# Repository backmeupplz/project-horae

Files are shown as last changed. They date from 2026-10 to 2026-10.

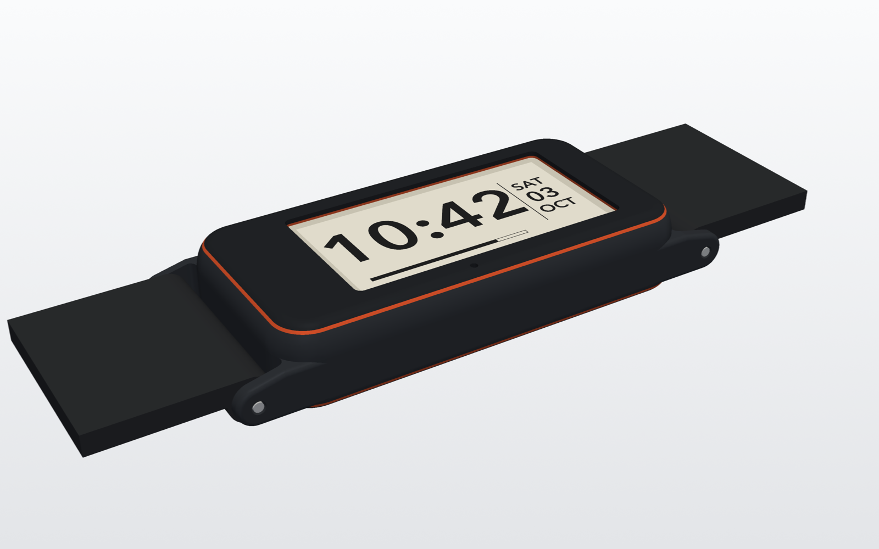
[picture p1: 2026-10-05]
media/2026-10-04/cad-assembled.png

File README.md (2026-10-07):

# Project Horae

A miniaturized successor to [Watchy](https://watchy.sqfmi.com/), the open-source ESP32 e-paper watch. It's rebuilt as thin as possible, in a slim band form factor (think Fitbit Charge, not a square).

Build log: **[projecthorae.com](https://projecthorae.com)**

## Build one
- [ORDER.md](ORDER.md): the JLCPCB order (files and every order-form setting), the shopping list with Canadian sources, and the totals
- [ASSEMBLY.md](ASSEMBLY.md): printing, a test-print checklist, bench bring-up, assembly, the dock wiring, and the firmware rules the hardware depends on
- [hardware/README.md](hardware/README.md): the board design, the pre-order review, what to verify at bring-up, and the cost

## Research
- [Displays](research/displays.md): bar-shaped e-paper and memory LCD panels
- [Batteries](research/batteries.md): thin LiPo, sodium-ion reality check, power budget
- [Electronics](research/electronics.md): EDA tools, fabs shipping to Vancouver, key ICs
- [CAD & printing](research/cad-tools.md): code-CAD and the headless Bambu A1 mini pipeline
- [Prototype v0](research/prototyping.md): breadboard kit, steps, charging
- [Build plan, rev A](research/build-plan.md): custom board straight away, order → solder → firmware → case → wear

## 3D explorer
The landing page's interactive model (`explorer/`) is generated from the case CAD and the KiCad board:
`.venv/bin/python cad/web.py` (needs Docker for KiCad and `npx` for gltf-transform). Re-run it after changing the CAD or the board.

## Printing (Bambu A1 mini, 0.4 nozzle, one filament per job)
- `cad/out/plates/petg.3mf`: both shells plus the dock's tray and lid, in PETG Basic or Matte. Use 0.1 mm layers **and a 0.1 mm first layer** (it is the skin over the watch's magnets), no supports.
- `cad/out/plates/tpu.3mf`: every seal and cushion plus the dock's grip pad, in TPU 90A (not 95A: twice as stiff) from the external spool, printed slowly. Give the bezel gasket 0.08 mm layers.
- Carbon-fibre version: print `petg-cf.3mf` (PETG-CF, hardened nozzle) and `petg-cf-set.3mf` (the colour-matched PETG parts) instead of `petg.3mf`.
- Per-part notes (orientation, layer heights, squeeze) are in `PRINT` in `cad/horae.py`, and a full `.venv/bin/python cad/horae.py` run prints them.

## Adding a timeline entry
The timeline is newest first. Add a new `<li class="entry">` block at the top of the `<ol class="timeline">` in `index.html`, and put its photos in `media/YYYY-MM-DD/`.

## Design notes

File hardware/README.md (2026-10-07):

# Horae rev A hardware

ESP32-S3 band watch board: **33.6 × 16.0 × 0.6 mm, 4 layers**. JLCPCB assembles it (Standard PCBA, top side only) in a
1-up 70 × 70 mm frame.
- **Case:** 35.6 × 18.0 × 6.80 mm, smaller than a Fitbit Charge 3 (38 × 18.3 × 11.8) in every direction. Two PETG shells
  click together with no glue (see `../cad/horae.py`).
- **Board fit:** the board sits 0.2 mm off every cavity wall, because JLC routes outlines to ±0.2 mm. Six crush ribs in the
  case centre it.

**Status (2026-10-06): pre-order review done, not ordered.**
- **Review:** four parallel reviews (schematic and parts, layout and fab files, size, sourcing) found 7 blockers. All are
  fixed and listed below.
- **Checks:** ERC 0. DRC 0 errors, 0 warnings, 0 unconnected. A probe of JLC's multilayer limits is clean: minimum
  clearance 0.110, track 0.100, hole-to-copper 0.235, copper-to-edge 0.201 mm.
- **Reproducible:** a fresh build gives the same board and CPL byte for byte.
- **Ordering:** [../ORDER.md](../ORDER.md). **Assembly and bring-up:** [../ASSEMBLY.md](../ASSEMBLY.md).

Everything here is generated from two files:
- [`design.py`](design.py), the netlist
- [`../spec.py`](../spec.py), the shared dimensions

## Rebuild
```sh
./build.sh       # ~6 min: schematic, ERC, placement, staged Freerouting, pours, DRC, STEP, gerbers, BOM/CPL, panel, renders
python3 cost.py  # live JLC parts (with JLC's attrition/minimums) + Standard PCBA fees -> out/cost.json; `cost.py 5` for 5 boards
```
It needs:
- Docker: it runs KiCad 10 from the official `kicad/kicad:10.0` image through `./kicad`.
- A Java 25 runtime.
- The Freerouting 2.4.1 jar in `~/.local`.

| File | What |
|---|---|
| `design.py` | parts, LCSC numbers, pin-to-net map |
| `gen_sch.py` | writes `horae.kicad_sch` (symbols joined by net labels) |
| `gen_pcb.py` | outline, stack, pinned and legalized placement (the build fails on any drift over 1 mm), net classes, keep-outs; exports the Specctra DSN |
| `stage.py`, `dsn_only.py`, `sesfix.py` | staged routing: touch first, then the e-paper bus, then the rest; deterministic (seeded UUIDs, one router thread) |
| `route.py` | imports the Freerouting session, pours GND, adds stitching and the RF via fence, removes unused escape vias |
| `fab.py` | `out/jlc-bom.csv` and `out/jlc-cpl.csv` (gerber coordinates, JLC rotation offsets) |
| `panel.py` | the 70 × 70 mm frame: `out/panel-gerbers.zip`, `out/jlc-cpl-panel.csv`, `out/panel-top.png` |
| `cost.py` | JLC cost estimate from the BOM |
| `lib/` | symbols, footprints and 3D models: LCSC-imported, TI/Espressif land patterns, Watchy's antenna |
| `rf/` | openEMS antenna model and match fitting |
| `out/` | schematic PDF, STEP, gerbers, BOM, CPL, panel, ERC/DRC reports, renders |

## Design summary
- **MCU:** ESP32-S3FN8 (8 MB in-package flash).
  - 40 MHz KYX crystal (12 pF, ±10 ppm) with Espressif's 24 nH series L on XTAL_P.
  - The exposed pad follows Espressif's land pattern: solid copper, nine 1.0 mm mask windows, 12 vias in the mask webs,
    and no vias in the paste.
  - **Timekeeping:** a 32.768 kHz crystal on GPIO15/16 drives the ESP32's own RTC, as on Watchy v3 and Yatchy, so there's
    no RTC chip. ±20 ppm is about 1 min/month before the phone sync corrects it. All four crystal load caps are 18 pF C0G.
  - **Antenna:** Watchy's meander IFA, trimmed 6.64 mm, ending 0.35 mm from the board edge. It is fed by a 50 Ω GCPW
    (0.15 mm track, 0.15 mm gap). Match **C11 0.5 pF / L3 0.8 nH**; C12 is not fitted and is the spare tuning spot.
  - **Antenna simulation (v4, this board):** S11 across 2.40–2.48 GHz is −8.8 to −14.2 dB in the case and −8.6 to
    −13.6 dB on the wrist, with a worst in-band loss of 0.78 dB.
  - The re-layout put ground closer to the feed, which lowered the resonance 0.6–0.8 %. So L3 went from 1.2 to 0.8 nH,
    the most robust match across JLC's parts. `rf/results/report_v4_trim6.64.txt` has the details.
- **Power:**
  - **Pogo pads:** 4 on the bottom for the charging/USB dock, whose spring pins reach them through the case floor. They are
    VBUS + D− on one side and GND + D+ on the other. ST's USBLC6-2P6 sits flow-through between the pads and the ESP32.
  - **TI BQ25101** linear charger (1.6 × 0.9 mm WCSP):
    - charges at 20 mA (6.8 kΩ ISET, 0.5C for a 40 mAh cell), with TI's ISET RC (2.7 kΩ + 10 nF) for currents under
      50 mA;
    - 4.7 µF/25 V on IN and 1 µF on OUT, both at the chip;
    - ≤ 75 nA battery drain.
    - The IN pin is rated 30 V, but the USBLC6 clamps VBUS from about 6 V, so the input is 5 V only.
  - **TI TPS62840** buck:
    - 60 nA quiescent, 3.3 V set by a 267 kΩ VSET resistor (TI's window is 256–278 kΩ);
    - 2.2 µH LSCND1608 inductor (1.3 A saturation, 0.2 Ω, 0.8 mm).
  - **Battery voltage:** a 10 MΩ / 10 MΩ ±1 % divider (0.2 µA) with 100 nF at the ADC. Calibrate each board at the
    4.20 V end of charge.
  - **Soldered parts:** the battery goes to a **square + pad (TP5)** and a **round − pad (TP6)** on the bottom; the motor
    to 1.5 mm pads.
- **Sensors:** ST LIS2DUX12 accelerometer (pedometer at 2.7 µA, tap, wake-up, 6D, ML core).
  - **I²C:** address **0x19**, on GPIO8 (SDA) / GPIO9 (SCL) with the ESP32's internal pull-ups, so 100 kHz.
  - **Interrupts:** INT1/INT2 on GPIO10/11.
  - **Layout:** nothing on any layer under it (ST TN0018).
- **Display:** GDEM0097T61 into a Hirose FH34SRJ-18S.
  - **Connector:** its slot and fitting nails face the ribbon's U-bend at −X, and **pad = 19 − display pin**.
  - **Booster:** Good Display's reference (p.20) in tiny packages:
    - 47 µH Sunlord SWPA3010S (3 × 3 × 1.0 mm) with 10 µF at its input;
    - Nexperia PMZ390UN switch (30 V);
    - 3× Nexperia PMEG3002AEL Schottky (30 V, about 6× less leakage than the PMEG3005EL);
    - 2.2 Ω sense;
    - 2.2 µF/25 V on the ±15–20 V rails (0402 parts lose about 90 % of their capacitance there) and 1 µF/25 V on the rest.
- **Touch:** 4 capacitive electrodes (4.0 × 1.6 mm) along the long edges, on touch channels GPIO1–4, each through a
  510 Ω series resistor at the chip. No buttons.
  - On every layer, no other trace and no ground pour come within 0.5 mm of an electrode.
  - The electrodes are well below Espressif's recommended size (8 mm+), so measure raw counts in the closed case first
    (bring-up checks).
- **Haptics:** 6 mm coin ERM (Vybronics VC0625B001L, 2.5 mm, 10 mm leads) on a PMZ390UN low-side switch, with a
  PMEG3002AEL flyback diode. It is rated 2.5 V, so firmware drives it with PWM.
- **Mic:** LMD2718T261 top-port PDM mic: DATA on GPIO38, CLK on GPIO39, and powered from GPIO40 (0 µA when off).
  - The ROM drives GPIO40 high in USB-OTG download mode, so it may only be the mic's supply.
  - Burn `DIS_USB_OTG_DOWNLOAD_MODE` at the first flash.
- **Height:** the tallest parts are J1 (1.0 mm, 1.1 max) and L4 (1.0 mm). Then come the mic (0.9, 1.0 max), the ESP32
  (0.885), L5 (0.8) and the accelerometer (0.74). The display sits 1.05 mm above the board.

### GPIO plan
| Side of U1 | GPIO | Use |
|---|---|---|
| facing the antenna (pins 6–14) | 1, 2, 3, 4 | touch DOWN, BACK, MENU, UP (each through 510 Ω) |
| | 5 | vibration motor (PWM) |
| | 6 | charger CHG (open drain, low = charging: wakes the watch on the dock) |
| | 7 | battery ADC (ADC1 channel 6) |
| | 8, 9 | I²C SDA, SCL (accelerometer, 0x19) |
| facing the display connector (pins 15–27) | 10, 11 | accelerometer INT1, INT2 |
| | 12, 13, 14, 17, 18, 21 | display BUSY, RES, DC, CS, SCK, MOSI |
| | 15, 16 | 32.768 kHz crystal |
| | 19, 20 | USB D−, D+ (dock pads, through the USBLC6) |
| bottom (pins 43–45) | 38, 39, 40 | mic DATA, CLK, power |
| test pads (bottom) | 0, 43, 44, EN, 3.3 V | BOOT, TXD0, RXD0, reset, supply |

Every display, I²C, touch and wake line is on an RTC GPIO (0–21), so the ULP core can redraw the minutes without waking
the main CPU (Yatchy's biggest battery win). The ULP bit-bangs I²C: its hardware I²C pins are GPIO0–3.

## Pre-order review (2026-10-06): what changed
- **Blockers fixed:**
  - **J1 faced the wrong way.** The FH34SRJ's slot is on the fitting-nail side, so the ribbon couldn't reach it. J1 is
    turned around with its pins remapped. It also moved 1.7 mm toward +X, because Good Display's bend rule (R > 0.5 mm)
    with the 11.18 mm tail needs that much room.
  - **CPL:** it was relative to the board centre, while the gerbers use absolute coordinates, so every part would have
    landed about 141 mm off. U4 also needed a rotation offset; the CPL now has offsets for U4 and L4.
  - **WCSP lands:** the U2/U3 ball pads (0.185–0.2 mm, mask = pad) were below JLC's minimum. They are now TI's 0.23 mm
    NSMD lands with 0.25 mm square paste.
  - **Touch:** foreign traces ran under the electrodes on the inner and bottom layers.
  - **RF:** the RF match pads were 0.07 mm apart, which would merge the solder mask and tombstone L3.
  - **Thermal vias:** the ESP32's exposed pad had open vias inside the paste.
  - **Panel:** JLC Standard PCBA needs a panel of at least 70 × 70 mm. JLC's own 2 × 4 panel would have meant paying for
    16 assembled boards, so `panel.py` makes a 1-up frame.
- **Should-fix items done:**
  - **Vias:** all are now 0.45/0.2 mm. 0.4 mm pads cost about $36 more per order and triggered 4-wire testing.
  - **Supplies:** 0.2–0.3 mm traces; VDD3P3 on the top layer with no vias.
  - **Decoupling:** every cap within 1 mm of its pin, with new caps at VDD3P3_CPU, VDDA, the booster input and the charger
    output.
  - **Crystals:** on the top layer at their pins, with nothing underneath.
  - **USB ESD:** flow-through.
  - **Mic:** its pins are swapped so the ROM can't back-drive it during flashing.
  - **Lower-leakage diodes, and rail caps that keep their value at 20 V.**
  - **Genuine ST USBLC6.**
  - **Parts with better stock:** the original Sunlord inductor, plus ±1 % 10 MΩ and 510 Ω resistors with no 6,000-piece
    minimums.
  - **Silkscreen:** pin-1 and cathode marks for JLC's placement check.
  - **Paste:** reduced on the FPC connector. Thermal spokes on the non-critical 0201s against tombstoning.

## Verify at bring-up
1. **RF:** the in-case and on-wrist responses sit about 100 MHz apart, so a ±3 % resonance error costs about 4 dB at one
   band edge.
   - The steel spring bar is part of the antenna's environment. Keep it within ±1 mm of 2.15 mm past the case end, or
     re-run `rf/`.
   - Verify on the first boards with a VNA through a pigtail at the C11 pad (cut the trace to U1). Close the case and
     measure with the strap on, off and on a wrist, then retune C11/L3; C12 is the spare.
   - A bare board always reads high, so test it in the case.
2. **Touch:** read raw counts and noise in the closed case before relying on touch as the only input.
3. **Booster:** SSD1680's current-sense trip on RESE isn't published, so L4's saturation margin (0.22 A rated, 0.35 A
   typical) is unknown. Probe RESE (current = V / 2.2 Ω) and watch the VGH ramp.
4. **Crystals:**
   - The 40 MHz must be within ±10 ppm: trim C1/C2 with a TX tone if not.
   - Check that the 32 kHz crystal starts. Its 70 kΩ resistance is at Espressif's limit, and the firmware falls back to
     the internal RC clock.
5. **Charger:** it can't run the board without a cell, and its 10-hour timer stops charging if the watch stays awake on
   the dock. Bring the board up from a bench supply on TP5/TP6, and deep-sleep while docked.
6. **JLC preview:** order with "Confirm Parts Placement" and check every pin-1 dot and cathode bar against the
   silkscreen, especially U1–U4, U6, J1, Q1/Q2, D1–D4, MIC1 and Y1.
7. **Recovery without buttons:** EN, BOOT (GPIO0), TXD0/RXD0 and 3.3 V are on bottom test pads, and USB is on the dock
   pads.

## Cost (JLC Standard PCBA, live 2026-10-06; `python3 cost.py`)
| Item (USD) | 2 boards | 5 boards |
|---|---|---|
| Bare PCB: 5 frames, 4 layers, 0.6 mm, ENIG, JLC04061H-3313 stack-up (impedance control not needed), 0.45/0.2 vias, plugged | 46.20 | 46.20 |
| PCBA setup 25.56 + stencil 8.21 + 33 feeders × 1.53 + fixtures 16.42 + X-ray + placement confirmation and packing | 118.03 | 122.13 |
| Parts, with JLC's attrition and minimum quantities | 30.42 | 62.93 |
| Joints (about 230 per board × $0.0016) | ~0.75 | ~1.85 |
| **Subtotal** | **≈ 195** | **≈ 233** |
| DHL Express (2–4 business days); Global Standard is capped at $99 orders | 31.23 | 31.23 |

- **Import:** duty 0 % (HS 8534.00.00). GST + BC PST 12 % is collected at delivery, plus DHL's CAD 18 clearance fee.
  There is no DDP option for Canada.
- **Fees:** on Standard PCBA every BOM line pays the $1.53 feeder fee, basic or extended alike. JLC has no basic or
  preferred 0201 parts, so swapping parts for basic ones saves nothing here; only fewer lines do.
- **Pre-buy the ESP32-S3FN8:** JLC has 602 in stock and 0 at LCSC. Buy 5–10 into your JLC parts inventory before
  ordering.

## Battery and motor (bought separately, soldered: 4 joints)
- **Cell:** a 3.0 mm LiPo with protection (PCM), at most 21.4 × 16.0 × 3.25 mm including the PCM. The PCM end may be up
  to 3.5 thick and 2.5 long.
  - Buy cells no thicker than 3.05 mm, and measure them on arrival: thickness tolerance is often ±0.3.
  - Real capacity in this pocket is **40–55 mAh** (301518 / 301519 / 301520 class).
  - They ship with two bare wire leads (no plug): trim them, then red to + and black to −.
  - **Thinner option:** a bare 2.5 mm cell (LP251320, 40 mAh, buyable at quantity 1) would make the case 6.30 mm. It would
    need cell protection on the board and an RF retune.
- **Motor:** Vybronics VC0625B001L, a 6 × 2.5 mm brushed coin ERM with 10 mm leads (Digi-Key 1670-VC0625B001L-ND). No
  6 mm motor with spring contacts exists off the shelf.
- **Why not a plug:** a JST SH socket, the plug and its lead slack need about 2 mm more case length, and the board's bottom
  side would need assembly too. Two pads take seconds to solder.

## Charging dock (bought parts; the tray, lid and grip pad print with the case)
- **Spring pins:** 4 Mill-Max 0955-0-15-20-71-14-11-0 (plus 2 spares). Docked, each presses about 42 g on its pad.
- **Magnets:** 4 × 3 × 3 mm N52 in the dock; the case holds 2 × 3 × 1 mm N52.
  - Placed end for end, the watch is pushed off, so VBUS never lands on GND.
  - They hold 1.9× the pins' spring force.
  - The case's magnets click into the bottom shell from the inside, behind a 0.1 mm skin, so lifting the watch off can't
    pull them out.
- **USB-C:** [Adafruit 6050](https://www.adafruit.com/product/6050) sunken breakout. Its 5.1 kΩ CC pull-downs make any
  USB-C charger give 5 V, and D+/D− are broken out for flashing.
- **Wire:** 2–3 cm each of 30 AWG for VBUS, GND, D+ and D− (twist D+ with D−). These 4 wires are the dock's only soldering.
  Wiring table: [../ASSEMBLY.md](../ASSEMBLY.md).

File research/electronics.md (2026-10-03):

# Electronics: EDA, fabs, key ICs

_Researched 2026-10-03. Items marked "unverified" still need a check._

## Starting point: Watchy's KiCad files
Watchy's hardware lives in **[sqfmi/watchy-hardware](https://github.com/sqfmi/watchy-hardware)** (MIT), not in the firmware repo `sqfmi/Watchy`.
- **Format:** KiCad 7. KiCad 10 opens it fine.
- **Board:** 4 layers.
- **Contents:** STEP models, gerbers, BOM.
- **v3 BOM:**
  - Bare ESP32-S3 (QFN56), 32 kHz crystal, PCB antenna
  - BMA423 accelerometer, TP4054 charger, RT9080 LDO
  - Micro-USB, pager motor
  - No external RTC IC

## EDA tools an agent can drive
| Tool | License | Scriptable | Headless render | Maturity |
|---|---|---|---|---|
| **KiCad 10** + `kicad-cli` | GPL | Runs ERC/DRC (JSON), gerbers, drill, pick-and-place, BOM, STEP and SVG. Project files are plain-text S-expressions an agent can edit. | ✅ `kicad-cli pcb render` | Production |
| KiCad IPC API | GPL/MIT | Needs the GUI running. Headless use arrives in KiCad 11. | ❌ | Early |
| [atopile](https://pypi.org/p/atopile) | MIT | `.ato` language that picks JLC parts and generates the KiCad PCB | via KiCad | Pre-1.0 |
| [tscircuit](https://docs.tscircuit.com/) | MIT | React/TS with a built-in autorouter. Exports a KiCad project. | ✅ | Unstable |
| [SKiDL](https://pypi.org/project/skidl/) | MIT | Python netlists only. KiCad 10 support unverified. | ❌ | Stable, narrow |
| [Freerouting](https://github.com/freerouting/freerouting/) | GPL | `java -jar freerouting.jar -de board.dsn -do board.ses` | ❌ | Mature |
| Quilter | SaaS | Upload KiCad, get AI layout back. Web only. | ❌ | Unproven on RF |
| Flux.ai / EasyEDA Pro / JITX | SaaS / freeware / commercial | Browser-bound or unclear | ❌ | Wrong fit |

## Fabs that ship to Vancouver
| Fab | Thin rigid | Flex / rigid-flex | HDI / fine pitch | Assembly |
|---|---|---|---|---|
| **[JLCPCB](https://jlcpcb.com/capabilities/pcb-capabilities)** | 2-layer 0.4 mm. 4-layer: 0.8 mm listed, 0.6 mm reportedly possible (unverified). | Flex: 1–2 layers, from $2–25 per 5. No rigid-flex online. | 1–3 step HDI, via-in-pad, 01005, 0.35 mm pitch | Standard PCBA needs a 70×70 mm panel |
| **PCBWay** | 0.4 mm+ | Flex and **rigid-flex** | ✅ | ✅ |
| NextPCB | ✅ | Flex and rigid-flex | ✅ | Free PCBA promo for 1–10 pcs |
| Elecrow / Seeed Fusion | ✅ | Flex and rigid-flex | limited | Slower (7–25 days) |
| OSH Park (US) | 4-layer only at 1.6 mm | Flex suspended | ❌ | ❌ |
| Candor (Toronto) | ✅ | Rigid-flex, HDI | ✅ | Partners. Premium price |
| Bittele/7pcb (Markham) | partners | partners | ✅ | Turnkey, ~6 days |

**Estimated cost:** 5 assembled small 4-layer boards at JLC come to **≈ USD 60–150** before shipping. Shipping is DHL, 3–6 days, ~$20–35. (Estimate, not a quote.)

**Import costs into BC (2026):**
- Tax: PCBs aren't on Canada's China surtax list ([SOR/2024-187](https://laws-lois.justice.gc.ca/eng/regulations/SOR-2024-187/page-1.html)). Expect **GST 5% + PST 7%** plus brokerage.
- Brokerage: DHL charges about CAD $10–20.
- De minimis from China is only about CAD $20, so assume every order is taxed. JLC's DHL DDP option roughly breaks even.
- US shipments (OSH Park) are tax-free under CAD $40 thanks to CUSMA.

## Key ICs
| | ESP32-S3 | ESP32-C6 | nRF52840 | nRF54L15 |
|---|---|---|---|---|
| Sleep | ~7 µA deep sleep (14+ µA on real boards) | ~7 µA | 2.35 µA System ON | 2.9 µA ON / 0.7 µA OFF |
| Radio | Wi-Fi 4 + BLE 5 | Wi-Fi 6 + BLE 5 + 802.15.4 | BLE 5, Thread | BLE 6, Thread |
| Smallest module | S3-MINI-1 15.4×20.5×2.4 | C6-MINI-1 13.2×16.6×2.4 | MDBT50Q 10.5×15.5×2.05 | **Fanstel BC15P 6.0×6.5×2.0** |
| Watchy firmware | ✅ | mostly | ❌ rewrite | ❌ rewrite (Zephyr) |

- **RTC:** RV-3028-C7 (~45 nA), only if the internal RTC drifts too much.
- **Accelerometer:** BMA423 or BMA456 (both have a pedometer). LIS2DW12 draws less but has no pedometer.
- **Charger / PMIC:** TP4054 (simplest), BQ25125 (wearable PMIC), nPM1300 (pairs with nRF).
- **Haptics:** coin ERM motor plus a MOSFET, or DRV2605L plus an LRA.

## Recommendation
1. **EDA:** fork `watchy-hardware` into KiCad 10.
   - The agent edits the S-expression files directly.
   - A Makefile runs `kicad-cli` for ERC/DRC, renders, STEP and fab outputs.
   - Freerouting handles non-RF nets.
2. **Fab:** JLCPCB, 4-layer at 0.6–0.8 mm, Standard PCBA, panelized, shipped by DHL. Get rigid-flex quotes from PCBWay or NextPCB once the design settles.
3. **ICs:** v1 keeps the bare ESP32-S3, which is the lowest risk because it reuses the schematic, RF section and firmware. Evaluate an nRF54L15 module for v2.

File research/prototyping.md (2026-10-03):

# Prototype v0: no factory

_Planned 2026-10-03. Prices are approximate, in USD._

Goal: get every function working on the desk first, using off-the-shelf boards and hand wiring. We miniaturize the PCB once the behaviour is right.

## Step 0: the Watchy we already have
The Watchy is already a working ESP32 + e-paper + accelerometer board. Use it for firmware experiments while the parts ship.

## Step 1: XIAO carrier PCB, hand-soldered
Skip the breadboard. Design a small 2-layer carrier board in KiCad, about 25×40 mm, with:
- castellated pads for a XIAO module. ESP32S3 and nRF52840 Sense share a footprint, so the chip decision becomes a module swap.
- the 0.97" display's FPC connector plus its booster circuit, using the Watchy / Good Display reference design.
- 4 buttons, a motor MOSFET, and LiPo pads.

Every part is hand-solderable: 0603/0805 passives, SOT-23, a 0.5 mm FPC connector (drag-solder with flux), and the castellated module. The Sense's onboard IMU avoids hand-placing a 2×2 mm LGA accelerometer.

Order bare boards from OSH Park (no duty, slow) or JLC (fast). Print a build123d case around the board.

### v0 bill of materials (hand-soldered, 2-layer 0.8 mm carrier)
| Block | Part | Package | Notes |
|---|---|---|---|
| MCU | Seeed [XIAO ESP32S3](https://www.seeedstudio.com/XIAO-ESP32S3-p-5627.html) / [XIAO ESP32C6](https://www.seeedstudio.com/Seeed-Studio-XIAO-ESP32C6-p-5884.html) | castellated 21×17.8 | Same footprint, both have Wi-Fi + BLE, so we test both |
| Display | Good Display [GDEM0097T61](https://www.good-display.com/product/486.html) | 30×14.15×1.0, FPC 18p **0.5 mm**, 0.30 mm with stiffener | [datasheet](https://v4.cecdn.yun300.cn/100001_1909185148/GDEM0097T61-V1.1%20new.pdf) |
| Display socket | Hirose **FH34SRJ-18S-0.5SH(50)** | 18p 0.5 mm ZIF, **1.0 mm tall**, top+bottom contact | The ribbon plugs in, so we never solder the ribbon itself |
| E-paper booster | Q1 AO3400A (Watchy) or Si1308EDL (GD ref), D1–D3 MBR0530, L1 47 µH ≤1.2 mm ([PNLS3012-470M](https://jlcpcb.com/partdetail/DMBJ-PNLS3012470/C2849443) or Murata LQH3NPN470NJ0L), R1 1 MΩ, R2 2.2 Ω, 7× 1 µF/25 V, 2× 4.7 µF/25 V | SOT-23, SOD-123, 3×3, 0603/0805 | Copied from the datasheet's typical circuit (p.20) |
| RTC | NXP PCF8563T + 32.768 kHz crystal (hand-solder) or RV-3028-C7 (better, needs hot air) | SO-8 / 3.2×1.5 | The XIAO's internal RC clock is too inaccurate for a watch (verify whether a 32 kHz crystal is fitted) |
| Accelerometer | Bosch BMA423 (same as Watchy) | LGA-12 2×2 | Can't be soldered with an iron: use hot air or a hot plate, or have JLC place just this part. Optional in v0 |
| Buttons | 4× Panasonic EVQ-PUC02K (same as Watchy) | side-push, 1.35 mm tall | – |
| Haptics | 8 mm coin ERM motor + AO3400A + diode | – | – |
| Battery | 3.7 V LiPo **301525** (~3×15×25, ~110 mAh) with PCM | soldered leads | 15 mm wide, narrower than the XIAO |
| Power | 47–100 µF bulk cap at the battery, 2× 1 MΩ divider for battery voltage | 1206 / 0603 | Wi-Fi bursts draw ~300 mA from a tiny cell |
| Power meter | [Nordic PPK2](https://www.nordicsemi.com/Products/Development-hardware/Power-Profiler-Kit-2) | – | Optional, ~$100 |

### Size estimates
| | L × W × T (mm) | What sets each dimension |
|---|---|---|
| [Fitbit Charge 6](https://store.google.com/product/fitbit_charge_6_specs) | 36.7 × 23.1 × 11.2 | target |
| **v0** XIAO carrier | **~40 × 21 × 10–11** | L: display + walls + USB-C. W: XIAO 17.8 + walls. T: 0.6 lip + 1.0 display + ~2.6 XIAO (USB-C end ~4.3, unverified) + 0.8 PCB + 3.3 battery + 1.0 floor |
| **v1** custom 4-layer, bare ESP32-S3/C6 | **~34 × 18 × 7** | L: 30 mm display + walls + antenna keep-out. T: 0.6 + 1.0 + 1.2 tallest part + 0.8 PCB + 2.6 battery (2.4 mm cell + swelling) + 0.8 |
| v1 with nRF54L15 (no Wi-Fi) | ~32 × 17 × 6 | same, with a ~1.5 mm, 50 mAh cell |

## Step 2–3: iterate
Revise the board and case together until everything works and fits on a wrist.

## Step 4: miniaturize
Make a custom 4-layer board with a bare chip and factory assembly. This is the expensive step, so it waits until v0 works.

## Charging
- **Prototype:** the XIAO's own USB-C.
- **Final watch:** a 4-pin magnetic pogo connector on the back (5V, GND, D+, D−). It gives charging *and* USB flashing at zero added height, and both chips have native USB.
- **Why not USB-C:** a USB-C socket is ~3.2 mm tall and ~9 mm wide, so it sets a floor on the case's edge thickness and is an ingress point.

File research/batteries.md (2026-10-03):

# Slim batteries

_Researched 2026-10-03. Power numbers are estimates. Measure them with a PPK2 on the first prototype._

**Bottom line:** use a stock **2.4–3.0 × 20 × 30 mm LiPo pouch, 100–130 mAh**. The MCU choice matters more than the chemistry. **Sodium-ion is not an option yet** (see below).

## Power budget (estimates)
The original Watchy gets 5–7 days on 200 mAh ([docs](https://watchy.sqfmi.com/docs/battery-life)), which works out to about 1.2–1.7 mA average. There is a lot of room to improve.

| | ESP32-S3 | nRF52840 |
|---|---|---|
| Sleep floor (board) | ~15–25 µA | ~5–15 µA |
| Wake every minute | reboots from deep sleep: ~75 µA avg | no reboot: ~2 µA |
| E-paper partial refresh | ~5 µA avg | same |
| BLE sync now and then | ~20–60 µA | ~10–30 µA |
| **Total** | **~3–4 mAh/day** | **~0.6–1.2 mAh/day** |
| 1 week (×1.5–2 margin) | 35–50 mAh | 10–15 mAh |
| 2 weeks | 70–100 mAh | 20–35 mAh |

The ESP32-S3 column assumes well-optimized firmware. Stock Watchy-style firmware draws about 10× more. On the nRF52840, the VDDH pin takes LiPo voltage directly, so no LDO is needed.

## Options
Wh/L is our own calculation: nominal V × mAh ÷ volume.

| Chemistry | Example | mm | mAh | Wh/L | Where | Price |
|---|---|---|---|---|---|---|
| LiPo + PCM | [Adafruit 1317](https://www.adafruit.com/products/1317) | 3.8×19.75×26 | 150 | ~285 | Adafruit / Digi-Key CA | US$5.95 |
| LiPo + PCM | [Adafruit 1570](https://www.adafruit.com/product/1570) | 3.8×11.5×31 | 100 | ~275 | Adafruit | US$5.95 |
| LiPo cell | [EEMB LP302030 / LP242030](https://www.sos.sk/novinky/pdf/2587_eemb-lipol-overview-en-1.pdf) | 3.0 / 2.4×20×30 | 130 / 100 | ~260 | EEMB, Amazon | ~$2–6? |
| Generic LiPo | AliExpress 302030 / 402030 | 3–4×20×30 | 130–200 | ~250–300 | AliExpress | $2–5 |
| Ultra-thin LiPo | [Grepow GRP0849049](https://grepow.com/shaped-battery/ultra-thin-battery.html) | 0.85×49×49 | 140 | ~260 | Grepow samples | ask |
| Ultra-thin LiPo | PowerStream | 0.5–2 thick | ~2 mAh/cm² @0.5 mm | ~150 | powerstream.com | from ~$8 |
| Ceramic Li-ion | NGK EnerCera EC382704P-T | 0.45×38×27 | 27 | ~220 | Japan only | ? |
| Curved LiPo | [Grepow 3020035](https://grepow.com/battery-news/grepow-curve-shaped-lipo-battery-3-8V-200mah-3020035.html) | ~3×20×35 | 200 | ~300 | custom, MOQ | ? |
| Li-ion coin | LIR2032 | Ø20×3.2 | 40 | ~150 | Amazon.ca | ~$2 |
| Thin-film / solid state | TDK CeraCharge, Ilika, ITEN | ~1 thick | 0.1–0.25 | ~10 | samples | only fits RTC backup |
| **Sodium-ion** | 18650 (smallest retail size) | Ø18×65 | ~1500 | 250–375 | B2B | **no wearable cells** |
| Si-C anode | LeydenJar Silyte | ? | ? | 800+ claimed | OEM eval only | n/a |

## Sodium-ion: an honest no
- No thin pouch or coin Na-ion cells are commercially available. Retail starts at 18650 size ([overview](https://en.wikipedia.org/wiki/Sodium-ion_battery)).
- Energy density is lower than LiPo, and packaging overhead would hurt small cells even more.
- Voltage swings from about 4.0 V down to 1.5 V. The ESP32 needs ≥3.0 V, so we'd need a buck-boost converter, which costs quiescent current and board area.
- It needs a charger with a Na-specific 3.9–4.0 V limit, because a 4.2 V Li charger overcharges it.
- Its strengths (cold performance, 0 V storage, grid-scale cost) don't matter on a wrist. Revisit around 2028.

## Other categories
- **Ultra-thin under 1 mm:** real cells, about 260 Wh/L at 0.85 mm. Stock sizes don't fit a band, so it's a custom Grepow order by email.
- **Curved / flexible:** Jenax J.Flex is still at demo stage and Panasonic's flexible cell was never sold at retail. Grepow curved cells are custom-only. Not for v1.
- **Coin cells:** 3.2 mm thick and low capacity, worse than a pouch on every axis.
- **Silicon-carbon:** expect +10–15% capacity per volume once hobby sizes appear.

## Mechanical and charging
- **Swelling:** leave 8–10% of the cell thickness as clearance, about 0.3 mm on a 3 mm cell.
- **PCM:** adds 3–5 mm of length and 1–3 mm of local thickness. We can buy a bare cell instead and put the protector (DW01 / FS312 class) on our PCB. That's thinner, but needs a fuse and careful testing.
- **Charging:** magnetic pogo pins plus a linear charger at ≤0.5C (MCP73831 / BQ25101). Qi adds a coil and ferrite (~1 mm) plus heat, and is oversized at this power level.
- **Shipping:** LiPo ships by ground. Digi-Key CA and Adafruit ship to Vancouver.

## Recommendation
1. **nRF52840 + 100–130 mAh 2.4–3.0 mm cell:** about 3–6 weeks. A ~50 mAh cell 1.5 mm thick would still give about 2 weeks.
2. **ESP32-S3 + the same cell:** about 1–2 weeks, and only with optimized firmware.
3. **Later revision:** a custom Grepow 1.0–1.5 × 22 × 40 mm cell once the enclosure is frozen.

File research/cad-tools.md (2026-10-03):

# CAD tools & print pipeline

_Researched 2026-10-03. Items marked "verify" are unconfirmed._

**Primary stack: [build123d](https://build123d.readthedocs.io/).** It's Python and B-rep, so we get real fillets and STEP output. It imports the KiCad board STEP for interference checks and installs with plain pip. **Fallback: OpenSCAD snapshot (Manifold)** for quick mesh parts and one-line PNG renders.

| Tool | License | Lang | STEP | STL/3MF | KiCad STEP import | Headless PNG | Verdict |
|---|---|---|---|---|---|---|---|
| **build123d** | Apache-2.0 | Python (OCCT) | ✅ | ✅/✅ | ✅ `import_step()` | via pyvista | **Primary** |
| CadQuery 2.5 | Apache-2.0 | Python (OCCT) | ✅ | ✅/✅ | ✅ | via pyvista | Fine, slower releases |
| OpenSCAD snapshot | GPL-2 | DSL | ❌ | ✅/✅ | ❌ (convert to STL) | ✅ built-in | **Fallback** |
| FreeCAD 1.x | LGPL | Python | ✅ | ✅ | ✅ | hard headless | Heavy |
| Zoo / KCL | proprietary, metered | KCL | ✅ | ✅ | verify | cloud | Ideation only |
| Onshape | free = public docs | FeatureScript | ✅ | ✅ | ✅ | API | Cloud-only |
| Fusion 360 | free personal | Python | ✅ | ✅ | ✅ | ❌ no headless | Unsuitable |

Agent tooling worth borrowing: [earthtojake/text-to-cad](https://github.com/earthtojake/text-to-cad) (build123d skills for Claude Code), [build123d-mcp](https://pypi.org/project/build123d-mcp/).

## Install
```sh
python3 -m venv ~/horae-venv && source ~/horae-venv/bin/activate
pip install build123d pyvista
brew install --cask openscad@snapshot kicad bambu-studio
```

## PCB → CAD
```sh
kicad-cli pcb export step --subst-models -o board.step board.kicad_pcb   # --subst-models or bodies go missing
```

## Screenshots of progress
- pyvista: `pv.Plotter(off_screen=True)` → `add_mesh(pv.read("case.stl"))` → `screenshot("view.png")`
- or `openscad -o view.png --render --imgsize=1200,800 view.scad` with `import("case.stl");`

## Slice + print on the A1 mini, headless
```sh
/Applications/BambuStudio.app/Contents/MacOS/BambuStudio --slice 1 --allow-newer-file \
  --load-settings "machine.json;process.json" --load-filaments "pla.json" \
  --export-3mf out.gcode.3mf case.3mf
```
Export the A1 mini preset JSONs from the app once. ([CLI wiki](https://github.com/bambulab/BambuStudio/wiki/Command-Line-Usage))

Send it over LAN with [`bambulabs_api`](https://pypi.org/project/bambulabs-api/): `upload_file()` then `start_print(..., use_ams=False)`. Third-party print commands need **LAN Only Mode + Developer Mode** turned on at the printer ([Bambu wiki](https://wiki.bambulab.com/en/knowledge-sharing/enable-developer-mode)). Developer Mode turns off cloud and the Handy app. Firmware support for the A1 series needs a verify.

## FDM rules for a thin wearable
- **Walls:** 0.8 mm minimum, 1.2–1.6 mm for the case, ≥1.5 mm around snaps. With the 0.2 mm nozzle, ~0.6–0.8 mm walls are possible for the final shell.
- **Tolerances:** 0.2–0.3 mm/side for slip and snap fits, ~0.15 mm for press fits. Print a calibration coupon first.
- **Snaps:** cantilever length ≥5× thickness, with layers along the beam.
- **Orientation:** print flat, display window up.
- **Materials:** PLA for prototypes (softens at ~60 °C), PETG for daily wear, TPU 95A for straps. Skip ASA/ABS on the open A1 mini.
- **Skin contact:** no FDM filament is certified skin-safe. Smooth or coat the back, or add a TPU pad.
- **Clearance:** 0.3–0.5 mm around the PCB envelope, extra around the LiPo for swelling. Support the e-paper glass on a ledge and never clamp its edges.

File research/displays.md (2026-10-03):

# Bar-shaped displays

_Researched 2026-10-03. Items marked "unverified" need a datasheet check before PCB work._

The Fitbit Charge screen is about 1.04". A band about 23 mm wide fits an outline of roughly **30–35 × 14–19 mm**. Anything 2.13" or larger is 59 mm or more long, which is too long.

## Shortlist
1. **[Good Display GDEM0097T61](https://www.good-display.com/product/486.html)**: 0.97" e-paper, 184×88 (2.1:1), 210 ppi, 30.0×14.15×**1.0 mm**, SSD1680, partial refresh in about 0.3 s. **$4.17, in stock** ([buy-lcd](https://www.buy-lcd.com/products/gdem0097t61)). This is the most direct Watchy successor: the same vendor, and a controller family close to Watchy's SSD1681. Downsides: an 18-pin FPC instead of 24 pins, glass, and a small 22×10.6 mm active area.
2. **[Sharp LS011B7DH03](https://www.digikey.com/en/products/detail/sharp-microelectronics/LS011B7DH03/25953418)**: 1.08" memory LCD, 160×68 (2.35:1), 32×14×**0.745 mm**, µW power and fast refresh, so it can animate. This is the most Fitbit-like option. Downsides: sourcing (non-stock, 28-week lead), lower contrast, it needs a VCOM toggle, and it has no GxEPD2 driver.
3. **[GDEW0102I4FC](https://www.good-display.com/product/341.html)**: 1.02" **flexible** e-paper, 128×80 (1.6:1), **0.3 mm** thick and unbreakable, and the GxEPD2_102 driver works with it. Downsides: it is a squatter shape, the 30-pin FPC likely needs ACF bonding (unverified), and its rigid sibling is EOL.

## Comparison
| Part | Type | Res | Outline mm (T) | IC | FPC | Driver | Status |
|---|---|---|---|---|---|---|---|
| **GDEM0097T61** 0.97" | e-paper glass | 184×88 | 30.0×14.15×1.0 | SSD1680 | 18p | adapt GxEPD2 (unverified) | $4.17 in stock |
| GDEW0102T4 1.02" | e-paper glass | 128×80 | 32.57×18.6×0.98 | UC8175 | 30p | GxEPD2_102 | **EOL** |
| **GDEW0102I4FC** 1.02" | e-paper flex | 128×80 | 32.57×18.6×0.3 | UC8175 | 30p ACF? | GxEPD2_102 | active |
| GDEM0213I61 2.13" | e-paper flex | 212×104 | 59.2×29.2×0.44 | SSD1680 | 24p | B74-ish | $8.46, too long |
| **Sharp LS011B7DH03** 1.08" | memory LCD | 160×68 | 32.0×14.0×0.745 | SPI | ~10p? | Adafruit_SharpMem port | 28-wk lead |
| Sharp LS013B7DH05 1.26" | memory LCD | 144×168 | 24.68×30×0.745 | SPI | – | Adafruit | near-square |
| JDI LPM013M126 1.28" | colour MIP | 176×176 | – | SPI | – | Zephyr | square (Bangle.js 2) |
| JDI 0.96" (LPM009M349A?) | colour MIP | 144×72 | ? | SPI | – | hobby | [Tindie](https://www.tindie.com/products/questwise-ventures/ultra-low-power-jdi-096-144x72-color-memory-lcd/), grey market |

Ruled out: GDEM0122T61 and GDEM0189T61 are near-square, and the 1.54" flexible is square. Waveshare, Pervasive, WeAct and Seeed have no bar part under 2".

## E-paper vs memory LCD
- **Power:** both are near zero when static. E-paper holds its image with the power cut. MLCD needs power and a VCOM toggle at about 1 Hz.
- **Thickness:** flexible e-paper is 0.3 mm, MLCD 0.745 mm, glass e-paper 1.0 mm.
- **Contrast:** e-paper is better. MLCD is grey on silver, but still readable in sunlight.
- **Refresh:** MLCD wins clearly, with animation, no ghosting and a better low-temperature range. E-paper takes about 0.3 s to partial-refresh and is rated 0–50 °C.
- **Verdict:** e-paper for a Watchy-style minute tick. MLCD if we want wrist-raise animations and scrolling notifications.

## Front light and touch
Front-lit e-paper only exists at 1.54" and 2.13" (adding about 0.7–0.9 mm). Touch only exists at 1.54" (GDEY0154D67-T03). For a bar, plan side-firing LEDs and a capacitive pad or buttons on the case.

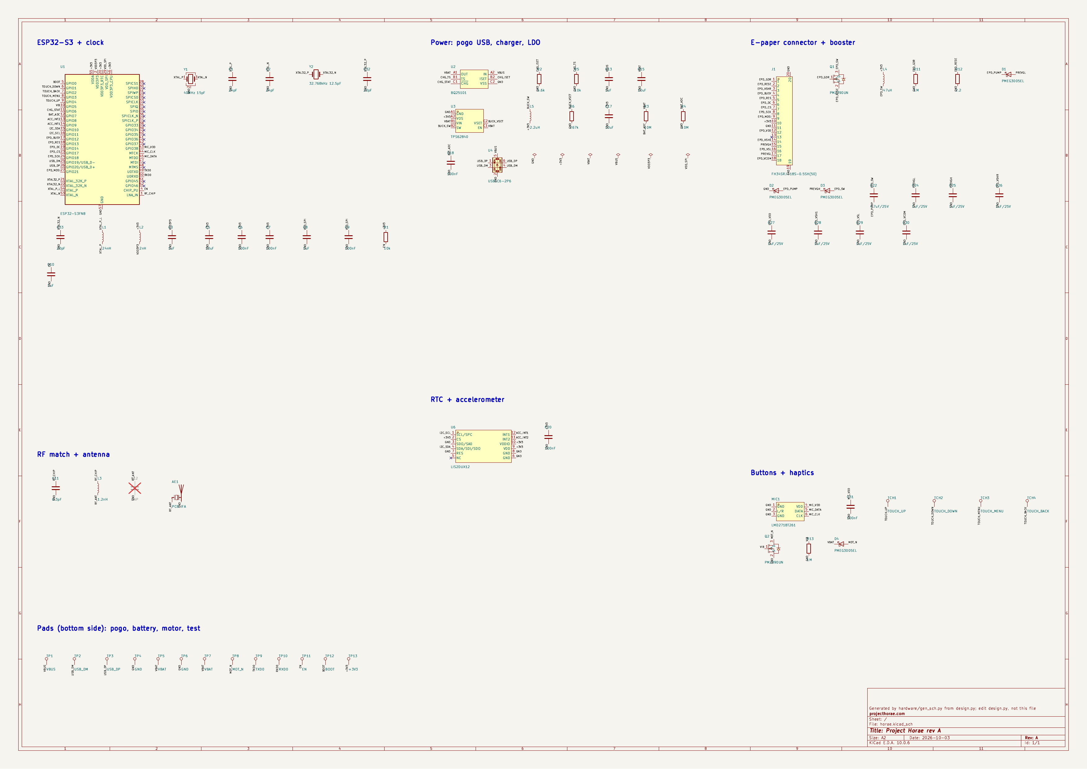
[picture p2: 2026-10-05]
media/2026-10-04/schematic.png

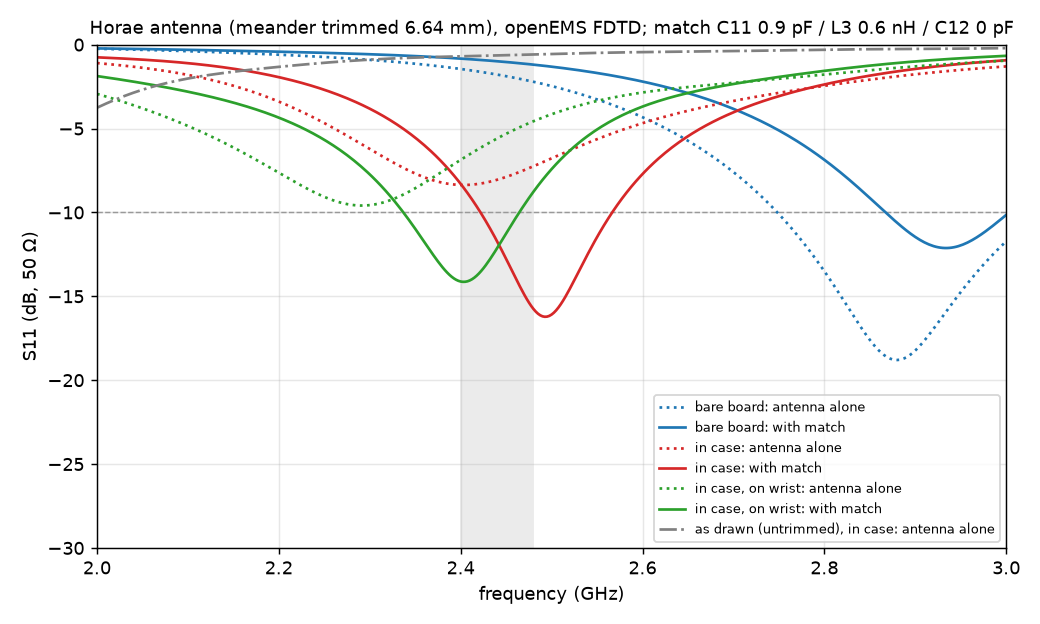
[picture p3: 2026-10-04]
hardware/rf/rf-s11_trim6.64.png

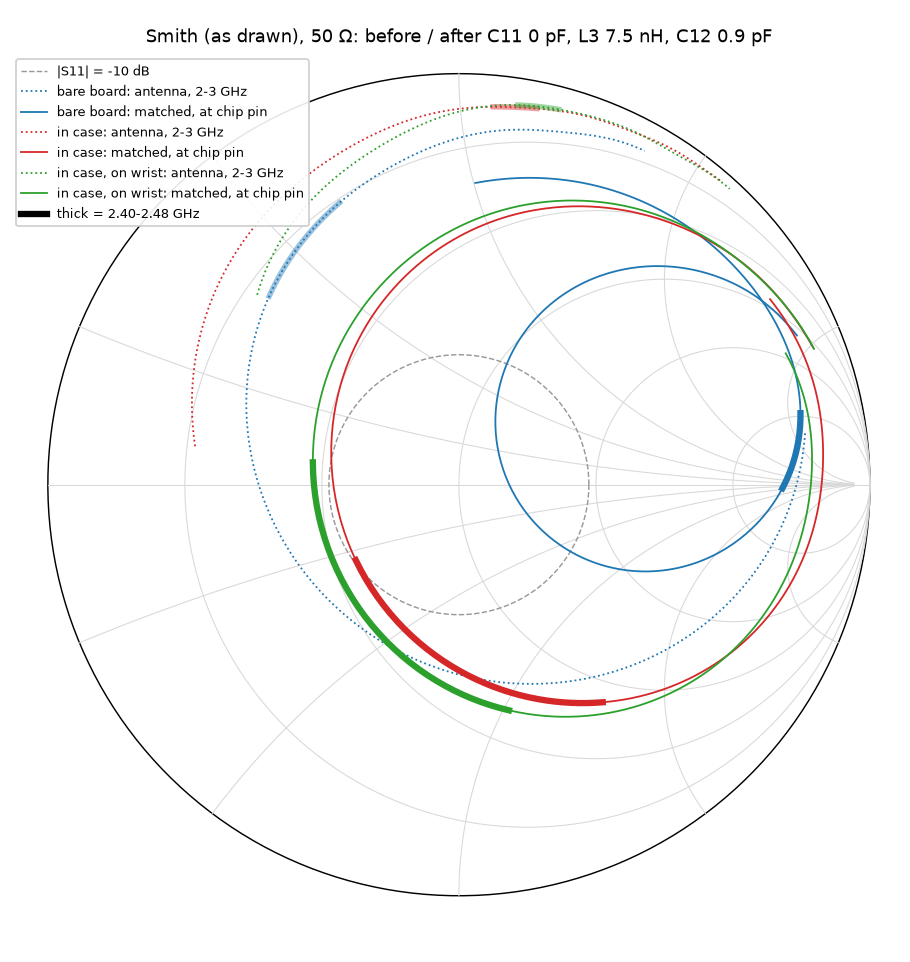
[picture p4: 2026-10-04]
hardware/rf/rf-smith.png

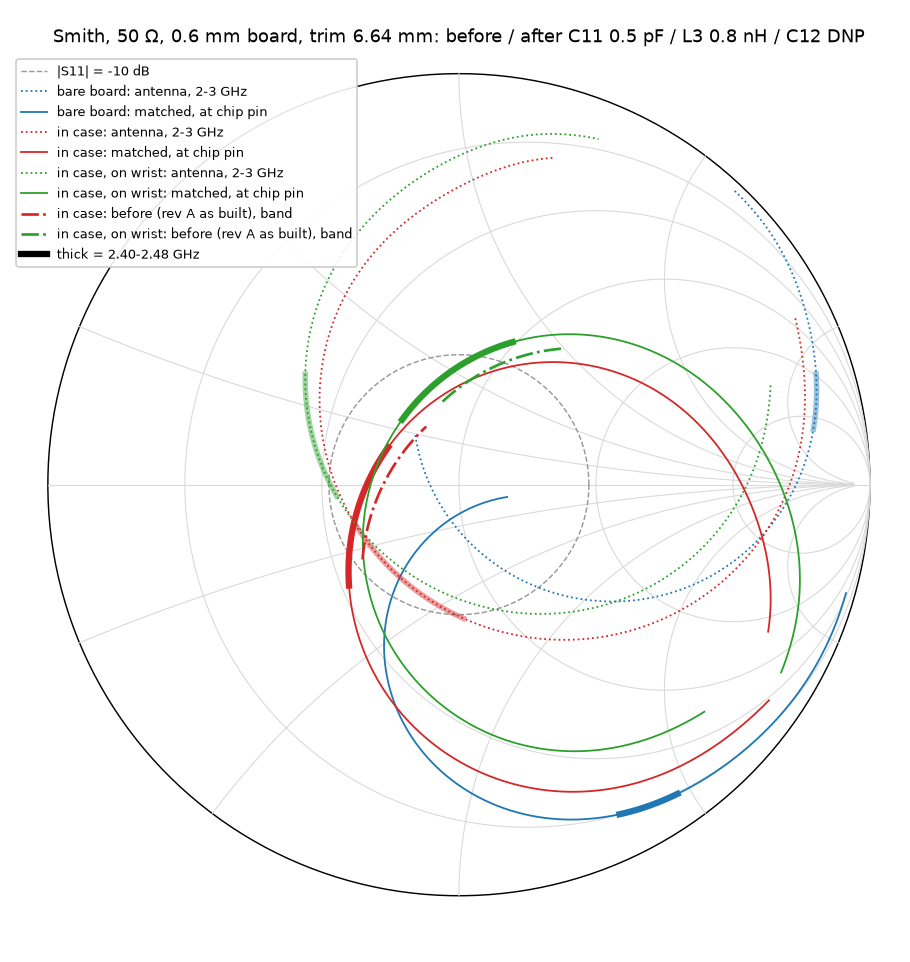
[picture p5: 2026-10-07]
hardware/rf/rf-smith_v4_trim6.64.png

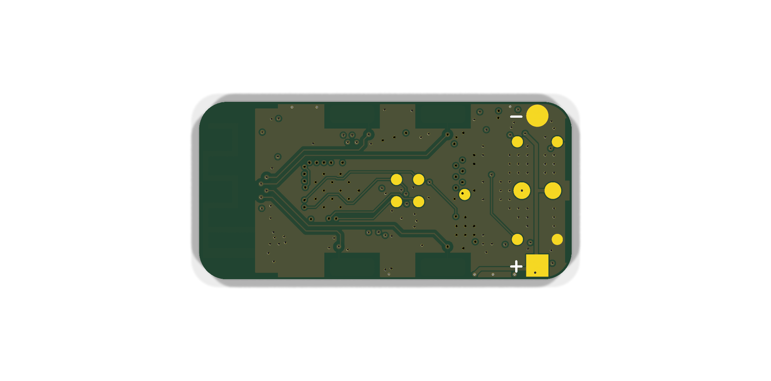
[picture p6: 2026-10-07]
hardware/out/pcb-bottom.png

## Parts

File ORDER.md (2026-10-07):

# Ordering Horae rev A (2 watches + 1 dock)

Prices were checked live on 2026-10-06 for delivery to Vancouver, BC.
- USD → CAD at 1.4254 (Bank of Canada, 2026-10-05).
- "+ tax" means GST 5 % + BC PST 7 %. Digi-Key.ca, Amazon.ca, AliExpress and Bambu CA add it at checkout; courier imports
  collect it at delivery.

Then build it with [ASSEMBLY.md](ASSEMBLY.md).

## Order this first
| When | What | Why |
|---|---|---|
| Today | LiPo cells (AliExpress) | 2–4 weeks on the battery shipping lines: the critical path |
| Today | 5–10 ESP32-S3FN8 into your JLC parts inventory | JLC has 602 and LCSC has 0 |
| By Oct 12 | Displays (buy-lcd) | the US$4.17 sale ends Oct 12; 64 in stock |
| This week | JLC boards | about 2 weeks door to door |
| This week | Digi-Key, Amazon.ca, magnets, filament | 1–10 days; enough for the test print |

## 1. The board: JLCPCB, Standard PCBA, top side only

Files, all in `hardware/out/`:

| Upload | File |
|---|---|
| Gerbers (the 70 × 70 mm frame with one board) | `panel-gerbers.zip` |
| BOM | `jlc-bom.csv` (33 lines, 65 parts) |
| CPL (rotation offsets already applied) | `jlc-cpl-panel.csv` |

Order-form settings:

| Setting | Choose |
|---|---|
| Base material / layers / thickness | FR-4, standard TG, **4 layers, 0.6 mm** |
| Delivery format | **Panel by Customer**: the frame holds one board. Quantity **5** (the minimum), and you assemble 2 or 5 of them. |
| Board size | 70 × 70 mm |
| Surface finish | **ENIG 1 µ"**, needed for the 0.4 mm-pitch WCSPs and the pogo pads |
| Copper | 1 oz outer, 0.5 oz inner |
| Impedance control | **No requirement**, but specify stack-up **JLC04061H-3313**. The RF line is only about 0.05 λ long; without a named stack-up JLC may use a thicker prepreg. |
| Via covering | **Plugged**: no vias sit in pads |
| Min via hole / diameter | 0.3 / (0.4/0.45): the free default. The board's vias are 0.45/0.2. |
| Mask / silkscreen | green / white |
| Mark on PCB | Remove Mark. The frame rail has a "JLCJLCJLCJLC" spot for the order number. |
| Confirm Production File | Yes ($1.05) |
| PCB Assembly | **Standard**, top side, quantity **2** (or 5) |
| Edge rails / fiducials / tooling holes | **Added by customer** |
| Confirm Parts Placement | **Yes** ($0.45). Check every pin-1 dot and cathode bar in the preview: U1–U4, U6, J1, Q1/Q2, D1–D4, MIC1, Y1. |
| Shipping | **DHL Express**. Global Standard is limited to orders of US$99 or less. |

**Cost (USD)** (`hardware/cost.py`; the bare PCB from JLC's live quote):

| | 2 boards | 5 boards |
|---|---|---|
| Bare PCB, 5 frames | 46.20 | 46.20 |
| PCBA fees: setup 25.56, stencil 8.21, 33 feeders × 1.53, fixtures 16.42, X-ray, placement confirmation and packing | 118.03 | 122.13 |
| Parts, with JLC's attrition and minimum quantities | 30.42 | 62.93 |
| Joints | ~0.75 | ~1.85 |
| DHL Express, 2–4 business days | 31.23 | 31.23 |
| **Total** | **≈ 226** | **≈ 264** |
| **Landed (CAD)**, with 12 % tax on the goods and DHL's CAD 18 clearance | **≈ 375** | **≈ 435** |

- Duty is 0 % (HS 8534.00.00). There is no DDP option for Canada.
- X-ray and fixture fees are confirmed only after the BOM/CPL upload.
- 5 boards cost about $13 more each than 2, and a spare saves a 2-week JLC round trip if one dies during assembly.

## 2. Everything else

Each item has an alternative in the [sourcing notes](#alternatives) below.

| # | Item | Buy | Qty | CAD (before tax) | Delivery |
|---|---|---|---|---|---|
| 1 | **Display** Good Display GDEM0097T61, "ePaper Only": 18-pin 0.5 mm FPC, matches J1 pin for pin | [buy-lcd.com](https://www.buy-lcd.com/products/gdem0097t61) | **4** (one spare, one for practising the U-bend) | 23.06 + shipping (Economy US$17.87, DHL US$41.91) | ships in 3 business days; Economy 12–30 days, DHL 2–5 |
| 2 | **LiPo cell** 301520 class with protection and bare red/black leads. **It must measure ≤ 21.4 × 16.0 × 3.25 mm including the PCM; buy ≤ 3.05 mm thick.** | [AliExpress EASYLANDER 5-pack](https://www.aliexpress.com/item/1005009277089856.html) (301520 option, drawing 3 × 15 × 20 ± 2 incl. PCM) | 1 pack of 5 | 16.68 | 2–4 weeks |
| 3 | **Motor** Vybronics VC0625B001L, 6 × 2.5 mm, 10 mm leads | [Digi-Key 1670-VC0625B001L-ND](https://www.digikey.ca/en/products/detail/vybronics-inc/VC0625B001L/1670-VC0625B001L-ND) | 4 | 19.00 | next day; Digi-Key is free from C$100, otherwise C$15; duties included |
| 4 | **Spring pins** Mill-Max 0955-0-15-20-71-14-11-0 | [Digi-Key ED11533-ND](https://www.digikey.ca/en/products/result?keywords=0955-0-15-20-71-14-11-0) | 10 | 15.76 | same Digi-Key order |
| 5 | **USB-C breakout** Adafruit 6050 (the dock is drawn for it) | [Digi-Key 1528-6050-ND](https://www.digikey.ca/en/products/result?keywords=1528-6050-ND) | 2 | 8.84 | same Digi-Key order |
| 6 | **Magnets** 3 × 1 mm N52, **metric** (2 per watch). Imperial 1/8" (3.175 mm) magnets don't fit the 3.05 mm wells. | [AliExpress SZYD, 50 pcs](https://www.aliexpress.com/item/1005010742498039.html) | 1 pack | 7.25 | Oct 15–18 |
| 7 | **Magnets** 3 × 3 mm N52, metric (4 per dock) | the same store, 50 pcs | 1 pack | 9.75 | Oct 15–18 |
| 8 | **30 AWG silicone wire**, red + black | [Amazon.ca BNTECHGO](https://www.amazon.ca/dp/B01M285AUG) | 1 | 8.90 | 1–2 days |
| 9 | **Strap**, 16 mm two-piece with quick-release bars. The ends must be ≤ 3.7 mm thick. | [Amazon.ca Anbeer silicone 16 mm](https://www.amazon.ca/dp/B0C9SRVT2D) | 2 | 33.90 | next day |
| 10 | Spare **spring bars**, 16 × 1.5 mm (optional: the straps include bars) | [Amazon.ca HARFINGTON, 12 pcs](https://www.amazon.ca/dp/B0F9W949YF) | 1 | 7.39 | 1–2 days |
| 11 | **Mic vent:** bare ePTFE film, about 0.25 mm thick, **no adhesive**. You cut a 1.4 × 1.0 mm patch per watch. | [AliExpress ePTFE film, 230 × 260 mm](https://www.aliexpress.com/item/1005001809765077.html) | 1 | 9.08 | 2–3 weeks; the first test print doesn't need it |
| 12 | **PETG** for the shells and dock | [Bambu PETG Basic](https://ca.store.bambulab.com/en/products/petg-basic) or [Matte](https://ca.store.bambulab.com/en/products/petg-matte) | 1 kg | 17.99 (refill) | 1–3 days to dispatch + 3–7 days |
| 13 | **TPU 90A** for the seals, cushions and grip pad. **Not 95A:** it is twice as stiff and overloads the snaps. | [Bambu TPU 90A](https://ca.store.bambulab.com/en/products/tpu-85a-tpu-90a): Black, White, Grape Jelly, Crystal Blue, Cocoa Brown or Quicksilver (or the Blaze/Frozen gradients) | 1 kg | 53.99 | same |
| 14 | PETG-CF + a hardened nozzle (carbon-fibre version only) | [Bambu PETG-CF](https://ca.store.bambulab.com/en/products/petg-cf) + [A1 mini hardened hotend](https://ca.store.bambulab.com/en/products/bambu-hotend-a1-a2) | 1 + 1 | 60.98 | same |
| 15 | Filament dryer, only if you don't have one (TPU must be dried: 70 °C for 8 h) | [SUNLU S2](https://www.amazon.ca/dp/B0FGV3WQ5X) | 1 | 59.49 | 2–8 days |

**Tools** (skip what you own). The full set is C$99 and the lean set C$83:
- Solder (63/37, 0.6 mm) and flux (Chip Quik SMD291).
- A pin vise with a 1.0 mm bit, for the pin bores.
- Nylon spudgers, 10 mm Kapton tape and fine tweezers.
- Isopropyl alcohol.

For bring-up you also need a bench supply with a current limit, in place of the cell (ASSEMBLY.md section 3).

## 3. Totals (CAD, landed)
| Plan | What | Total |
|---|---|---|
| **Cheapest sensible** | 2 boards + displays by Economy + AliExpress cells, magnets and vent + a minimal Digi-Key order + Amazon straps, wire and filament (Amazon SUNLU PETG and Polymaker TPU 90A) | **≈ C$ 640** |
| **Fastest sensible** | 5 boards + displays by DHL + the full Digi-Key order + Amazon.ca Prime for the rest | **≈ C$ 780** |

Add about C$ 90 for tools and C$ 60 for a dryer if needed. You need only about 6 g of PETG and 0.4 g of TPU, so any
spools you already own work.

## 4. Before you press "order"
1. **Rebuild** (`hardware/build.sh`) and check `hardware/out/drc.json` shows 0 / 0 / 0. Upload the panel files, not the
   single-board zip.
2. **Pre-buy the ESP32-S3FN8.**
3. **Placement preview:** JLC's preview must show every part on the board. If parts float off the board, the CPL frame is
   wrong; stop.
4. **Displays:** order them before the Oct 12 sale ends.
5. **On arrival:**
   - measure the cells (≤ 21.4 × 16.0 × 3.25 mm including the PCM, ≤ 3.05 thick is best);
   - measure the strap ends (≤ 3.7 mm);
   - test-fit one magnet in a printed well.

## Alternatives
- **Display:** [AliExpress GooDisplay Official Store](https://www.aliexpress.com/item/1005004146215543.html) (US$6.96), or
  [microhello](https://microhello.com/products/gdem0097t61,097-inch-small-e-ink-screen-mini-e-paper-display) (US$7.65).
- **Cell:** [Liter Energy 301520](https://www.aliexpress.com/item/1005009496624282.html) (C$5.22 each), or a
  [301518 4-pack](https://www.aliexpress.com/item/1005012116947474.html) (C$18.08). Measure whatever arrives.
- **Motor:** VC0625B002L, the same motor with adhesive.
- **Magnets:** [Amazon.ca GOOZADA, 400 pcs](https://www.amazon.ca/dp/B0F66ZNSV8) (3 × 1), or
  [magpross, 140 pcs](https://www.amazon.ca/dp/B09B34HFLP) (3 × 3). Both must be metric.
- **USB-C breakout:** [Adafruit direct](https://www.adafruit.com/product/6050), US$2.95 + DHL.
- **Strap:** [Barton silicone 16 mm](https://www.amazon.ca/dp/B01ASOGBYG).
- **Filament:** [SUNLU PETG](https://www.amazon.ca/dp/B0B99M3D9B) (C$17.09), or
  [Polymaker PolyFlex TPU90](https://www.amazon.ca/dp/B09KKXZCBR) (C$27.99).
- **USB ESD:** the board uses ST's own USBLC6-2P6 (C15999). The TECH PUBLIC copy (C2827693) also fits, but its CPL
  rotation differs (270° instead of 180°).

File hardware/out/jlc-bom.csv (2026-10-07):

Comment | Designator | Footprint | LCSC Part #
ESP32-S3FN8 | U1 | QFN-56-1EP_7x7mm_P0.4mm_EP4x4mm_Espressif | C2913196
40MHz 12pF | Y1 | Crystal_SMD_2520-4Pin_2.5x2.0mm | C19076867
18pF | C1,C2,C32,C33 | C_0201_0603Metric | C62164
32.768kHz 12.5pF | Y2 | CRYSTAL-SMD_L2.1-W1.2-P1.50 | C403709
24nH | L1 | L_0201_0603Metric | C2991767
2nH | L2 | L_0201_0603Metric | C86125
1uF | C3,C6,C8,C10,C14 | C_0201_0603Metric | C76935
10uF | C5,C15,C17,C35 | C_0402_1005Metric | C15525
10nF | C36,C19 | C_0201_0603Metric | C326875
100nF | C7,C34,C9,C18,C20,C31 | C_0201_0603Metric | C66938
10k | R1,R5 | R_0201_0603Metric | C473048
0.5pF | C11 | C_0201_0603Metric | C85920
0.8nH | L3 | L_0201_0603Metric | C156227
BQ25101 | U2 | DSBGA-6_L0.9-W1.6-R2-C3-P0.40-BL | C478468
6.8k | R2 | R_0201_0603Metric | C274877
2.7k | R7 | R_0201_0603Metric | C273271
4.7uF/25V | C13,C22 | C_0402_1005Metric | C2858031
TPS62840 | U3 | DSBGA-6_L1.4-W1.0-R2-C3-P0.40-BL | C2071139
2.2uH | L5 | IND-SMD_L1.6-W0.8 | C31123918
267k | R6 | R_0201_0603Metric | C423627
10M | R3,R4 | R_0201_0603Metric | C3036920
USBLC6-2P6 | U4 | SOT-666 | C15999
LIS2DUX12 | U6 | LGA-12_L2.0-W2.0-P0.50-TL_LIS2DUX12TR | C17548754
FH34SRJ-18S-0.5SH(50) | J1 | FFC-SMD_18P-P0.50_FH34SRJ-18S-0.5SH | C3169386
PMZ390UN | Q1,Q2 | SOT-883-3_L1.0-W0.6-BR | C458236
47uH | L4 | IND-SMD_L3.0-W3.0_SWPA3010S | C96826
1M | R11,R13 | R_0201_0603Metric | C295786
2.2 | R12 | R_0402_1005Metric | C327251
PMEG3002AEL | D1,D2,D3,D4 | SOD-882_L1.0-W0.6-RD | C478015
2.2uF/25V | C24,C25,C28,C29 | C_0402_1005Metric | C307418
1uF/25V | C26,C27,C30 | C_0402_1005Metric | C52923
LMD2718T261 | MIC1 | MIC-SMD_6P-L2.8-W1.9-P0.98-TL | C5373237
510 | R14,R15,R16,R17 | R_0201_0603Metric | C304550

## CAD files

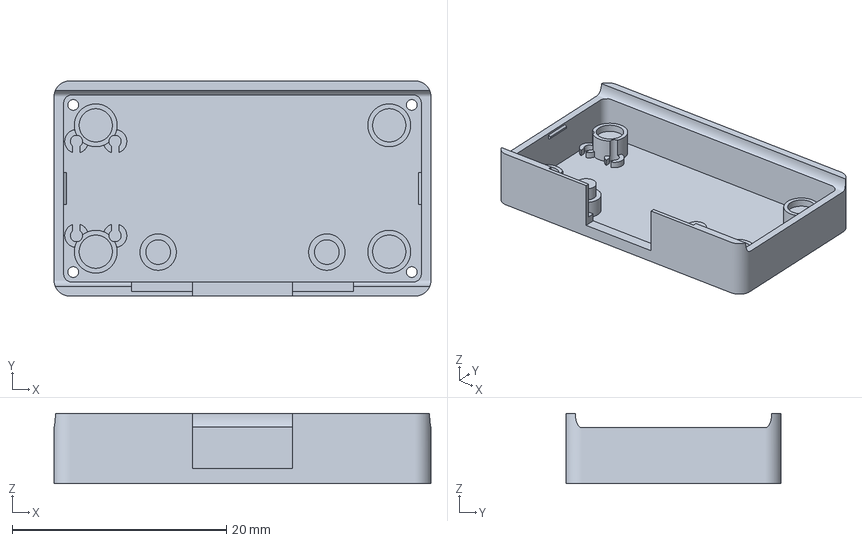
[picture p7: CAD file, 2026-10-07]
cad/out/dock/dock_base.3mf
35.2 x 20.1 x 6.58 mm

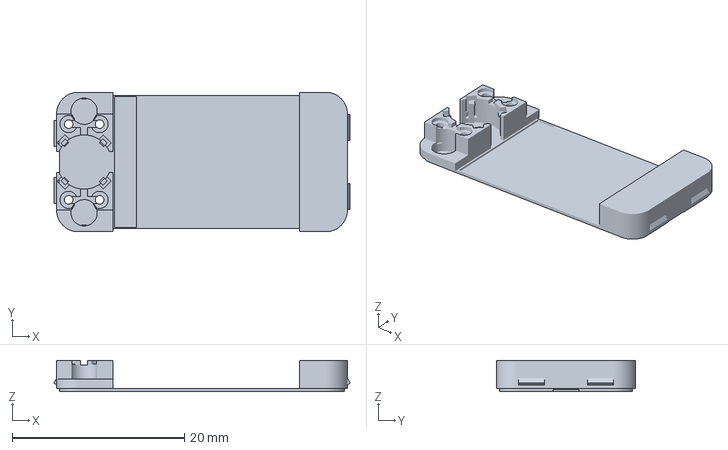
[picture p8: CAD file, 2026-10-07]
cad/out/petg/bottom_shell.3mf
34.4 x 16.2 x 3.65 mm

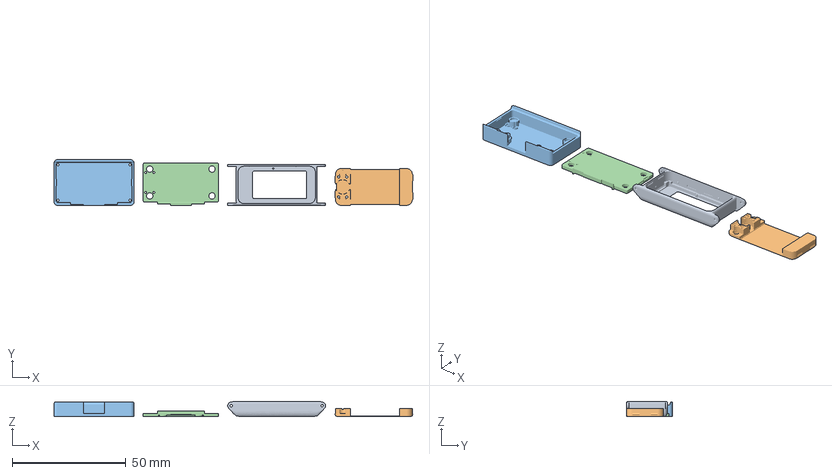
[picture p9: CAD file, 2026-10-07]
cad/out/plates/petg.3mf
157.9 x 20.1 x 6.80 mm
top_shell
bottom_shell
dock_base
dock_lid

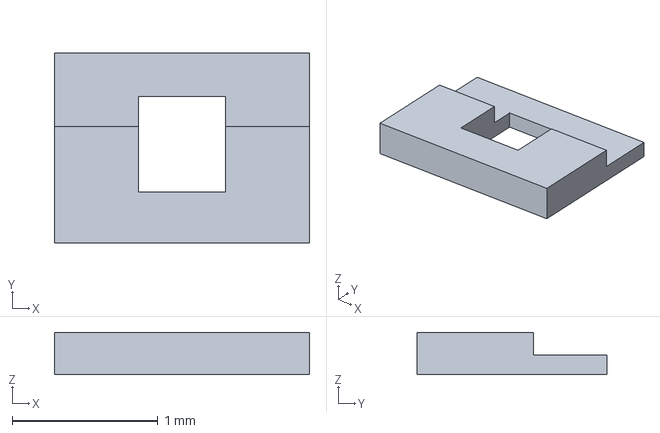
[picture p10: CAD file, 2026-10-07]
cad/out/tpu/mic_seal.3mf
1.75 x 1.31 x 0.29 mm

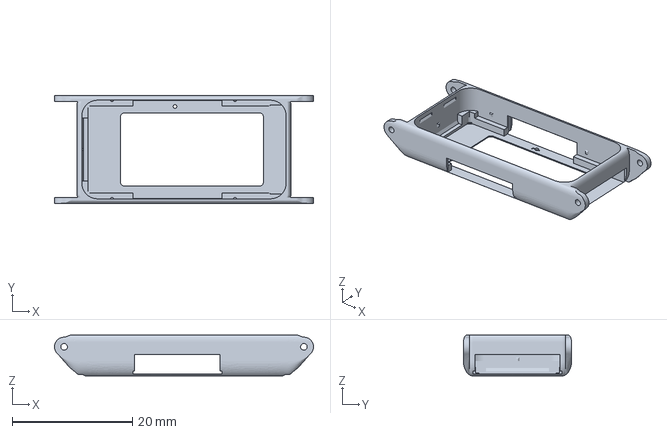
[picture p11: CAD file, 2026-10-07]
cad/out/variant-cf/top_shell_cf.3mf
43.1 x 18.0 x 6.80 mm

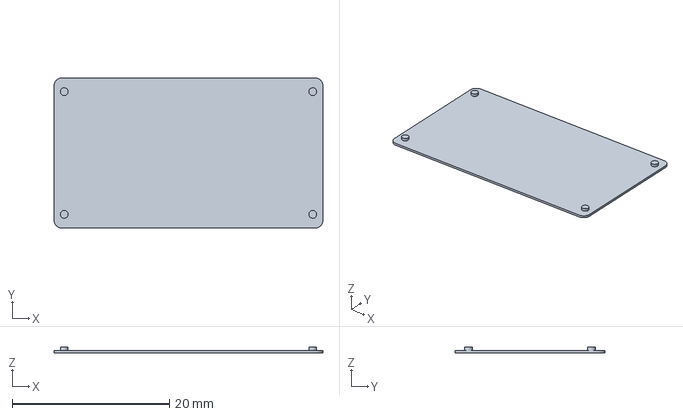
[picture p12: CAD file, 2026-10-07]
cad/out/variant-thin/dock/dock_feet.3mf
34.2 x 19.1 x 0.7 mm

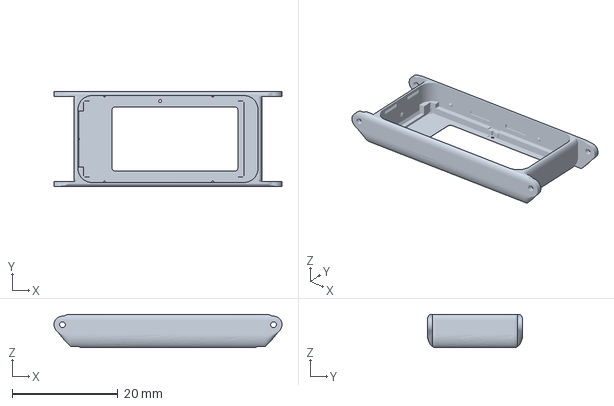
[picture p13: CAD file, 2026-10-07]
cad/out/variant-thin/petg/top_shell.3mf
43.1 x 18.0 x 6.30 mm

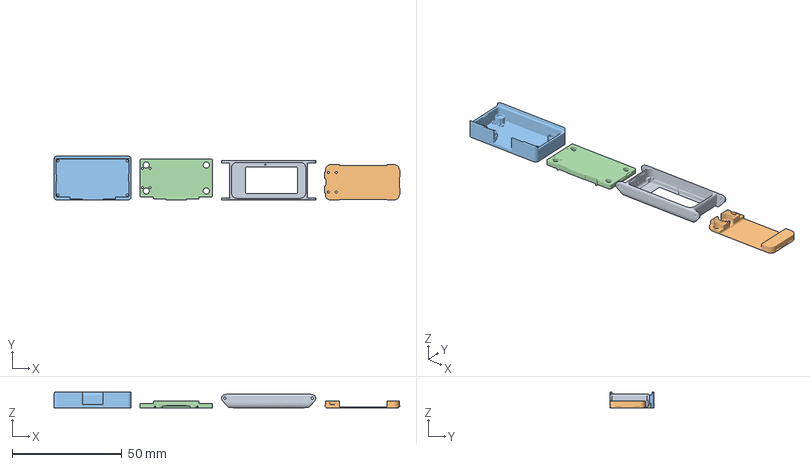
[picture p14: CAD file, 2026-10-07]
cad/out/variant-thin/plates/petg.3mf
157.9 x 20.1 x 7.08 mm
top_shell
bottom_shell
dock_base
dock_lid

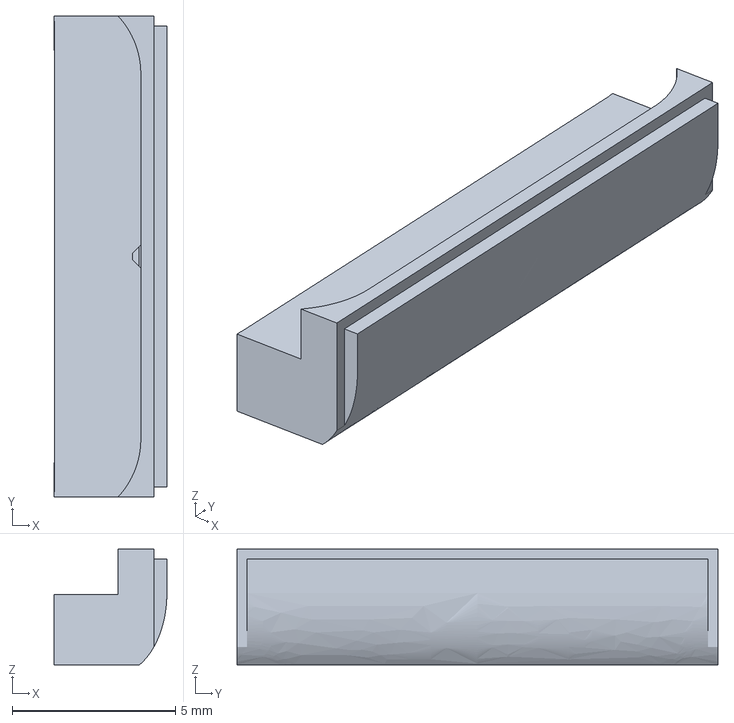
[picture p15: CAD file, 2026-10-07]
cad/out/variant-thin/variant-cf/antenna_window.3mf
3.46 x 14.8 x 3.54 mm

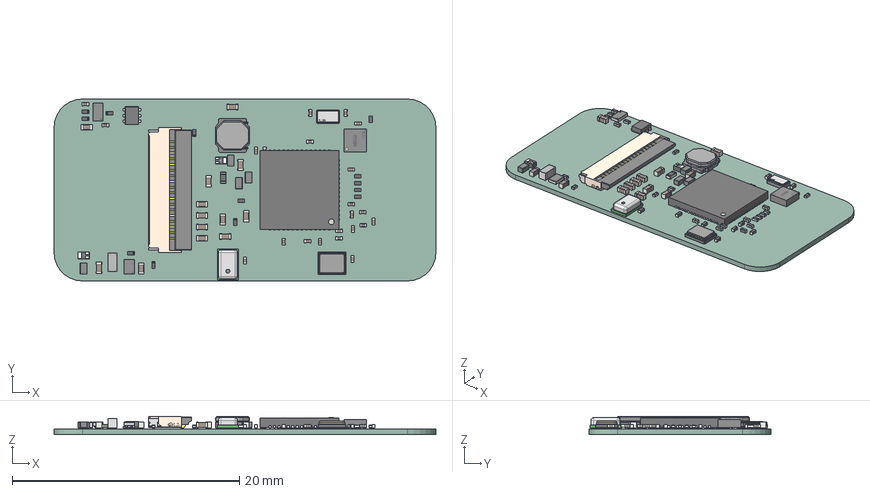
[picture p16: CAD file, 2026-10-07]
hardware/out/horae.step
33.6 x 16.0 x 1.59 mm
C_0201_0603Metric x 19
R_0201_0603Metric x 13
CRYSTAL-SMD_L2.1-W1.2-P1.50
SOT-883-3_L1.0-W0.6-H0.5-BR x 2
R_0402_1005Metric
C_0402_1005Metric x 13
SOD-882_L1.0-W0.6-H0.5-LS0.65 x 4
a48c614c-8773-11ed-8f9d-58fb8493fcfb_part
a48c63fe-8773-11ed-8f9d-58fb8493fcfb_part
a48c65a2-8773-11ed-8f9d-58fb8493fcfb_part
a48c66d8-8773-11ed-8f9d-58fb8493fcfb_part
FFC-SMD_18P-P0.50_FH34SRJ-18S-0.5SH
IND-SMD_L1.6-W0.8-H0.7
LGA-12_L2.0-W2.0-H1.0-P0.50
Crystal_SMD_2520-4Pin_2.5x2.0mm
L_0201_0603Metric x 3
DSBGA-6_L1.4-W1.0-H0.4-R3-C2-P0.40-BL
SOT_666
MIC-SMD_6P-L2.8-W1.9-P0.98-TL
IND-SMD_L3.0-W3.0_FNR3010S
DSBGA-6_L0.9-W1.6-H0.5-R2-C3-P0.40-BL
horae_PCB

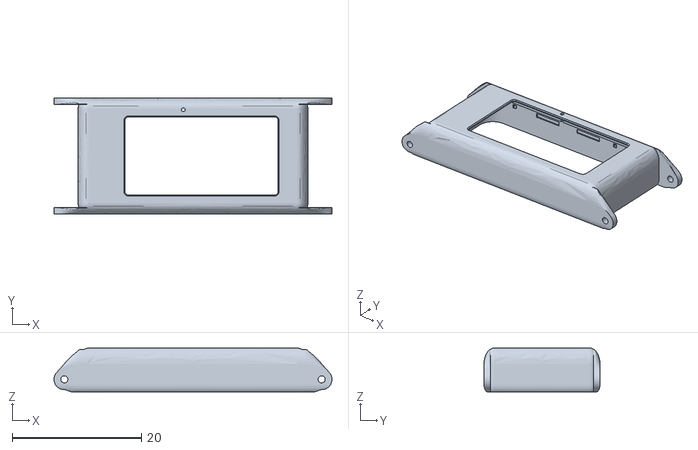
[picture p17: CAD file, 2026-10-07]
hardware/rf/case/top_shell.stl
43.1 x 18.0 x 6.80

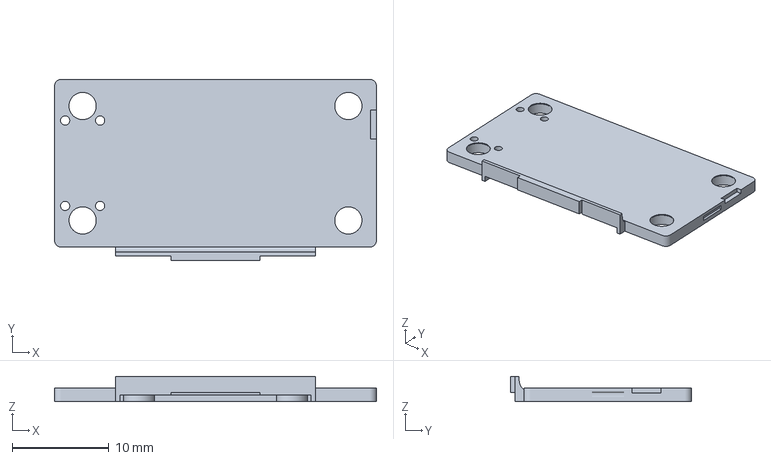
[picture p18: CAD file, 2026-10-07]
cad/out/dock/dock_lid.3mf
33.2 x 18.7 x 2.62 mm

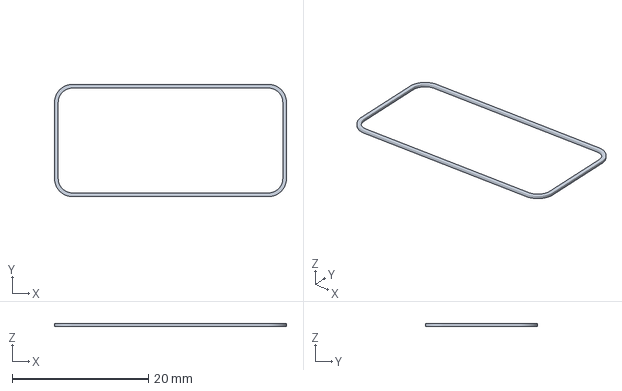
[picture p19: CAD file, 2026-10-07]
cad/out/tpu/bottom_seal.3mf
34.1 x 16.5 x 0.4 mm

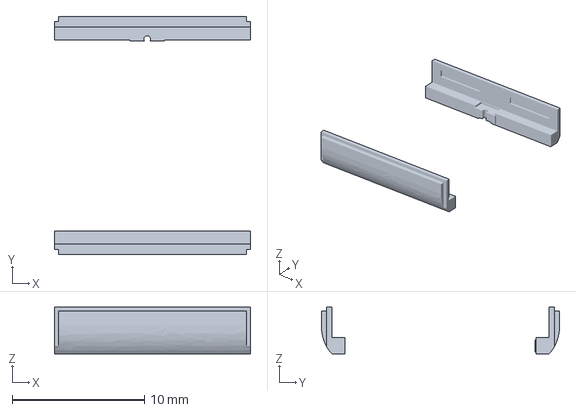
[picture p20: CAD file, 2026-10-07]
cad/out/variant-cf/touch_windows.3mf
14.8 x 18.0 x 3.54 mm

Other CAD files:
cad/out/variant-thin/tpu/mic_seal.3mf
cad/out/petg/top_shell.3mf
cad/out/plates/petg-cf.3mf
cad/out/variant-thin/dock/dock_lid.3mf
cad/out/dock/dock_base.stl
cad/out/dock/dock_feet.3mf
cad/out/dock/dock_feet.stl
cad/out/dock/dock_lid.stl
cad/out/petg/bottom_shell.stl
cad/out/petg/top_shell.stl
cad/out/plates/petg-cf-set.3mf
cad/out/plates/tpu.3mf
cad/out/tpu/bezel_gasket.3mf
cad/out/tpu/bezel_gasket.stl
cad/out/tpu/bottom_seal.stl
cad/out/tpu/cushions.3mf
cad/out/tpu/cushions.stl
cad/out/tpu/mic_seal.stl
cad/out/tpu/pogo_seals.3mf
cad/out/tpu/pogo_seals.stl
cad/out/variant-cf/antenna_window.3mf
cad/out/variant-cf/antenna_window.stl
cad/out/variant-cf/top_shell_cf.stl
cad/out/variant-cf/touch_windows.stl
cad/out/variant-thin/dock/dock_base.3mf
cad/out/variant-thin/dock/dock_base.stl
cad/out/variant-thin/dock/dock_feet.stl
cad/out/variant-thin/dock/dock_lid.stl
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

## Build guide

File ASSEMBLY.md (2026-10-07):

# Building Horae rev A

Print, bring-up, assembly and the firmware rules the hardware depends on. Parts and where to buy them: [ORDER.md](ORDER.md).
Everything is held by the closed case: no glue and no screws. The only soldering is 2 battery wires, 2 motor wires and the
dock's 4 wires.

## 1. Print

Print the two plates on the A1 mini with a 0.4 nozzle and a textured PEI plate. Files are in `cad/out/plates/`.

| Plate | Filament | Settings |
|---|---|---|
| `petg.3mf`: both shells, dock tray and lid | PETG Basic or Matte | 0.1 mm layers **with a 0.1 mm first layer**, because the first layer is the skin over the watch's magnets. No supports. |
| `tpu.3mf`: bezel gasket, shell seal, 4 glass cushions, pogo seal, mic seal, dock grip pad | TPU 90A, dried, from the external spool | 0.1 mm layers. Give the bezel gasket 0.08 mm layers in its object settings (it is 2 layers). Print slowly: 15 mm/s for the gasket. |

The carbon-fibre version uses `petg-cf.3mf` (PETG-CF, hardened nozzle) and `petg-cf-set.3mf` (the colour-matched PETG
parts) instead of `petg.3mf`. Use TPU 90A for every TPU part: 95A is about twice as stiff and overloads the snaps.

After printing:
- **Pin bores:** drill the 4 pin bores in the bottom shell with a 1.0 mm bit in a pin vise, because FDM prints small
  holes undersize.
- **Ear holes:** check that a spring bar's tips go into the 1.1 mm ear holes. If not, ream them with the same bit.
- **Mic vent:** cut a 1.4 × 1.0 mm patch of bare 0.25 mm ePTFE film (no adhesive) with a fresh blade.

**Test print checklist** (no electronics needed):
- The empty shells close with 4 clicks. They open again with a spudger in the pry notch at either end.
- A 3 × 1 mm magnet clicks into each well in the bottom shell from the inside and doesn't fall out when you turn the
  shell over.
- The spring bars and strap fit the ears.
- The dock lid snaps into the tray.

## 2. Check the parts

- **Cell:** measure it before you build. It must be at most 21.4 × 16.0 × 3.25 mm including the protection board (that
  end at most 3.5 thick and 2.5 long). Buy cells no thicker than 3.05 mm. A "301520" cell is listed at 20 ± 2 mm and must
  measure 21.4 or less.
- **Board:**
  - Break it out of its frame and file every tab nub flush with the edge. The board sits on six small crush ribs, so
    keep the edge clean.
  - Under a loupe, check U4's pin-1 dot. Also check that J1's pins aren't bridged.
- **Display:** hold it by the glass edges. Don't crease its ribbon near the glass.

## 3. Bring-up on the bench, before closing anything

The charger can't run the board without a cell, so bring the board up from a bench supply in place of the cell.

1. **Power.** Set the supply to 3.8 V with a 50 mA current limit. Connect + to the square pad TP5 and − to the round pad
   TP6 on the bottom. A blank ESP32 waits in its ROM bootloader and draws a few tens of mA. Check 3.3 V on TP13.
2. **Display.** Flip J1's actuator up and push the ribbon straight into the slot on the −X side (the board end without
   the antenna) as far as it goes. Then close the actuator. J1 has contacts top and bottom.
3. **USB.** Connect GND, D− and D+ to the pogo pads, through a finished dock or a cut USB cable. Leave VBUS off while the
   bench supply powers the board. The ESP32-S3 appears as a USB-Serial/JTAG device and flashes with `esptool.py`.
4. **First flash.** Burn eFuse `DIS_USB_OTG_DOWNLOAD_MODE` (`espefuse.py burn_efuse DIS_USB_OTG_DOWNLOAD_MODE`).
   USB-Serial/JTAG flashing keeps working, and the ROM's USB-OTG download mode can no longer change the mic pins.
5. **Test each block:**
   - display refresh;
   - accelerometer at I²C address 0x19 on GPIO8/9;
   - mic capture;
   - motor at reduced PWM (see section 7);
   - battery ADC;
   - the charger's CHG line with VBUS applied.
6. **Touch.** Read touch raw counts in the closed case before relying on them.
7. **Antenna.** If you have a VNA, check the antenna match in the closed case, strap on (`hardware/README.md`, review item 4).

## 4. Solder the battery and motor

- **Battery:**
  - Trim the cell's leads to about 15 mm and tin them.
  - Solder **red to the square pad (TP5, +)** and **black to the round pad (TP6, −)**. The bottom also has + and − marks.
  - A reversed cell is shorted through the chips until its protection trips. Check twice.
- **Motor:** solder its two leads to TP7 and TP8 (an ERM has no polarity).
- **Leads:** fold each lead into a small slack loop for the bottom shell's lead channel.

## 5. Assemble the watch (upside down)

1. **Top shell:** lip face down.
2. **Vent and gasket:** lay the vent patch on the lip over the mic outlet and slide its outer edge into the slot. Then
   lay the bezel gasket on the lip.
3. **Display:** face down, with its ribbon already plugged into the board.
4. **Cushions:** one on each glass corner.
5. **Mic seal:** into its relief.
6. **Board:** fold it over the display, parts down, between the crush ribs.
7. **Battery and motor:** into their places, with the lead loops in the channel.
8. **Pogo seal:** the one-piece seal onto the pogo pads.
9. **Magnets:**
   - To get the poles right, stick each 3 × 1 mm magnet onto the dock magnet it will sit over. The face that touches the
     dock faces out.
   - Click each magnet into its well from the inside.
   - Seen from the outside, with the watch on the dock the right way round, the back magnet's N pole faces down and the
     front one's S pole.
10. **Close:** put the seal ring on the floor plate and press the bottom shell on until all 4 snaps click.
11. **Strap:** fit the spring bars and the strap.

To open the case again, use a spudger in the pry notch under the strap at either end.

## 6. Build the dock

Spring pins in the lid, wired to the Adafruit 6050 on the tray's pegs; the lid then snaps into the tray.

Seen from above into the open tray (lid off), with the USB-C port toward you, the 4 pins form a 2 × 2 group at the left
end:

| Pin | Net | Wire to the 6050 pad marked |
|---|---|---|
| back-left | VBUS | VBUS |
| back-right | D− | D- |
| front-left | GND | GND |
| front-right | D+ | D+ |

- **Wires:** use 2–3 cm of 30 AWG, and twist the D+ and D− pair. Leave the SBU and CC pads free; the 6050's own
  5.1 kΩ CC resistors make any USB-C charger give 5 V.
- **Magnets:** 3 × 3 mm, back row S pole up and front row N pole up, at both ends. Press them into the lid from below, up
  to the retaining lip.
- **Order:** press the pins' collars up under the lid plate, seat the 6050 on its two pegs and snap the lid in. Then
  press the TPU grip pad's 4 stems into the tray floor.
- **Check:** docked the right way round, the watch's mic hole faces you and its pin end is on the left. Turned end for
  end, the magnets push it off, so VBUS never lands on GND.

Diagram: `media/2026-10-07/cad-dock-wiring.png`.

## 7. Firmware rules the hardware depends on

- **Motor:** the VC0625B001L is rated 2.5 V (2.0–3.5 V), but Q2 switches it from the battery at 3.5–4.2 V. Drive it
  with 20–25 kHz PWM at a duty of 2.5 V / VBAT, never above 3.5 V / VBAT, and soft-start it over 10–20 ms.
- **Deep sleep:**
  - Hold GPIO38–40 (the mic) low with `gpio_hold_en` and `gpio_deep_sleep_hold_en`.
  - Hold the display's CS and RES high and DC, SCK and MOSI low.
  - Don't enable a pull-down on BUSY.
  - Put the panel in deep sleep (0x10, 0x01) and resend the image after waking, because the panel loses its RAM.
- **Wake:**
  - Wake on the accelerometer's wrist-tilt or double-tap interrupt and on CHG_STAT, both through EXT1. Set the
    accelerometer interrupt active-low to match CHG.
  - Also enable one touch channel, scanning every 100–200 ms with few charge cycles, and scan all four after waking.
  - Never use ESP-IDF's default touch settings in deep sleep: they cost hundreds of µA.
  - Expect about 27 days on 40 mAh and 37 days on 55 mAh with a refresh every minute.
- **Battery ADC:** the divider is 10 MΩ / 10 MΩ, so calibrate each board at the 4.20 V end of charge.
- **Power safety:**
  - Use the highest brown-out level, and refuse flash writes below about 3.4 V.
  - On these tiny cells, cap Wi-Fi TX power, keep BLE at 0 dBm or below, and avoid the radio below about 3.6 V.
- **I²C:** run it at 100 kHz, because the bus uses the ESP32's internal pull-ups. The ULP has to bit-bang it:
  GPIO10/11 aren't ULP I²C pins.
- **Charging:**
  - The charger has a 10-hour safety timer. Deep-sleep while docked and stay awake only to flash.
  - Use USB-Serial/JTAG, not TinyUSB, so automatic download mode keeps working.

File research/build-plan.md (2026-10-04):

# Build plan: custom board rev A

_Drafted 2026-10-03. This replaces the XIAO carrier from [prototyping.md](prototyping.md) if we go straight to a custom board. Costs are estimates; get real quotes at order time._

Target: **~36 × 17.5 × 6.6 mm** (see optimizations below), ESP32-S3 with Wi-Fi + BLE, 0.97" e-paper, hand-assembled at home.

## 0. Rev A, optimized for parts count, thickness and battery

### Fewer parts: ~44 placed vs Watchy's ~75
| Change | Saves |
|---|---|
| **[ESP32-S3-PICO-1](https://documentation.espressif.com/esp32-s3-pico-1_datasheet_en.html)** SiP instead of a bare ESP32-S3. It's 7×7×≤1.06 mm and contains the crystal, 8 MB flash, PSRAM, decoupling and RF matching. Externally it needs only 22 µF, 100 nF, an EN RC pair and a pi-match footprint (start it as a 0 Ω + 2 unfitted parts). Same chip, same Wi-Fi + BLE | ~15 parts |
| PCB trace antenna (Watchy's inverted-F) | 0 antenna parts |
| One user button wired to GPIO0, doubling as BOOT. EN on a test pad. Buttons use the chip's internal RTC pull-ups | 1 button + pull-ups |
| RV-3028-C7 RTC (crystal built in) replaces the 32 kHz crystal + 2 caps | 1 part, and ±1–3 ppm accuracy |
| Native USB over pogo pads instead of a USB socket | the socket |
| Vibration motor footprint left **unfitted** in rev A | 4 parts (optional) |

**Soldering:** everything sits on one side and goes through **one hot-plate pass**. The only hand-soldering is the 2 battery wires, plus 2 motor wires if fitted. The display ribbon plugs into its socket.

**Kept on purpose:**
- The charger (TP4054). If the battery connected straight to the pogo pads, they'd sit at 3.7 V against sweaty skin and corrode.
- One ESD part (USBLC6-2P6) on the exposed USB pads.

### Thinnest stack (display on top, parts under it, battery below)
| Layer | mm |
|---|---|
| Printed lip over the display edge (0.2 mm nozzle) | 0.5 |
| GDEM0097T61 | 1.0 |
| Adhesive/gap | 0.1 |
| Tallest parts (PICO-1 1.06, FH34SRJ 1.0, booster inductor ≤1.0) | 1.06 |
| PCB, 4-layer **0.6 mm** (confirm with JLC, else 0.8) | 0.6 |
| Battery ~2.4–2.5 mm + swelling | 2.75 |
| Case floor with pogo windows | 0.6 |
| **Total** | **~6.6** |

- **Footprint:** ~36 × 17.5 mm, compared with the [Charge 6](https://store.google.com/product/fitbit_charge_6_specs) at 36.7 × 23.1 × 11.2. Length is the 30 mm display plus an antenna end that sits past the display glass. Width is the 14.15 mm display + 0.8 mm walls + side buttons.
- **Height budget:** every part under the display must be ≤1.06 mm. That means 0402 passives, SOD-323/523 diodes, an SOT-323 MOSFET, and a 47 µH inductor in a 2520 or 3×3×1.0 package.
- **Alternative layout (~5.5 mm):** put the board and battery side by side under the display instead of stacked. The catch is that the battery shrinks to ~15×15×3 mm, about 50 mAh. Consider it for rev B once real current draw is measured.
- **Carbon fiber later:** a CNC-cut 0.3–0.5 mm CF back or shell (PCBWay/JLC CNC) allows thinner walls. **CF is conductive and blocks Wi-Fi/BLE**, so the antenna end has to stay plastic or glass. Printing CF-filled filament on the A1 mini needs the hardened steel nozzle.

### Battery life
| Item | ~µA |
|---|---|
| ESP32-S3 deep sleep, RTC peripherals off (datasheet) | 7–10 |
| RT9080 LDO (600 mA for Wi-Fi bursts, [2 µA Iq](https://www.richtek.com/assets/product_file/RT9080/DS9080-09.pdf)) | 2 |
| RV-3028-C7 | 0.05 |
| **BMA400** step counter ([4 µA](https://www.bosch-sensortec.com/media/boschsensortec/downloads/product_flyer/bst-bma400-fl000.pdf)) instead of BMA423 (its sibling BMA422 is listed at 25 µA). Needs a new driver | 4 |
| Battery divider (10 MΩ total) + e-paper deep sleep | ~1.3 |
| Wake every minute, fast boot (~40–60 ms at ~35 mA) | 25–35 |
| Partial refresh, 6 mW × 0.3 s per minute | ~8 |
| Wi-Fi sync once a day | ~4 |
| **Total** | **~50–65 µA ≈ 1.2–1.6 mAh/day** |

- **Estimate:** on a ~90–100 mAh cell that's **~4–8 weeks on paper**. Treat it as 2–6 weeks until a PPK2 measures the real board.
- **Wiring for later savings:** connect the display, RTC INT and buttons to **RTC-capable GPIOs** (GPIO0–21). Later firmware can then use the ULP core or a deep-sleep wake stub to update the minute digits without a full boot, cutting the biggest line in the table. This costs nothing in hardware.

## 1. Design (Claude, ~2–4 days with your reviews)
1. Fork [sqfmi/watchy-hardware](https://github.com/sqfmi/watchy-hardware) into this repo (`hardware/`) and upgrade it to KiCad 10.
2. Schematic: trim Watchy down, swap in the parts listed above, and add the new connector, RTC, pogo pads and test pads.
3. Place and route on a ~34×18 mm outline, with the antenna at one end and a ground-free keep-out under it.
4. Check it with `kicad-cli` (ERC/DRC). Export renders, STEP, gerbers, BOM and placement files. Each milestone gets a screenshot on the timeline.
5. Design the case in build123d around the board STEP: shell, display window, button caps, strap lugs, plus the dock.
6. **Review gate:** you look over the renders and the case before we pay for anything.

## 2. Order (one day; parts arrive in 1–2 weeks)
| What | Where | Lead | ~Cost |
|---|---|---|---|
| 5× bare boards, 4-layer 0.8 mm + steel stencil | JLCPCB, by DHL | 3–4 days to make + 3–5 days to ship | $15–25 + ~$20 shipping + CAD ~$15–20 tax/brokerage |
| Parts for 3 boards (ESP32-S3, crystal, RTC, BMA423, regulator, charger, booster, socket, buttons, motor, passives + spares) | LCSC (same group as JLC) or Digi-Key CA | 3–7 days | ~$50–70 |
| 4× GDEM0097T61 displays | Good Display on AliExpress / buy-lcd | 1–3 weeks (**order first**) | ~$20–50 |
| 3× LiPo ~100 mAh | AliExpress / Adafruit | 1–3 weeks | ~$15 |
| Dock: spring pogo pins, 6×2 mm magnets, USB-C breakout | AliExpress / Amazon.ca | 1–2 weeks | ~$15 |
| **Firmware dev kit (optional, recommended):** XIAO ESP32S3 + DESPI-C02-CV0097 adapter | Seeed / openelab | ~1 week | ~$20 |

The dev kit lets firmware work start on a real panel before our boards arrive.

### Tools, if you don't have them
- **Hot plate:** a small PTC plate (~$30–40) or Miniware MHP30 (~$80)
- **Solder paste** (Sn63/37 or SAC305 syringe) and **tacky flux**: ~$25
- **Tweezers + magnifier** (a USB microscope or 10× loupe): ~$30
- **Hot-air station** (~$60–100): strongly recommended for fixing a bridged QFN or reworking the display socket
- **Nordic PPK2** (~$100): optional, but the only way to get real battery numbers

### Lower-risk alternative
Have JLC assemble just the hard parts: ESP32-S3, crystal, BMA423, RTC, regulator and charger. This costs roughly +$30–70 for 5 boards and +2–4 days, and removes most of the tools and most of the risk. You'd still solder the socket, buttons, motor and battery.

## 3. Assemble (you, one evening per board)
1. Tape the stencil over the board, then spread paste with a card.
2. Place the parts with tweezers: the chip and module, then the small passives.
3. Reflow on the hot plate. Inspect under magnification, then fix bridges with flux and wick or hot air.
4. Hand-solder the display socket if the hot plate disturbed it, then the motor and battery leads (**battery last**).
5. Bring it up in steps:
   1. Check the power rails on USB with no battery fitted.
   2. Flash over the pogo pads, using the ESP32-S3's native USB.
   3. Test serial output, the display, RTC, buttons, accelerometer, motor and battery voltage, one at a time.

## 4. Firmware (Claude, in parallel)
- PlatformIO + Arduino-ESP32, forked from the [Watchy firmware](https://github.com/sqfmi/Watchy).
- A GxEPD2 class for the 184×88 SSD1680 panel.
- A first watch face designed for a narrow portrait bar.
- Power: deep sleep, woken every minute by the RTC, with partial refresh. Wi-Fi only on demand (daily NTP time and weather, OTA updates). Bluetooth comes later.
- Bring-up sketches for each component, so a dead board can be narrowed down to one part.

## 5. Print and wear
- **Case:** PLA for fit checks, PETG for wearing. Use the 0.2 mm nozzle for the thin walls.
- **Strap:** TPU, or standard spring-bar lugs.
- **Dock:** printed with the pogo pins and magnets pressed in.
- **Wear test:** a week on the wrist. Log battery voltage over time and measure sleep current.
- **Rev B:** collect every problem into one list for the next board.

## 6. Timeline, if everything goes right
| Week | |
|---|---|
| 1 | Design + review; order displays and batteries on day 1 |
| 2 | Order boards + parts; firmware on the dev kit |
| 3 | Boards arrive; assemble + bring-up; print the case |
| 4 | Wear test; rev B list |

## Risks
- **First custom RF board.** The antenna may need tuning. We reduce the risk by copying Watchy's proven antenna and RF layout as closely as the new shape allows.
- **QFN56 at 0.4 mm pitch** is the hardest part to solder by hand-reflow. Mitigations: buy spare chips and boards, or use the JLC alternative above.
- **Display stock:** GDEM0097T61 is out of stock at buy-lcd today. Order early from AliExpress.
- **Rev A will have mistakes.** Budget for a rev B (another ~$40 of boards).

## JLC full assembly: estimate (checked 2026-10-03)
Live JLC parts-library stock on 2026-10-03:

| Part | JLC/LCSC | Stock | ~$ each |
|---|---|---|---|
| ESP32-S3-PICO-1-N8R2 | C7558093 | **0** (would need Global Sourcing from Digi-Key) | 5.0 |
| **ESP32-S3FN8** (bare chip, Watchy's) | C2913196 | 660 | 3.33 |
| RV-3028-C7 | C2829066 | **0** | – |
| **RV-3032-C7** (2.5 ppm, crystal inside) | C5127802 | 4572 | 3.44 |
| BMA400 | C437655 | 226 | listed 14.9 at JLC (LCSC lists ~$2–3) |
| BMA456 (same BMA4 API as Watchy's BMA423) | C189518 | 2540 | 4.88 |
| FH34SRJ-18S-0.5SH(50) | C3169386 | 26512 | 0.28 |
| EVQ-PUC02K / EVQ-P7M01P buttons | C79174 / C7275646 | 6 / 265 | 0.17 / 0.58 |
| RT9080-33GJ5 | C841192 | 39625 | 0.12 |
| TP4054 | C32574 | 26354 | 0.13 |

**Decision:** because JLC places every part, part count no longer costs soldering time. So use the in-stock **ESP32-S3FN8 + crystal**, exactly as Watchy does, and copy Watchy's proven RF layout. That adds ~14 robot-placed parts and no Global Sourcing delay.

| Line (Economic PCBA, 4-layer **0.8 mm**, the minimum for Economic) | 2 boards assembled | 5 boards assembled |
|---|---|---|
| 5 bare boards | ~$8 | ~$8 |
| Setup + stencil | $9.50 | $9.50 |
| Extended-part loading, ~10 lines × $3 | ~$30 | ~$30 |
| Parts, ~$15–18 per board | ~$34 | ~$85 |
| Joints, ~250 × $0.0016 | ~$1 | ~$2 |
| **Subtotal (USD)** | **~$83** | **~$135** |
| DHL to Vancouver | ~$20–25 | ~$20–25 |
| GST+PST 12% + brokerage (CAD) | ~$30 | ~$40 |
| **Landed (CAD)** | **~$170** | **~$260** |

**Lead time:** ~3–4 days for the boards, +1–2 days for assembly, +3–5 days DHL, so **~1.5–2 weeks**.

**Cost compared with DIY:** self-assembly saves only ~$40–60 in fees, but needs ~$60–100 of tools and carries real risk on the QFN.

**Left for us:** plug in the display ribbon, solder 2 battery wires, and assemble the case.

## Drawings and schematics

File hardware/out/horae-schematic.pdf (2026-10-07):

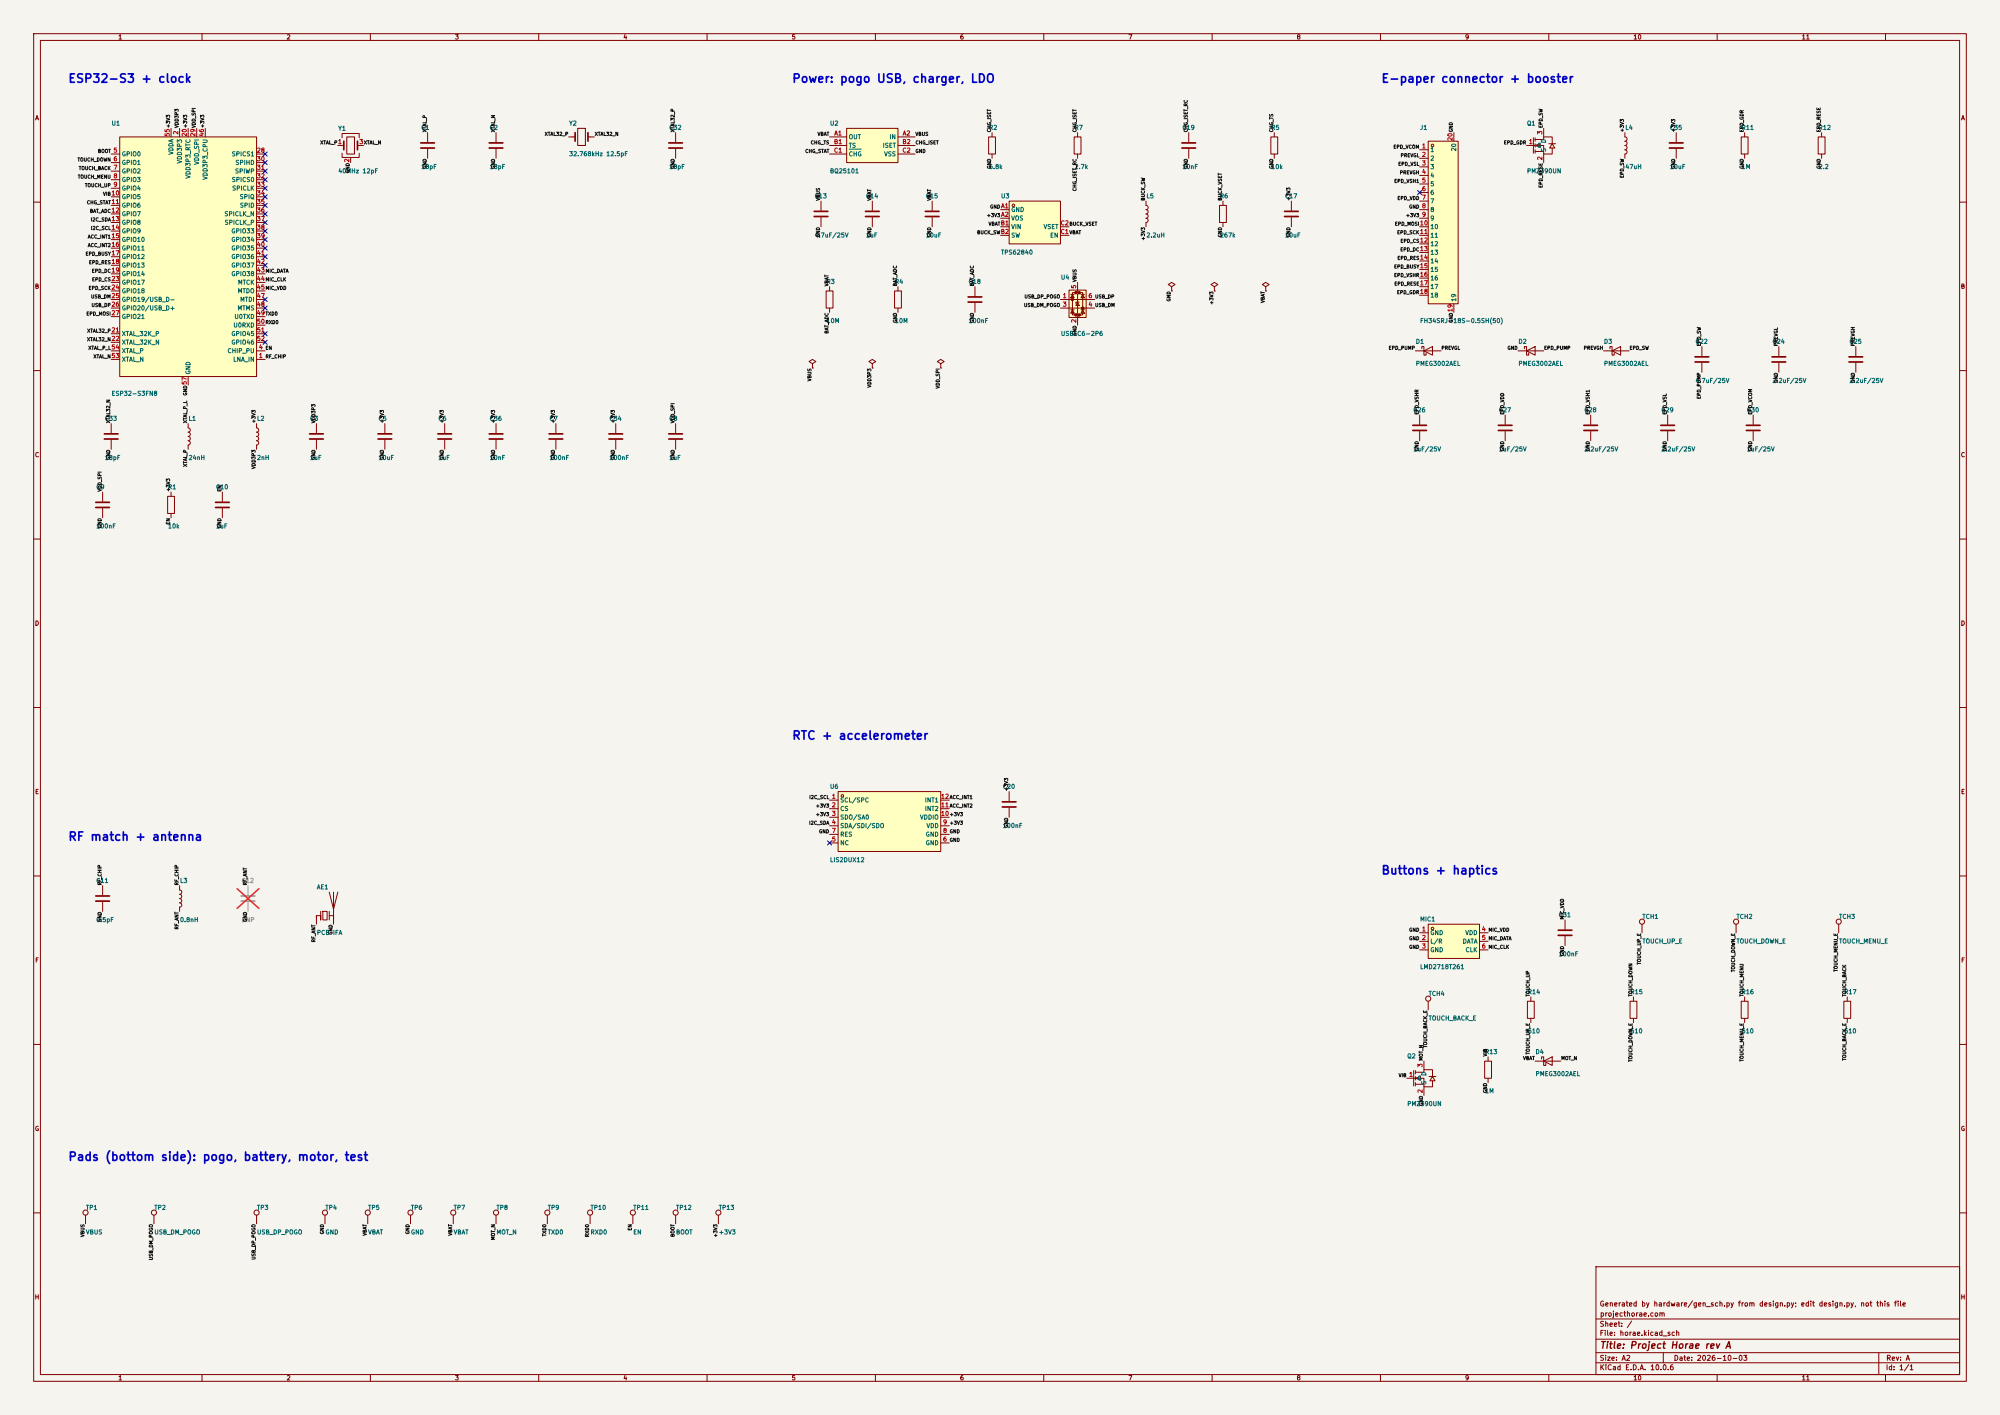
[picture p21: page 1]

Power: pogo USB, charger, LDO

Pads (bottom side): pogo, battery, motor, test

Generated by hardware/gen_sch.py from design.py; edit design.py, not this file
projecthorae.com
Sheet: /
File: horae.kicad_sch
Title: Project Horae rev A

Size: A2 | Rev: A
KiCad E.D.A. 10.0.6 | Id: 1/1

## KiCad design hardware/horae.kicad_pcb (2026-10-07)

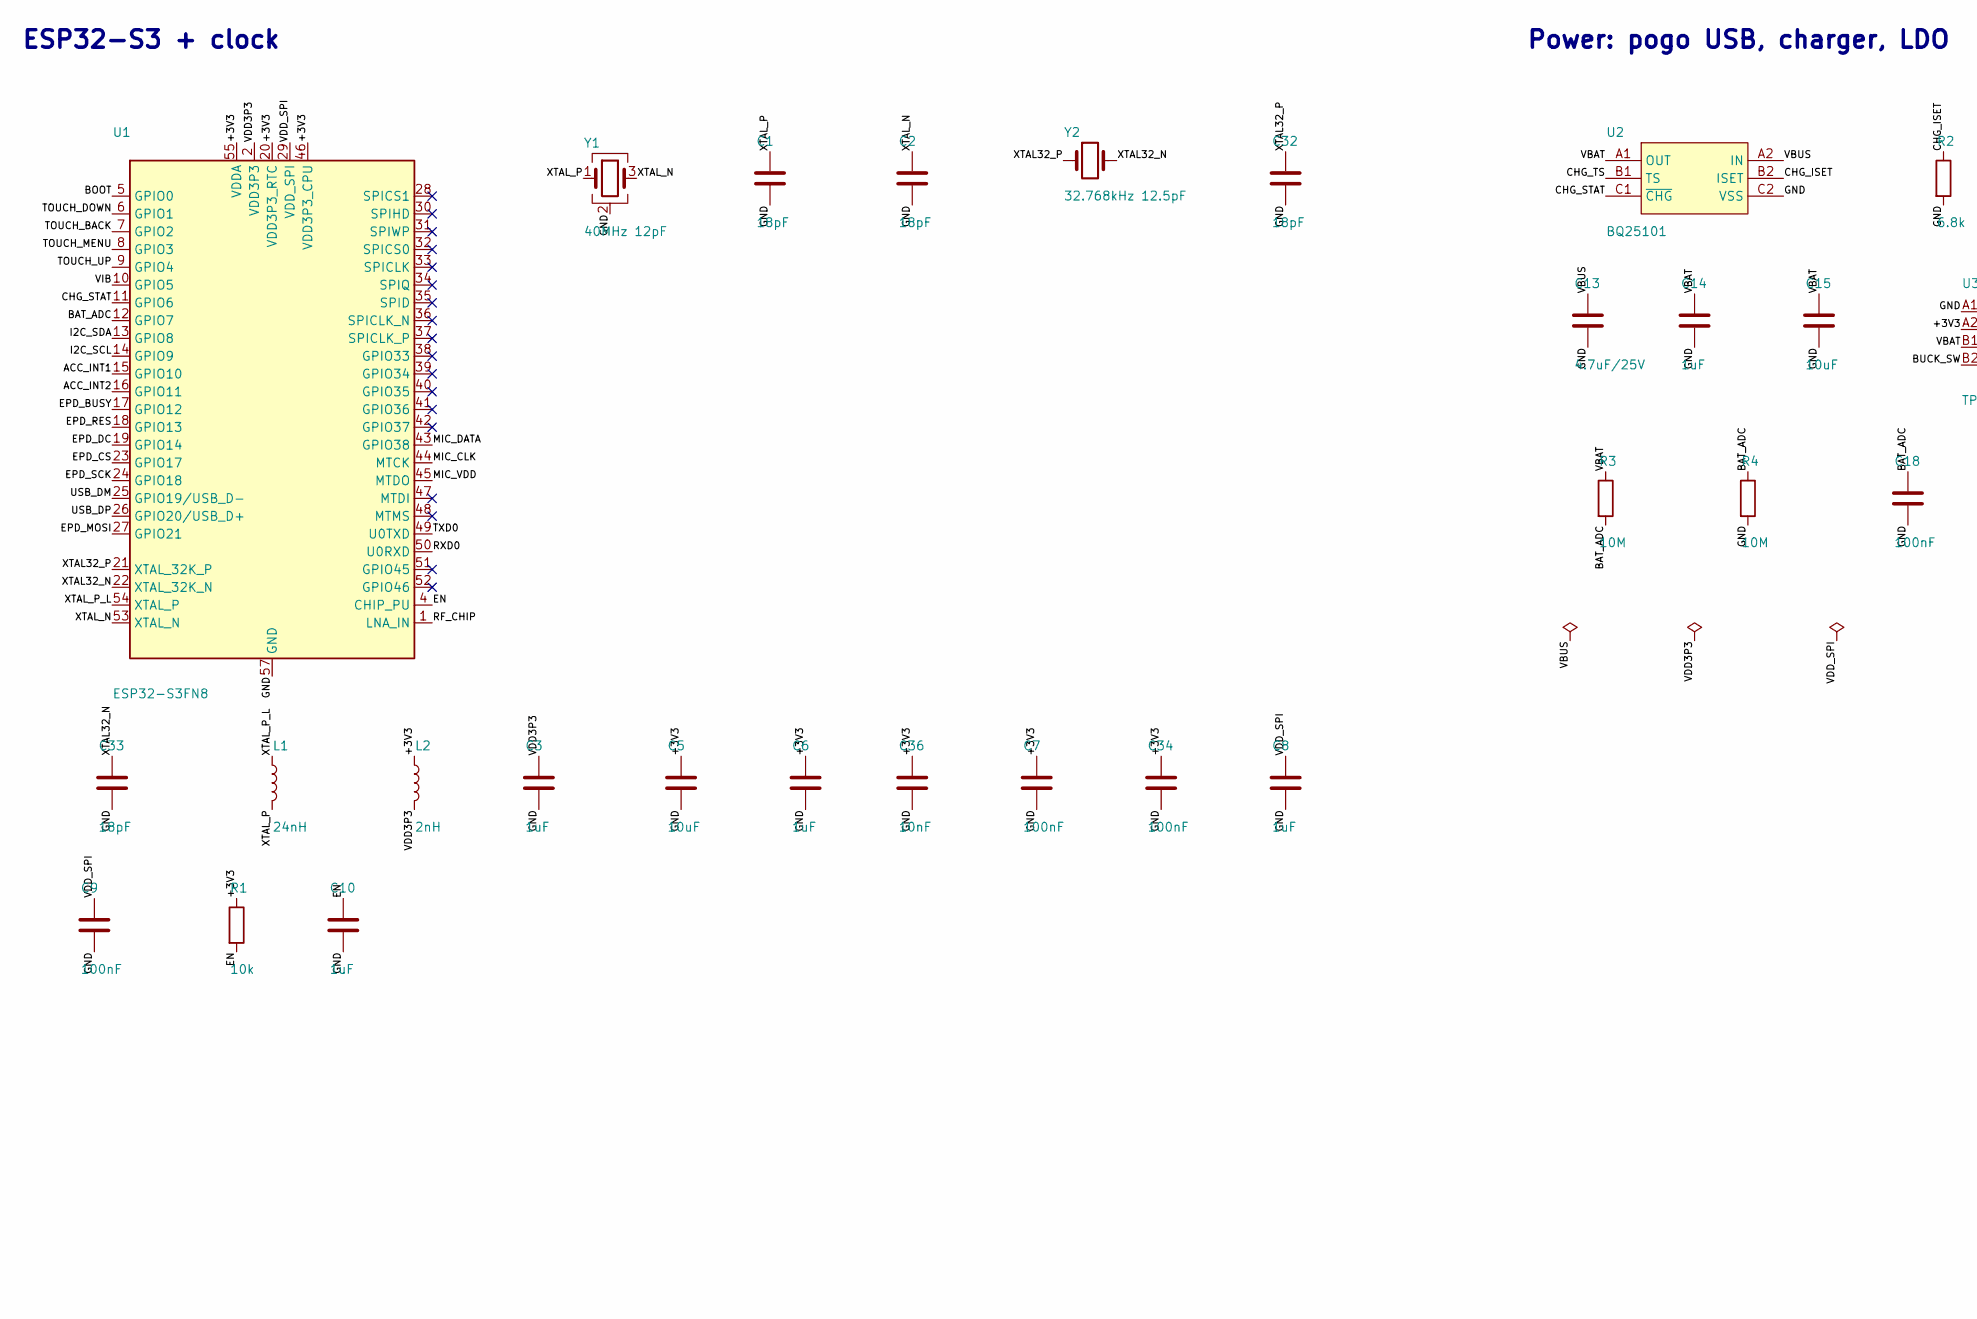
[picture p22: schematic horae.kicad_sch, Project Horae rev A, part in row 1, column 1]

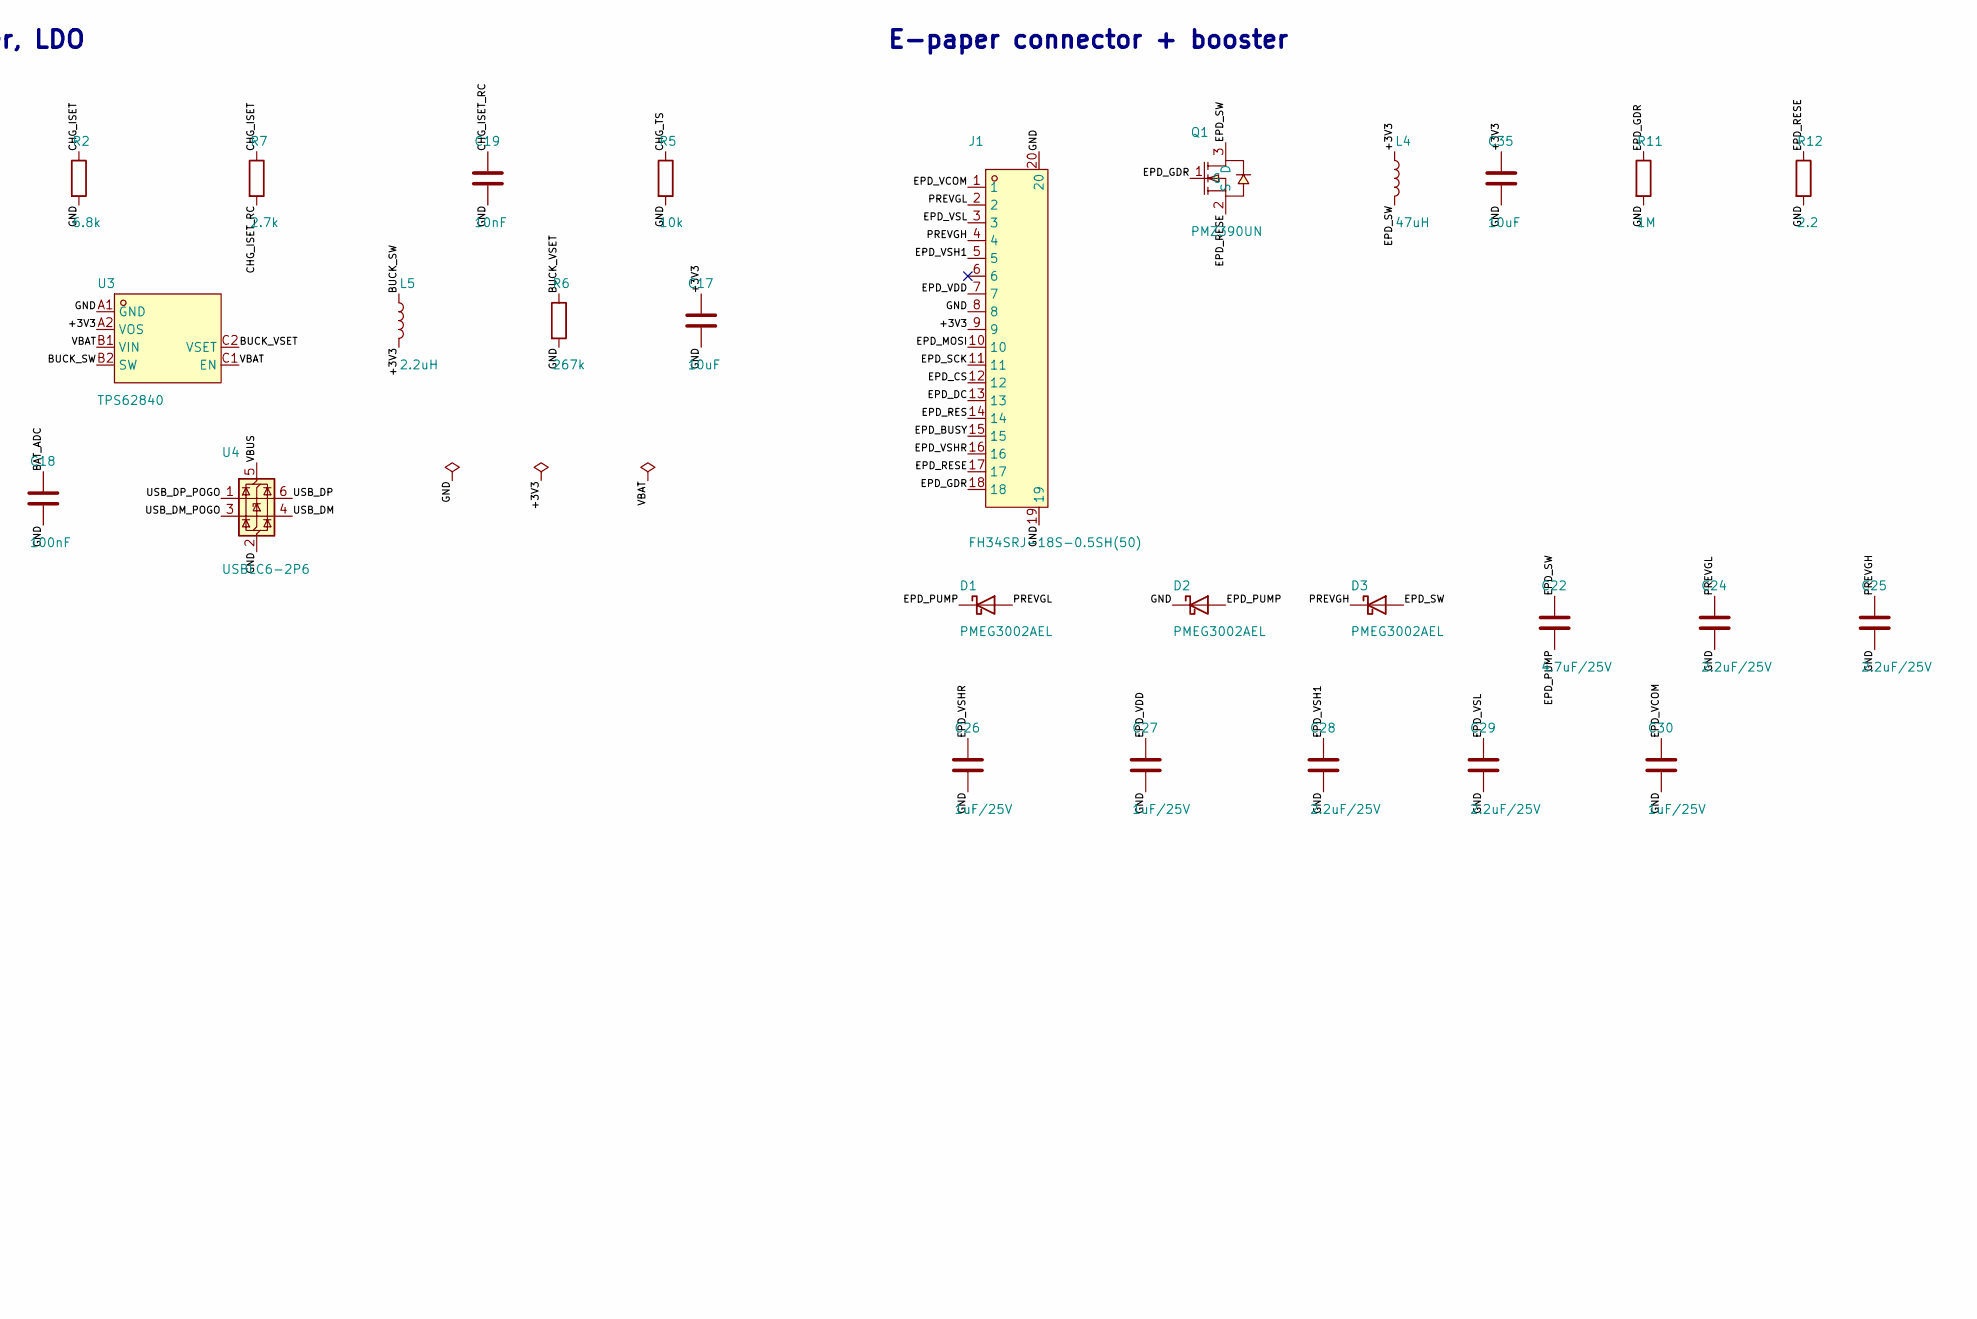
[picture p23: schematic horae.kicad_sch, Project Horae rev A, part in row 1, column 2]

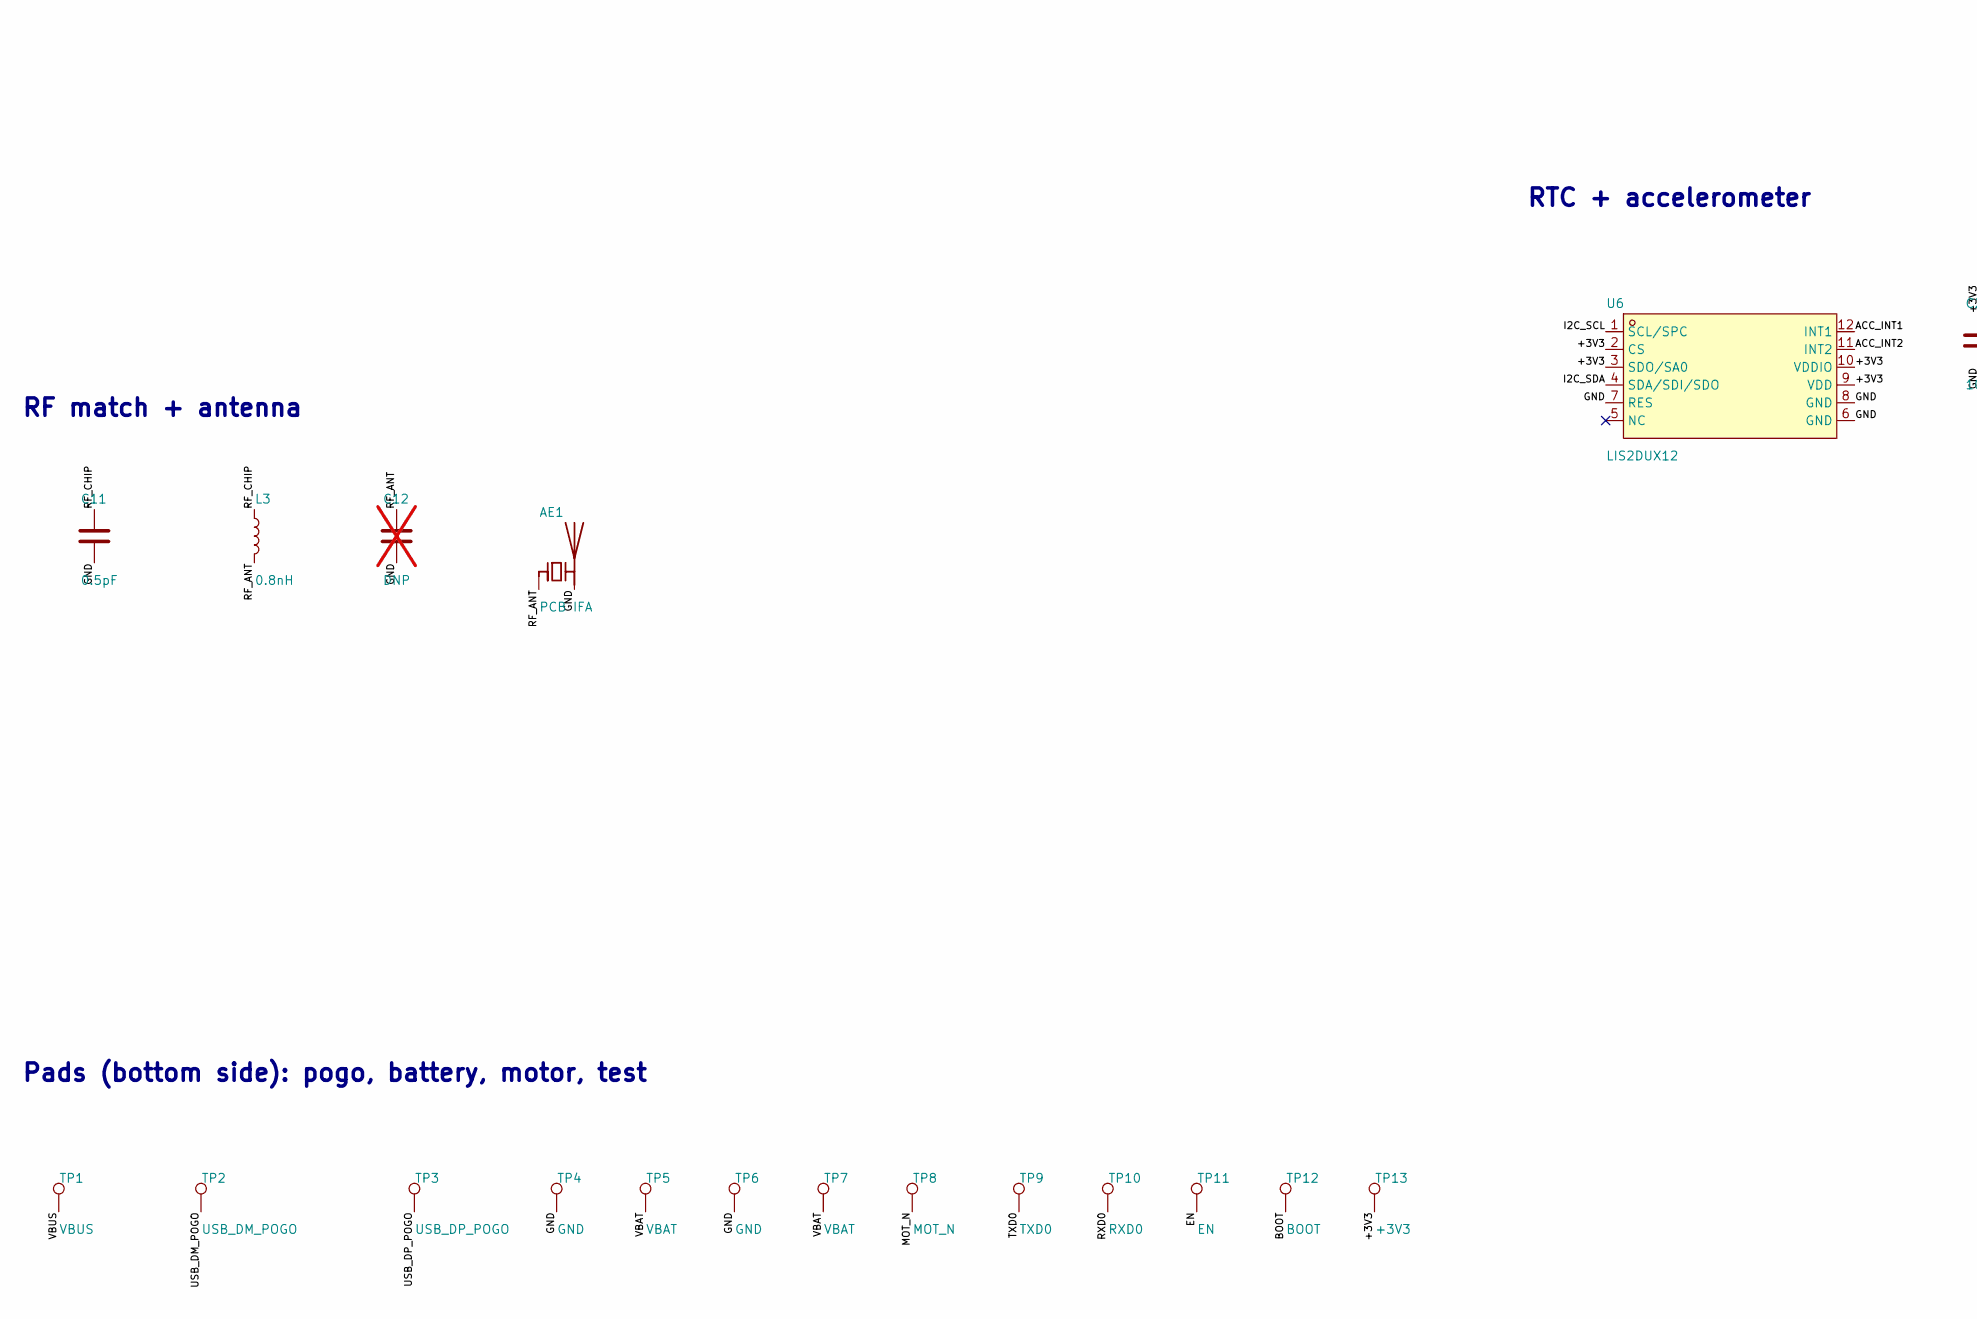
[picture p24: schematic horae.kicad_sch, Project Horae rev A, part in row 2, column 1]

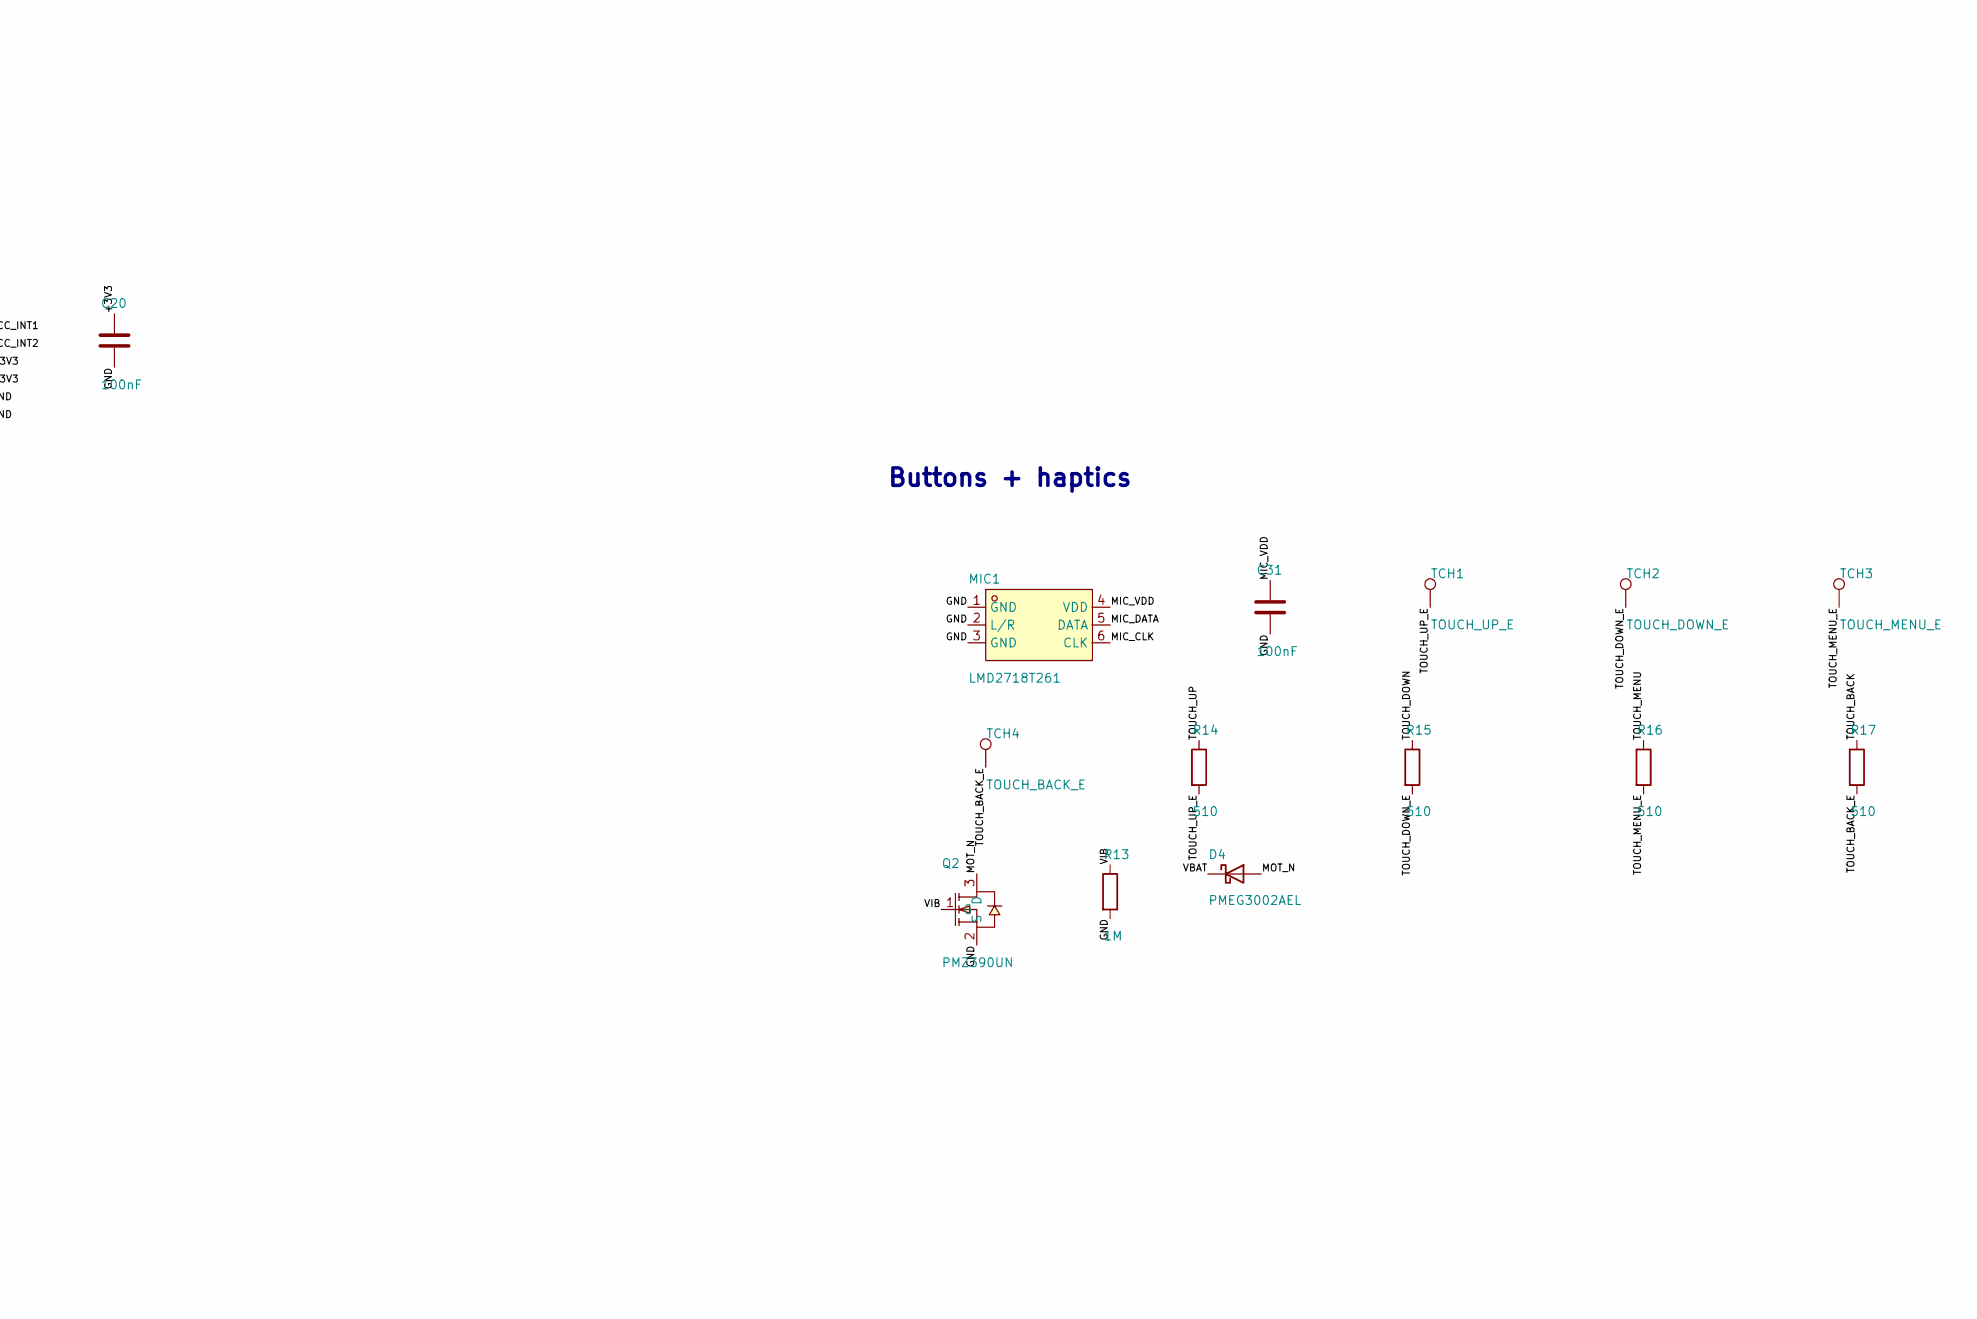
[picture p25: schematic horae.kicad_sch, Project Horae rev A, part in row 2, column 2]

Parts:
AE1: PCB IFA; SWRA117D
C1, C2, C32, C33: 18pF; C_0201_0603Metric; LCSC C62164
C3, C6, C8, C10, C14: 1uF; C_0201_0603Metric; LCSC C76935
C5, C15, C17, C35: 10uF; C_0402_1005Metric; LCSC C15525
C7, C9, C18, C20, C31, C34: 100nF; C_0201_0603Metric; LCSC C66938
C11: 0.5pF; C_0201_0603Metric; LCSC C85920
C12: DNP; C_0201_0603Metric; not fitted
C13, C22: 4.7uF/25V; C_0402_1005Metric; LCSC C2858031
C19, C36: 10nF; C_0201_0603Metric; LCSC C326875
C24, C25, C28, C29: 2.2uF/25V; C_0402_1005Metric; LCSC C307418
C26, C27, C30: 1uF/25V; C_0402_1005Metric; LCSC C52923
D1, D2, D3, D4: PMEG3002AEL; SOD-882_L1.0-W0.6-RD; LCSC C478015
J1: FH34SRJ-18S-0.5SH(50); FFC-SMD_18P-P0.50_FH34SRJ-18S-0.5SH; LCSC C3169386
L1: 24nH; L_0201_0603Metric; LCSC C2991767
L2: 2nH; L_0201_0603Metric; LCSC C86125
L3: 0.8nH; L_0201_0603Metric; LCSC C156227
L4: 47uH; IND-SMD_L3.0-W3.0_SWPA3010S; LCSC C96826
L5: 2.2uH; IND-SMD_L1.6-W0.8; LCSC C31123918
MIC1: LMD2718T261; MIC-SMD_6P-L2.8-W1.9-P0.98-TL; LCSC C5373237
Q1, Q2: PMZ390UN; SOT-883-3_L1.0-W0.6-BR; LCSC C458236
R1, R5: 10k; R_0201_0603Metric; LCSC C473048
R2: 6.8k; R_0201_0603Metric; LCSC C274877
R3, R4: 10M; R_0201_0603Metric; LCSC C3036920
R6: 267k; R_0201_0603Metric; LCSC C423627
R7: 2.7k; R_0201_0603Metric; LCSC C273271
R11, R13: 1M; R_0201_0603Metric; LCSC C295786
R12: 2.2; R_0402_1005Metric; LCSC C327251
R14, R15, R16, R17: 510; R_0201_0603Metric; LCSC C304550
TCH1: TOUCH_UP_E; TouchPad_4.0x1.6mm
TCH2: TOUCH_DOWN_E; TouchPad_4.0x1.6mm
TCH3: TOUCH_MENU_E; TouchPad_4.0x1.6mm
TCH4: TOUCH_BACK_E; TouchPad_4.0x1.6mm
TP1: VBUS; TestPoint_Pad_D1.0mm
TP2: USB_DM_POGO; TestPoint_Pad_D1.0mm
TP3: USB_DP_POGO; TestPoint_Pad_D1.0mm
TP4: GND; TestPoint_Pad_D1.0mm
TP5: VBAT; TestPoint_Pad_2.0x2.0mm
TP6: GND; TestPoint_Pad_D2.0mm
TP7: VBAT; TestPoint_Pad_D1.5mm
TP8: MOT_N; TestPoint_Pad_D1.5mm
TP9: TXD0; TestPoint_Pad_D1.0mm
TP10: RXD0; TestPoint_Pad_D1.0mm
TP11: EN; TestPoint_Pad_D1.0mm
TP12: BOOT; TestPoint_Pad_D1.0mm
TP13: +3V3; TestPoint_Pad_D1.0mm
U1: ESP32-S3FN8; QFN-56-1EP_7x7mm_P0.4mm_EP4x4mm_Espressif; LCSC C2913196
U2: BQ25101; DSBGA-6_L0.9-W1.6-R2-C3-P0.40-BL; LCSC C478468
U3: TPS62840; DSBGA-6_L1.4-W1.0-R2-C3-P0.40-BL; LCSC C2071139
U4: USBLC6-2P6; SOT-666; LCSC C15999
U6: LIS2DUX12; LGA-12_L2.0-W2.0-P0.50-TL_LIS2DUX12TR; LCSC C17548754
Y1: 40MHz 12pF; Crystal_SMD_2520-4Pin_2.5x2.0mm; LCSC C19076867
Y2: 32.768kHz 12.5pF; CRYSTAL-SMD_L2.1-W1.2-P1.50; LCSC C403709

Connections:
+3V3: C5.1, C6.1, C7.1, C17.1, C20.1, C34.1, C35.1, C36.1, J1.9, L2.1, L4.1, L5.2, R1.1, TP13.1, U1.20 (VDD3P3_RTC), U1.46 (VDD3P3_CPU), U1.55 (VDDA), U1.56 (VDDA), U3.A2 (VOS), U6.2 (CS), U6.3 (SDO/SA0), U6.9 (VDD), U6.10 (VDDIO)
ACC_INT1: U1.15 (GPIO10), U6.12 (INT1)
ACC_INT2: U1.16 (GPIO11), U6.11 (INT2)
BAT_ADC: C18.1, R3.2, R4.1, U1.12 (GPIO7)
BOOT: TP12.1, U1.5 (GPIO0)
BUCK_SW: L5.1, U3.B2 (SW)
BUCK_VSET: R6.1, U3.C2 (VSET)
CHG_ISET: R2.1, R7.1, U2.B2 (ISET)
CHG_ISET_RC: C19.1, R7.2
CHG_STAT: U1.11 (GPIO6), U2.C1 (~CHG)
CHG_TS: R5.1, U2.B1 (TS)
EN: C10.1, R1.2, TP11.1, U1.4 (CHIP_PU)
EPD_BUSY: J1.15, U1.17 (GPIO12)
EPD_CS: J1.12, U1.23 (GPIO17)
EPD_DC: J1.13, U1.19 (GPIO14)
EPD_GDR: J1.18, Q1.1 (G), R11.1
EPD_MOSI: J1.10, U1.27 (GPIO21)
EPD_PUMP: C22.2, D1.1 (K), D2.2 (A)
EPD_RES: J1.14, U1.18 (GPIO13)
EPD_RESE: J1.17, Q1.2 (S), R12.1
EPD_SCK: J1.11, U1.24 (GPIO18)
EPD_SW: C22.1, D3.2 (A), L4.2, Q1.3 (D)
EPD_VCOM: C30.1, J1.1
EPD_VDD: C27.1, J1.7
EPD_VSH1: C28.1, J1.5
EPD_VSHR: C26.1, J1.16
EPD_VSL: C29.1, J1.3
GND: AE1.2 (PCB_Trace), C1.2, C2.2, C3.2, C5.2, C6.2, C7.2, C8.2, C9.2, C10.2, C11.2, C12.2, C13.2, C14.2, C15.2, C17.2, C18.2, C19.2, C20.2, C24.2, C25.2, C26.2, C27.2, C28.2, C29.2, C30.2, C31.2, C32.2, C33.2, C34.2, C35.2, C36.2, D2.1 (K), J1.8, J1.19, J1.20, MIC1.1 (GND), MIC1.2 (L/R), MIC1.3 (GND), Q2.2 (S), R2.2, R4.2, R5.2, R6.2, R11.2, R12.2, R13.2, TP4.1, TP6.1, U1.57 (GND), U2.C2 (VSS), U3.A1 (GND), U4.2 (GND), U6.6 (GND), U6.7 (RES), U6.8 (GND), Y1.2 (G), Y1.4 (G)
I2C_SCL: U1.14 (GPIO9), U6.1 (SCL/SPC)
I2C_SDA: U1.13 (GPIO8), U6.4 (SDA/SDI/SDO)
MIC_CLK: MIC1.6 (CLK), U1.44 (MTCK)
MIC_DATA: MIC1.5 (DATA), U1.43 (GPIO38)
MIC_VDD: C31.1, MIC1.4 (VDD), U1.45 (MTDO)
MOT_N: D4.2 (A), Q2.3 (D), TP8.1
PREVGH: C25.1, D3.1 (K), J1.4
PREVGL: C24.1, D1.2 (A), J1.2
RF_ANT: AE1.1 (FEED), C12.1, L3.2
RF_CHIP: C11.1, L3.1, U1.1 (LNA_IN)
RXD0: TP10.1, U1.50 (U0RXD)
TOUCH_BACK: R17.1, U1.7 (GPIO2)
TOUCH_BACK_E: R17.2, TCH4.1
TOUCH_DOWN: R15.1, U1.6 (GPIO1)
TOUCH_DOWN_E: R15.2, TCH2.1
TOUCH_MENU: R16.1, U1.8 (GPIO3)
TOUCH_MENU_E: R16.2, TCH3.1
TOUCH_UP: R14.1, U1.9 (GPIO4)
TOUCH_UP_E: R14.2, TCH1.1
TXD0: TP9.1, U1.49 (U0TXD)
USB_DM: U1.25 (GPIO19/USB_D-), U4.4 (I/O2)
USB_DM_POGO: TP2.1, U4.3 (I/O2)
USB_DP: U1.26 (GPIO20/USB_D+), U4.6 (I/O1)
USB_DP_POGO: TP3.1, U4.1 (I/O1)
VBAT: C14.1, C15.1, D4.1 (K), R3.1, TP5.1, TP7.1, U2.A1 (OUT), U3.B1 (VIN), U3.C1 (EN)
VBUS: C13.1, TP1.1, U2.A2 (IN), U4.5 (VBUS)
VDD3P3: C3.1, L2.2, U1.2 (VDD3P3), U1.3 (VDD3P3)
VDD_SPI: C8.1, C9.1, U1.29 (VDD_SPI)
VIB: Q2.1 (G), R13.1, U1.10 (GPIO5)
XTAL32_N: C33.1, U1.22 (XTAL_32K_N), Y2.2
XTAL32_P: C32.1, U1.21 (XTAL_32K_P), Y2.1
XTAL_N: C2.1, U1.53 (XTAL_N), Y1.3
XTAL_P: C1.1, L1.2, Y1.1
XTAL_P_L: L1.1, U1.54 (XTAL_P)

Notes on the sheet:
ESP32-S3 + clock
RF match + antenna
Power: pogo USB, charger, LDO
RTC + accelerometer
E-paper connector + booster
Buttons + haptics
Pads (bottom side): pogo, battery, motor, test

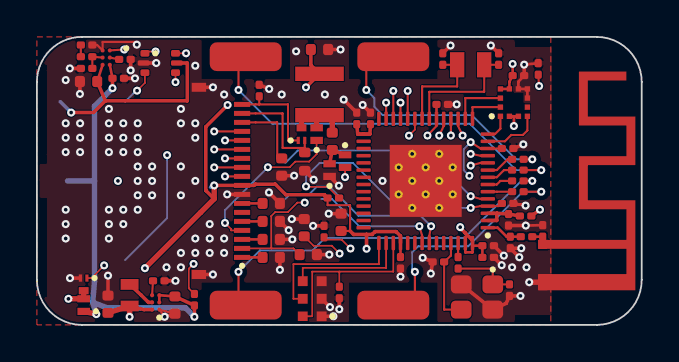
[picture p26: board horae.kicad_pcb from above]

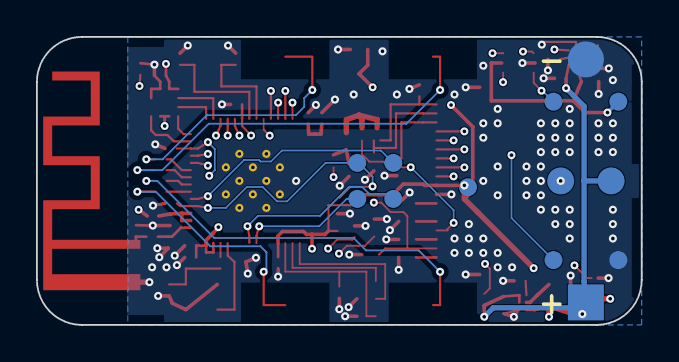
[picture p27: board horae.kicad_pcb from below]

Board: 4 copper layers, 33.6 x 16.0 mm, 84 parts (13 on the bottom side), 62 nets.

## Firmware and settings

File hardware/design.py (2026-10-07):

"""Project Horae rev A netlist: the single source of truth for gen_sch.py and gen_pcb.py.

Each part: (ref, symbol lib_id, value, footprint, LCSC, {pin: net}, block).
Unlisted pins are left unconnected. Reference designs: Espressif ESP32-S3 schematic checklist,
Good Display GDEM0097T61 datasheet p.20, Watchy v3 (sqfmi/watchy-hardware).
"""

R0402, C0402, C0603 = "Resistor_SMD:R_0402_1005Metric", "Capacitor_SMD:C_0402_1005Metric", "Capacitor_SMD:C_0603_1608Metric"
L0402, L0603 = "Inductor_SMD:L_0402_1005Metric", "Inductor_SMD:L_0603_1608Metric"
R0201, C0201, L0201 = "Resistor_SMD:R_0201_0603Metric", "Capacitor_SMD:C_0201_0603Metric", "Inductor_SMD:L_0201_0603Metric"
PAD15, PAD20, PAD20R = "TestPoint:TestPoint_Pad_D1.5mm", "TestPoint:TestPoint_Pad_2.0x2.0mm", "TestPoint:TestPoint_Pad_D2.0mm"
PAD10 = "TestPoint:TestPoint_Pad_D1.0mm"

# LCSC parts (basic where possible). 0201s and the 0.4 mm WCSPs need JLC Standard PCBA (Economic stops at 0402).
C100N, C1U25, C10U = "C66938", "C52923", "C15525"   # C100N is 0201 (space); others basic 0402
C1U = "C76935"   # 1uF 10V 0201 (space)
C18P = "C62164"  # 18pF C0G 0201 (FH 0201CG180J500NT): all four crystal load caps on one line
R10K, R1M, R10M, R20K, R22, R2R2 = "C473048", "C295786", "C3036920", "C295787", "C155743", "C327251"   # 0201 (space; no basic 0201 exists) except R2R2
# R10M: LIZ CR0201FH1005G +-1% (C3036920). Yageo's RC0201FR-0710ML (C469663) carries a 6445-piece minimum buy (~$9 per
# order) with only ~1.2k in stock; C320452 is +-5%. R510 (touch series R): FH RC-01W5100FT +-1% (C304550), not Yageo
# RC0201FR-07510RL (C57784, same 6016-piece / ~$9 minimum buy).
R510 = "C304550"


def R(ref, val, lcsc, a, b, block, fp=R0201):
    return (ref, "Device:R", val, fp, lcsc, {"1": a, "2": b}, block)


def C(ref, val, lcsc, a, b, block, fp=C0201):
    return (ref, "Device:C", val, fp, lcsc, {"1": a, "2": b}, block)


def TP(ref, net, fp, block):
    return (ref, "Connector:TestPoint", net, fp, "", {"1": net}, block)


ESP_PINS = {
    "1": "RF_CHIP", "2": "VDD3P3", "3": "VDD3P3", "4": "EN",
    "5": "BOOT",          # GPIO0 strap: test pad only
    # side facing the antenna (pins 6-14, GPIO1-9): touch, interrupts, haptics, ADC - all RTC GPIOs (deep-sleep wake)
    "6": "TOUCH_DOWN",    # GPIO1  T1
    "7": "TOUCH_BACK",    # GPIO2  T2
    "8": "TOUCH_MENU",    # GPIO3  T3
    "9": "TOUCH_UP",      # GPIO4  T4
    "10": "VIB",          # GPIO5   haptic motor
    "11": "CHG_STAT",     # GPIO6   charger CHG (open drain, low = charging): wake on dock
    "12": "BAT_ADC",      # GPIO7   ADC1_CH6
    "13": "I2C_SDA",      # GPIO8   the accelerometer sits right above these two: I2C runs straight up to its south pads ...
    "14": "I2C_SCL",      # GPIO9   (ULP bit-bangs I2C on any RTC GPIO)
    # side facing the display connector (pins 15-27): SPI + I2C on RTC GPIOs so the ULP core can refresh the time alone
    "15": "ACC_INT1",     # GPIO10  ... and the interrupts straight east to its west pads; step/tap wake
    "16": "ACC_INT2",     # GPIO11
    "17": "EPD_BUSY",     # GPIO12
    "18": "EPD_RES",      # GPIO13
    "19": "EPD_DC",       # GPIO14
    "20": "+3V3",         # VDD3P3_RTC
    "21": "XTAL32_P",     # GPIO15  32.768 kHz crystal: the ESP32 RTC keeps time (no RTC IC; phone sync corrects drift)
    "22": "XTAL32_N",     # GPIO16
    "23": "EPD_CS",       # GPIO17
    "24": "EPD_SCK",      # GPIO18
    "25": "USB_DM", "26": "USB_DP",
    "27": "EPD_MOSI",     # GPIO21
    "43": "MIC_DATA",     # GPIO38  PDM data in (the ROM drives GPIO38 LOW in USB-OTG download mode: harmless on an input)
    "44": "MIC_CLK",      # GPIO39  PDM clock (I2S0 PDM RX); low in download mode = mic asleep
    "45": "MIC_VDD",      # GPIO40  powers the mic directly: 0 uA when off. MTDO is driven HIGH by the ROM in USB-OTG download
                          #         mode (TRM v1.8 Table 33.4-2), so it may only be the mic's VDD, never its DATA output
    "29": "VDD_SPI", "46": "+3V3", "49": "TXD0", "50": "RXD0",
    "53": "XTAL_N", "54": "XTAL_P_L", "55": "+3V3", "56": "+3V3", "57": "GND",
}

PARTS = [
    # --- MCU ---
    ("U1", "MCU_Espressif:ESP32-S3", "ESP32-S3FN8", "horae:QFN-56-1EP_7x7mm_P0.4mm_EP4x4mm_Espressif", "C2913196", ESP_PINS, "mcu"),   # EP: Espressif 3x3 windows + 12 tented vias
    ("Y1", "Device:Crystal_GND24", "40MHz 12pF", "Crystal:Crystal_SMD_2520-4Pin_2.5x2.0mm", "C19076867",
     {"1": "XTAL_P", "2": "GND", "3": "XTAL_N", "4": "GND"}, "mcu"),   # KYX K2C400001210: +-10 ppm, +-20 ppm -40..85 C, ESR <= 40R
    C("C1", "18pF", C18P, "XTAL_P", "GND", "mcu"),     # 2 x (12 - ~3 stray); trim for +-10 ppm in TX-tone mode
    C("C2", "18pF", C18P, "XTAL_N", "GND", "mcu"),
    ("Y2", "Device:Crystal", "32.768kHz 12.5pF", "horae:CRYSTAL-SMD_L2.1-W1.2-P1.50", "C403709",
     {"1": "XTAL32_P", "2": "XTAL32_N"}, "mcu"),                     # 2012, ESR 70k (Espressif: <= 70k)
    C("C32", "18pF", C18P, "XTAL32_P", "GND", "mcu"),  # ~12 pF vs CL 12.5: ~+4 ppm, trimmed in firmware against the 40 MHz
    C("C33", "18pF", C18P, "XTAL32_N", "GND", "mcu"),
    ("L1", "Device:L", "24nH", L0201, "C2991767", {"1": "XTAL_P_L", "2": "XTAL_P"}, "mcu"),  # Espressif: series L on XTAL_P
    ("L2", "Device:L", "2nH", L0201, "C86125", {"1": "+3V3", "2": "VDD3P3"}, "mcu"),       # LC filter on VDD3P3
    C("C3", "1uF", C1U, "VDD3P3", "GND", "mcu"),
    C("C5", "10uF", C10U, "+3V3", "GND", "mcu", C0402),   # bulk at the ESP32 (the buck sits at the far end)
    C("C6", "1uF", C1U, "+3V3", "GND", "mcu"),            # VDDA pins 55/56 (Espressif reference schematic: C3 1 uF + C2 10 nF), at the pins on F.Cu
    C("C36", "10nF", "C326875", "+3V3", "GND", "mcu"),    # VDDA HF bypass, next to C6 (same 10 nF line as C19)
    C("C7", "100nF", C100N, "+3V3", "GND", "mcu"),        # ends up at U6 Vdd/Vdd_IO (C20 is the one at pin 20)
    C("C34", "100nF", C100N, "+3V3", "GND", "mcu"),       # VDD3P3_CPU pin 46 (Espressif ref C10): place at the pin
    C("C8", "1uF", C1U, "VDD_SPI", "GND", "mcu"),
    C("C9", "100nF", C100N, "VDD_SPI", "GND", "mcu"),
    R("R1", "10k", R10K, "+3V3", "EN", "mcu"),
    C("C10", "1uF", C1U, "EN", "GND", "mcu"),
    # RF: match from the openEMS sim of the trimmed antenna in the two-shell case with spring bars (hardware/rf, report_v3); C12 is a tuning spot
    C("C11", "0.5pF", "C85920", "RF_CHIP", "GND", "rf"),        # Murata GRM0335C1HR50BA01D +-0.1 pF
    ("L3", "Device:L", "0.8nH", L0201, "C156227", {"1": "RF_CHIP", "2": "RF_ANT"}, "rf"),   # Murata LQP03TN0N8B02D +-0.1 nH: match from RF v4, 2026-10-06 (LQP03HQ0N8B02D C2043648 is the higher-Q alternative)
    C("C12", "DNP", "", "RF_ANT", "GND", "rf"),
    ("AE1", "Device:Antenna_Chip", "PCB IFA", "horae:SWRA117D", "", {"1": "RF_ANT", "2": "GND"}, "rf"),

    # --- power: pogo USB in -> BQ25101 linear charger (IN rated 30 V, but U4 clamps VBUS from ~6 V; <= 75 nA battery drain) -> TPS62840 buck ---
    ("U2", "horae:BQ25101YFPR", "BQ25101", "horae:DSBGA-6_L0.9-W1.6-R2-C3-P0.40-BL", "C478468",
     {"A1": "VBAT", "A2": "VBUS", "B1": "CHG_TS", "B2": "CHG_ISET", "C1": "CHG_STAT", "C2": "GND"}, "power"),
    R("R2", "6.8k", "C274877", "CHG_ISET", "GND", "power"),     # 135 A*ohm / 6.8k = 19.9 mA = 0.5C of a 40 mAh cell (5.6k only if >= 48 mAh)
    R("R7", "2.7k", "C273271", "CHG_ISET", "CHG_ISET_RC", "power"),   # SLUSBV8C 8.3.6/9.2.2: ISET RC for ICHG < 50 mA, at U2.B2
    C("C19", "10nF", "C326875", "CHG_ISET_RC", "GND", "power"),
    R("R5", "10k", R10K, "CHG_TS", "GND", "power"),              # no NTC: 10k on TS per datasheet
    C("C13", "4.7uF/25V", "C2858031", "VBUS", "GND", "power", C0402),   # IN 1-10 uF: the 1uF/10V 0201 kept ~0.24 uF at 5 V; at U2.A2
    C("C14", "1uF", C1U, "VBAT", "GND", "power"),              # charger OUT cap at U2.A1, TI typ. app. (C15 is 13 mm away at the buck)
    C("C15", "10uF", C10U, "VBAT", "GND", "power", C0402),     # buck VIN
    ("U3", "horae:TPS62840YBGR", "TPS62840", "horae:DSBGA-6_L1.4-W1.0-R2-C3-P0.40-BL", "C2071139",
     {"A1": "GND", "A2": "+3V3", "B1": "VBAT", "B2": "BUCK_SW", "C1": "VBAT", "C2": "BUCK_VSET"}, "power"),
    ("L5", "Device:L", "2.2uH", "horae:IND-SMD_L1.6-W0.8", "C31123918", {"1": "BUCK_SW", "2": "+3V3"}, "power"),   # LSCND1608HKT2R2MF: 0.8 mm, Isat 1.3 A, 0.20 ohm
    R("R6", "267k", "C423627", "BUCK_VSET", "GND", "power"),    # VSET table: 267k -> 3.3 V
    C("C17", "10uF", C10U, "+3V3", "GND", "power", C0402),     # buck output
    R("R3", "10M", R10M, "VBAT", "BAT_ADC", "power"),     # 0.2 uA divider; calibrate per board at the 4.20 V end of charge
    R("R4", "10M", R10M, "BAT_ADC", "GND", "power"),
    C("C18", "100nF", C100N, "BAT_ADC", "GND", "power"),
    ("U4", "Power_Protection:USBLC6-2P6", "USBLC6-2P6", "Package_TO_SOT_SMD:SOT-666", "C15999",   # genuine ST (C2827693 is TECH PUBLIC)
     {"1": "USB_DP_POGO", "2": "GND", "3": "USB_DM_POGO", "4": "USB_DM", "5": "VBUS", "6": "USB_DP"}, "power"),
    # Flow-through ESD (ST DS4260 fig. 17): the pogo pads enter U4 on pins 1/3 (I/O1/I/O2) and leave from pins 6/4 to the ESP32,
    # so the clamp sits on the path, not on a stub. Pins 1-6 and 3-4 are joined inside the USBLC6.

    # --- sensors ---
    ("U6", "horae:LIS2DUX12TR", "LIS2DUX12", "horae:LGA-12_L2.0-W2.0-P0.50-TL_LIS2DUX12TR", "C17548754",
     {"1": "I2C_SCL", "2": "+3V3", "3": "+3V3", "4": "I2C_SDA", "6": "GND", "7": "GND", "8": "GND", "9": "+3V3",
      "10": "+3V3", "11": "ACC_INT2", "12": "ACC_INT1"}, "sensors"),   # CS=VDDIO -> I2C, SA0=VDDIO -> 0x19 (ties to the CS pin next to it); DS14071 Table 1: pin 5 NC, pin 7 RES/EXT_CLK to GND
    C("C20", "100nF", C100N, "+3V3", "GND", "sensors"),
    # I2C (accelerometer only) uses the ESP32 internal pull-ups (~45k): ~0.6 us rise at 100 kHz on this short bus

    # --- display: GDEM0097T61 via FH34SRJ, booster per GD typical application circuit ---
    # FH34SRJ: the FPC slot is on the fitting-nail side and the tails sit under the back-flip actuator (Hirose catalog p.2/6/8),
    # so J1 turns 180 deg (gen_pcb.py) to face the U-bend at -X. Display pin 1 (GDR) stays at -Y and meets contact 18: pad = 19 - pin.
    ("J1", "horae:FH34SRJ-18S-0.5SH", "FH34SRJ-18S-0.5SH(50)", "horae:FFC-SMD_18P-P0.50_FH34SRJ-18S-0.5SH", "C3169386",
     {"18": "EPD_GDR", "17": "EPD_RESE", "16": "EPD_VSHR", "15": "EPD_BUSY", "14": "EPD_RES", "13": "EPD_DC",
      "12": "EPD_CS", "11": "EPD_SCK", "10": "EPD_MOSI", "9": "+3V3", "8": "GND", "7": "EPD_VDD",
      "5": "EPD_VSH1", "4": "PREVGH", "3": "EPD_VSL", "2": "PREVGL", "1": "EPD_VCOM",
      "19": "GND", "20": "GND"}, "display"),          # pad 6 = display pin 13 (VPP, "keep open")
    ("Q1", "horae:PMZ390UN,315", "PMZ390UN", "horae:SOT-883-3_L1.0-W0.6-BR", "C458236",
     {"1": "EPD_GDR", "2": "EPD_RESE", "3": "EPD_SW"}, "display"),
    ("L4", "Device:L", "47uH", "horae:IND-SMD_L3.0-W3.0_SWPA3010S", "C96826", {"1": "+3V3", "2": "EPD_SW"}, "display"),   # Sunlord SWPA3010S470MT, catalog land 0.8 x 2.7: 3x3x1.0, Isat 0.22 A rated / 0.35 typ, DCR 1.95 ohm
    C("C35", "10uF", C10U, "+3V3", "GND", "display", C0402),   # booster/VCI input bulk at L4 pin 1 (GD p.20 C4 4.7 uF)
    R("R11", "1M", R1M, "EPD_GDR", "GND", "display"),
    R("R12", "2.2", R2R2, "EPD_RESE", "GND", "display", R0402),   # booster current sense (>= 0.05 W): 0402
    ("D1", "Device:D_Schottky", "PMEG3002AEL", "horae:SOD-882_L1.0-W0.6-RD", "C478015", {"1": "EPD_PUMP", "2": "PREVGL"}, "display"),
    ("D2", "Device:D_Schottky", "PMEG3002AEL", "horae:SOD-882_L1.0-W0.6-RD", "C478015", {"1": "GND", "2": "EPD_PUMP"}, "display"),
    ("D3", "Device:D_Schottky", "PMEG3002AEL", "horae:SOD-882_L1.0-W0.6-RD", "C478015", {"1": "PREVGH", "2": "EPD_SW"}, "display"),
    C("C22", "4.7uF/25V", "C2858031", "EPD_SW", "EPD_PUMP", "display", C0402),
    C("C24", "2.2uF/25V", "C307418", "PREVGL", "GND", "display", C0402),   # +-15..20 V rail: 0.17-0.24 uF left vs 0.07-0.10
    C("C25", "2.2uF/25V", "C307418", "PREVGH", "GND", "display", C0402),   # +-15..20 V rail: 0.17-0.24 uF left vs 0.07-0.10
    C("C26", "1uF/25V", C1U25, "EPD_VSHR", "GND", "display", C0402),
    C("C27", "1uF/25V", C1U25, "EPD_VDD", "GND", "display", C0402),
    C("C28", "2.2uF/25V", "C307418", "EPD_VSH1", "GND", "display", C0402),   # +-15..20 V rail: 0.17-0.24 uF left vs 0.07-0.10
    C("C29", "2.2uF/25V", "C307418", "EPD_VSL", "GND", "display", C0402),   # +-15..20 V rail: 0.17-0.24 uF left vs 0.07-0.10
    C("C30", "1uF/25V", C1U25, "EPD_VCOM", "GND", "display", C0402),

    # --- UI: capacitive touch + haptics + mic ---
    ("MIC1", "horae:LMD2718T261-OA1", "LMD2718T261", "horae:MIC-SMD_6P-L2.8-W1.9-P0.98-TL", "C5373237",
     {"1": "GND", "2": "GND", "3": "GND", "4": "MIC_VDD", "5": "MIC_DATA", "6": "MIC_CLK"}, "ui"),   # top-port PDM, L/R=GND (left)
    C("C31", "100nF", C100N, "MIC_VDD", "GND", "ui"),
    TP("TCH1", "TOUCH_UP_E", "horae:TouchPad_4.0x1.6mm", "ui"), TP("TCH2", "TOUCH_DOWN_E", "horae:TouchPad_4.0x1.6mm", "ui"),
    TP("TCH3", "TOUCH_MENU_E", "horae:TouchPad_4.0x1.6mm", "ui"), TP("TCH4", "TOUCH_BACK_E", "horae:TouchPad_4.0x1.6mm", "ui"),
    *[R(r, "510", R510, n, n + "_E", "ui") for r, n in (("R14", "TOUCH_UP"), ("R15", "TOUCH_DOWN"),
                                                             ("R16", "TOUCH_MENU"), ("R17", "TOUCH_BACK"))],   # HDG 1.3.14: 510R within 1 mm of the pin
    ("Q2", "horae:PMZ390UN,315", "PMZ390UN", "horae:SOT-883-3_L1.0-W0.6-BR", "C458236",
     {"1": "VIB", "2": "GND", "3": "MOT_N"}, "ui"),            # coin ERM low-side switch (~80 mA)
    R("R13", "1M", R1M, "VIB", "GND", "ui"),                     # gate pull-down: motor off while the ESP32 boots
    ("D4", "Device:D_Schottky", "PMEG3002AEL", "horae:SOD-882_L1.0-W0.6-RD", "C478015", {"1": "VBAT", "2": "MOT_N"}, "ui"),   # flyback (0.2 A cont., 1 A rep. peak)

    # --- pads (bottom side; no parts) ---
    TP("TP1", "VBUS", PAD10, "pads"), TP("TP2", "USB_DM_POGO", PAD10, "pads"),
    TP("TP3", "USB_DP_POGO", PAD10, "pads"), TP("TP4", "GND", PAD10, "pads"),
    TP("TP5", "VBAT", PAD20, "pads"), TP("TP6", "GND", PAD20R, "pads"),         # battery wires: + square, - round
    TP("TP7", "VBAT", PAD15, "pads"), TP("TP8", "MOT_N", PAD15, "pads"),        # coin motor leads (soldered)
    TP("TP9", "TXD0", PAD10, "pads"), TP("TP10", "RXD0", PAD10, "pads"),
    TP("TP11", "EN", PAD10, "pads"), TP("TP12", "BOOT", PAD10, "pads"), TP("TP13", "+3V3", PAD10, "pads"),
]

POWER_NETS = ["GND", "+3V3", "VBAT", "VBUS", "VDD3P3", "VDD_SPI"]   # get PWR_FLAGs (VDD_SPI is driven inside the ESP32)

if __name__ == "__main__":
    refs = [p[0] for p in PARTS]
    assert len(refs) == len(set(refs)), "duplicate refs"
    nets = {}
    for p in PARTS:
        for pin, net in p[5].items():
            nets.setdefault(net, []).append(f"{p[0]}.{pin}")
    lonely = {n: v for n, v in nets.items() if len(v) < 2}
    assert not lonely, f"single-pin nets: {lonely}"
    placed = [p for p in PARTS if p[4]]
    print(f"{len(PARTS)} parts ({len(placed)} JLC-placed), {len(nets)} nets, {len({p[4] for p in placed})} unique LCSC lines")

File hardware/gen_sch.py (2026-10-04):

"""Generate horae.kicad_sch from design.py: every symbol placed by block, pins joined by net labels.

Run inside the KiCad container: ./kicad python3 gen_sch.py
"""
import copy, os, uuid
from sexpr import parse, dump, q, uq, find, first
from design import PARTS, POWER_NETS

SYMDIR = "/usr/share/kicad/symbols"
ROOT = str(uuid.uuid5(uuid.NAMESPACE_URL, "projecthorae.com/rev-a"))
_libs = {}


def uid(*k):
    return str(uuid.uuid5(uuid.NAMESPACE_URL, "horae/" + "/".join(map(str, k))))


def lib(name):
    if name not in _libs:
        path = "lib/horae.kicad_sym" if name == "horae" else f"{SYMDIR}/{name}.kicad_sym"
        _libs[name] = parse(open(path).read())
    return _libs[name]


def load_symbol(lib_id):
    """Return a flattened copy of the library symbol, renamed to lib_id for embedding."""
    libname, name = lib_id.split(":")
    syms = {uq(s[1]): s for s in find(lib(libname), "symbol")}
    s = copy.deepcopy(syms[name])
    ext = first(s, "extends")
    if ext:
        parent = copy.deepcopy(syms[uq(ext[1])])
        pname = uq(ext[1])
        props = {uq(p[1]): p for p in find(s, "property")}
        body = []
        for e in parent[2:]:
            if isinstance(e, list) and e[0] == "property" and uq(e[1]) in props:
                body.append(props.pop(uq(e[1])))
            elif isinstance(e, list) and e[0] == "symbol":
                e[1] = q(uq(e[1]).replace(pname, name, 1))
                body.append(e)
            else:
                body.append(e)
        s = [s[0], s[1]] + list(props.values()) + body
    s[1] = q(lib_id)
    if libname == "horae":  # LCSC-imported symbols leave pin types unspecified
        for sub in find(s, "symbol"):
            for p in find(sub, "pin"):
                if p[1] == "unspecified":
                    p[1] = "passive"
    return s


def pins(sym):
    out = []
    for sub in find(sym, "symbol"):
        unit = uq(sub[1]).rsplit("_", 2)[-2]
        if unit not in ("0", "1"):
            continue
        for p in find(sub, "pin"):
            at = first(p, "at")
            out.append((uq(first(p, "number")[1]), float(at[1]), float(at[2]), int(float(at[3]))))
    return out


def bbox(sym):
    xs, ys = [], []
    for sub in find(sym, "symbol"):
        for g in sub:
            if not isinstance(g, list):
                continue
            if g[0] == "pin":
                at = first(g, "at"); xs.append(float(at[1])); ys.append(float(at[2]))
            for key in ("start", "end", "xy", "center"):
                for pt in ([first(g, key)] if key != "xy" else [x for pl in find(g, "pts") for x in find(pl, "xy")]):
                    if pt:
                        xs.append(float(pt[1])); ys.append(float(pt[2]))
    return (min(xs), min(ys), max(xs), max(ys)) if xs else (-2.54, -2.54, 2.54, 2.54)


def snap(v, g=1.27):
    return round(round(v / g) * g, 4)


def prop(name, val, x, y, hide=False, justify="left"):
    eff = ["effects", ["font", ["size", "1.27", "1.27"]], ["justify", justify]]
    if hide:
        eff.append(["hide", "yes"])
    return ["property", q(name), q(val), ["at", f"{x:.2f}", f"{y:.2f}", "0"], eff]


BLOCKS = {  # x0, y0, width (mm, A2 sheet)
    "mcu": (20, 25, 200, "ESP32-S3 + clock"), "rf": (20, 250, 200, "RF match + antenna"),
    "power": (235, 25, 160, "Power: pogo USB, charger, LDO"), "sensors": (235, 220, 160, "RTC + accelerometer"),
    "display": (410, 25, 170, "E-paper connector + booster"), "ui": (410, 260, 170, "Buttons + haptics"),
    "pads": (20, 345, 560, "Pads (bottom side): pogo, battery, motor, test"),
}


def main():
    lib_symbols, items, used = [], [], {}
    cursor = {b: [x0, y0 + 10, y0 + 10] for b, (x0, y0, w, t) in BLOCKS.items()}  # x, y, row bottom
    for b, (x0, y0, w, title) in BLOCKS.items():
        items.append(["text", q(title), ["exclude_from_sim", "no"], ["at", str(x0), str(y0), "0"],
                      ["effects", ["font", ["size", "2.5", "2.5"], ["bold", "yes"]], ["justify", "left", "bottom"]],
                      ["uuid", q(uid("t", b))]])
    flags = [(f"#FLG{i+1}", "power:PWR_FLAG", "PWR_FLAG", "", "", {"1": n}, "power") for i, n in enumerate(POWER_NETS)]
    for ref, lib_id, value, fp, lcsc, pinmap, block in PARTS + flags:
        if lib_id not in used:
            used[lib_id] = load_symbol(lib_id)
            lib_symbols.append(used[lib_id])
        sym = used[lib_id]
        x0, y0, w, _ = BLOCKS[block]
        minx, miny, maxx, maxy = bbox(sym)
        lab = 2 + 1.1 * max([len(n) for n in pinmap.values()] + [4])
        cw, ch = (maxx - minx) + 2 * lab, (maxy - miny) + 9
        cx, cy, rowb = cursor[block]
        if cx + cw > x0 + w and cx > x0:
            cx, cy = x0, rowb + 2
        X, Y = snap(cx + lab - minx, 2.54), snap(cy + 4 + maxy, 2.54)
        cursor[block] = [cx + cw, cy, max(rowb, cy + ch)]

        inst = ["symbol", ["lib_id", q(lib_id)], ["at", f"{X:.2f}", f"{Y:.2f}", "0"], ["unit", "1"],
                ["exclude_from_sim", "no"], ["in_bom", "no" if ref.startswith(("#", "TP")) else "yes"],
                ["on_board", "no" if ref.startswith("#") else "yes"], ["dnp", "yes" if value.startswith("DNP") else "no"], ["uuid", q(uid("s", ref))],
                prop("Reference", ref, X + minx, Y - maxy - 1.5, hide=ref.startswith("#")),
                prop("Value", value, X + minx, Y - miny + 2.5, hide=ref.startswith("#")),
                prop("Footprint", fp, X, Y, hide=True), prop("Datasheet", "", X, Y, hide=True)]
        if lcsc:
            inst.append(prop("LCSC", lcsc, X, Y, hide=True))
        seen = {}
        for num, px, py, ang in pins(sym):
            inst.append(["pin", q(num), ["uuid", q(uid("p", ref, num))]])
            sx, sy = round(X + px, 4), round(Y - py, 4)
            net = pinmap.get(num)
            key = (sx, sy)
            if key in seen and seen[key] != net:
                raise SystemExit(f"{ref}: stacked pins at {key} have different nets {seen[key]} / {net}")
            if key in seen:
                continue
            seen[key] = net
            if net is None:
                items.append(["no_connect", ["at", f"{sx}", f"{sy}"], ["uuid", q(uid("nc", ref, num))]])
                continue
            la = {0: 180, 180: 0, 90: 270, 270: 90}[ang % 360]
            just = "left" if la in (0, 90) else "right"
            items.append(["label", q(net), ["at", f"{sx}", f"{sy}", str(la)], ["fields_autoplaced", "yes"],
                          ["effects", ["font", ["size", "1", "1"]], ["justify", just, "bottom"]],
                          ["uuid", q(uid("l", ref, num))]])
        missing = set(pinmap) - {p[0] for p in pins(sym)}
        if missing:
            raise SystemExit(f"{ref} ({lib_id}) has no pins {missing}")
        inst.append(["instances", ["project", q("horae"), ["path", q("/" + ROOT), ["reference", q(ref)], ["unit", "1"]]]])
        items.append(inst)
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

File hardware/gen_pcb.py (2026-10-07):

"""Generate horae.kicad_pcb from design.py + spec.py: outline, stack, placement, nets, zones, keep-outs, DSN.

Run inside the KiCad container: ./kicad python3 gen_pcb.py
Critical parts are pinned (decoupling at its pins, crystals, RF chain, touch resistors, buck, charger); the rest go to the
free spot nearest their target (greedy legalizer, biggest first). A part that lands > 1 mm from its target fails the build.
"""
import math, os, re, sys
import pcbnew
sys.path.insert(0, "..")
import spec as S
from design import PARTS, ESP_PINS
ESP_NET = {int(k): v for k, v in ESP_PINS.items()}
from gen_sch import uid

MM = pcbnew.FromMM
OX, OY = 100.0, 100.0                 # board centre on the KiCad canvas
X0, X1 = -S.PCB_L / 2, S.PCB_L / 2
Y0, Y1 = -S.PCB_W / 2, S.PCB_W / 2
EDGE = 0.15                            # courtyard-to-edge margin
VIA_D, VIA_H = 0.45, 0.2               # JLC's free 4-layer via class: 0.2 mm holes cost extra (+Kelvin test, TG155) below a 0.45 mm pad
RF_W, RF_GAP = 0.15, 0.15              # 50 ohm GCPW on F.Cu over In1 in JLC04061H-3313 (3313 0.0994 mm, Er 4.1, LPI mask): 50.3 ohm
POWER_W = 0.3                          # power class (Freerouting necks it down at 0.4 mm-pitch pads)
TOUCH_KEEP = 0.5                       # no other copper within this of an electrode, on any layer
DRIFT_MAX = 1.0                        # legalizer: fail when a part lands further than this from its target
U1_XY = (4.8, 0.0)
POWER_NETS = ["BUCK_SW", "EPD_SW"]                            # 0.3 mm: the two switch nodes (drawn by hand)
SUPPLY_NETS = ["+3V3", "VBAT", "VBUS", "MOT_N"]                # 0.2 mm: <= 0.35 A peaks (WiFi TX) = 17 mV over 20 mm
TOUCH_NETS = ["TOUCH_UP_E", "TOUCH_DOWN_E", "TOUCH_MENU_E", "TOUCH_BACK_E"]
F_ONLY_NETS = ["XTAL_P", "XTAL_N", "XTAL_P_L", "VDD3P3"]   # 40 MHz crystal and the PA supply: F.Cu, no vias
# panel tabs (panel.py mills a 2 mm slot around the board except here; 5 x 0.6 mm mouse bites reaching 1/3 into the board,
# JLC, so no nub stands proud of the outline): two at the -X end either side of the case's centring rib at y 0, and both
# long edges past the rib at x 8.5 (>= 1.5 mm from every rib). Tracks, vias and parts stay >= 1.2 mm from a tab (the -X
# tabs pass 0.8 mm from the bare VBUS/GND pogo pads, the only copper there), pours >= 0.6 mm
TAB_GAP, TAB_HOLE, TAB_PITCH, TAB_HOLES = 2.0, 0.6, 0.95, 5
RIBS = [(-12.0, Y0), (-12.0, Y1), (8.5, Y0), (8.5, Y1), (X0, 0.0), (X1, 0.0)]     # case crush ribs (cad/horae.py)
TABS = [((X0, 1.5), (X0, 5.9)), ((X0, -5.9), (X0, -1.5)), ((10.3, Y0), (14.7, Y0)), ((10.3, Y1), (14.7, Y1))]   # 4.4 mm (5 holes):
# the straight edges stop at the R2.5 corners (x +-14.3, y +-5.5), so each tab ends <= 0.4 mm into an arc (< 0.04 mm off line)
assert all(min(math.hypot(rx - x, ry - y) for x, y in (a, b)) >= 1.5 and not (min(a[0], b[0]) < rx < max(a[0], b[0]) or min(a[1], b[1]) < ry < max(a[1], b[1]))
           for a, b in TABS for rx, ry in RIBS if (a[0] == b[0] == rx) or (a[1] == b[1] == ry)), "tab too close to a rib"
TAB_POUR_BACK, TAB_COPPER_BACK, TAB_PART_BACK = 0.6, 1.2, 1.0   # from the edge at a tab: pours, tracks/vias, courtyards
FPC_SLOT_X = S.FFC_X - 1.75                 # J1's slot face (nail side) toward the U-bend at -X
FPC_LANE = (X0 - 1, -S.FPC_W / 2 - 0.3, FPC_SLOT_X, S.FPC_W / 2 + 0.3)    # the ribbon runs here just above the board
LEDGES = [(X0 - 1, Y0 - 1, S.DISP_X0 + S.LEDGE, -S.LEDGE_Y), (X0 - 1, S.LEDGE_Y, S.DISP_X0 + S.LEDGE, Y1 + 1)]  # case ledges
# 3D model z fixes (STEP truthfulness for the case check): ref -> (datasheet max height, model z min, model z max)
HEIGHT = {"U6": (0.74, 0.0, 1.021), "Y1": (0.60, 0.0, 0.83), "L5": (0.80, -0.01, 0.71), "L4": (1.00, 0.0, 1.01),
          "U2": (0.50, -0.48, 0.03), "U3": (0.50, -0.38, 0.021), "Q1": (0.50, -0.231, 0.27), "Q2": (0.50, -0.231, 0.27)}
POLAR = {"U1": "1", "U2": "A1", "U3": "A1", "U4": "1", "U6": "1", "J1": "1", "Q1": "1", "Q2": "1", "MIC1": "1", "Y1": "1",
         "D1": "1", "D2": "1", "D3": "1", "D4": "1"}   # F.Silkscreen pin-1 dot / cathode bar (JLC checks polarity against silk)

# Pinned parts not covered by the hand-placed clusters below.
PIN = {
    "J1": (S.FFC_X, 0.0, None),
    # capacitive touch electrodes along the long edges (TCH1 UP, TCH2 DOWN at +X; TCH3 MENU, TCH4 BACK at -X)
    "TCH1": (S.TOUCH_X[1], Y0 + S.TOUCH_W / 2 + 0.3, 0), "TCH2": (S.TOUCH_X[1], Y1 - S.TOUCH_W / 2 - 0.3, 0),
    "TCH3": (S.TOUCH_X[0], Y0 + S.TOUCH_W / 2 + 0.3, 0), "TCH4": (S.TOUCH_X[0], Y1 - S.TOUCH_W / 2 - 0.3, 0),
}
BOTTOM = {  # bottom-side pads (no parts): dock pogo pads, battery wire pads, motor lead pads, test pads
    **{tp: next(p[:2] for p in S.POGO_PADS if p[2] == net) for tp, net in (("TP1", "VBUS"), ("TP2", "USB_DM"), ("TP3", "USB_DP"), ("TP4", "GND"))},
    "TP5": (S.BATPAD_X, S.BATPAD_Y), "TP6": (S.BATPAD_X, -S.BATPAD_Y),   # VBAT next to the charger, GND next to the ESD
    "TP7": (S.MOTOR_X - S.MOTOR_PAD_DX, 0.0), "TP8": (S.MOTOR_X + S.MOTOR_PAD_DX, 0.0),
    # debug pads (TX, RX, EN, BOOT) between J1 and U1, over the flat part of the pouch (its PCM end is x -10.1..-8.0):
    # a 2 mm grid, 1 mm gaps for probes or wire tacks
    "TP9": (-1.0, 1.0), "TP10": (-3.0, 1.0), "TP11": (-1.0, -1.0), "TP12": (-3.0, -1.0), "TP13": (-7.15, 0.35),
}
TARGET = {  # loose targets for the legalizer (KiCad coords, y down)
    "R4": (-0.3, 3.4),
    "C25": (-1.95, 2.6), "C24": (-1.75, 4.05),
}


def fp_path(lib):
    return "lib/horae.pretty" if lib == "horae" else f"/usr/share/kicad/footprints/{lib}.pretty"


def V(x, y):
    return pcbnew.VECTOR2I(MM(OX + x), MM(OY + y))


def P(v):
    return (pcbnew.ToMM(v.x) - OX, pcbnew.ToMM(v.y) - OY)


def box(fp):
    lay = pcbnew.B_CrtYd if fp.IsFlipped() else pcbnew.F_CrtYd
    fp.BuildCourtyardCaches()          # cached outline does not follow SetPosition otherwise
    cy = fp.GetCourtyard(lay)
    b = cy.BBox() if cy.OutlineCount() else fp.GetBoundingBox(False)
    r = [pcbnew.ToMM(b.GetLeft()) - OX, pcbnew.ToMM(b.GetTop()) - OY, pcbnew.ToMM(b.GetRight()) - OX, pcbnew.ToMM(b.GetBottom()) - OY]
    for pad in fp.Pads():              # some imported courtyards do not cover their pads; pads + 0.15 mm always count
        if not (pad.IsOnLayer(pcbnew.F_Cu) or pad.IsOnLayer(pcbnew.B_Cu)):
            continue
        pb = pad.GetBoundingBox()
        r = [min(r[0], pcbnew.ToMM(pb.GetLeft()) - OX - 0.15), min(r[1], pcbnew.ToMM(pb.GetTop()) - OY - 0.15),
             max(r[2], pcbnew.ToMM(pb.GetRight()) - OX + 0.15), max(r[3], pcbnew.ToMM(pb.GetBottom()) - OY + 0.15)]
    return tuple(r)


def overlap(a, b, m=0.05):
    return a[0] < b[2] + m and b[0] < a[2] + m and a[1] < b[3] + m and b[1] < a[3] + m
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

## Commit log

2026-10-03 Day 0: landing timeline + initial research
2026-10-03 Day 0: first decisions + prototype v0 plan
2026-10-03 Prototype plan: hand-soldered XIAO carrier PCB instead of breadboard
2026-10-03 v0 BOM, display connector, size estimates
2026-10-03 Draft build plan for custom rev A board
2026-10-04 Build plan: rev A optimizations (PICO-1 SiP, BMA400, stack-up, power budget)
2026-10-04 Build plan: JLC full-assembly estimate with live stock
2026-10-04 Landing: newest-first timeline, current plan entry, OG/Twitter image and tags
2026-10-04 Rev A hardware: generated KiCad schematic + routed 4-layer board (ERC/DRC clean), JLC outputs
    [horae.kicad_pcb, horae.kicad_sch, horae.step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]
2026-10-04 Rev A: hand-routed 50-ohm RF feed, antenna clear of glass, standard vias, cost breakdown; splash-resistant PETG-CF case with TPU gaskets and PETG RF window
    [back-cf+petg.3mf, back_cf.3mf, back_cf.stl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]
2026-10-04 Rev A: antenna trimmed 6.64 mm + re-matched from openEMS sim (C11 0.9p, L3 0.6n, C12 DNP); timeline entry with review renders
    [horae.kicad_pcb, horae.kicad_sch, horae.step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]
2026-10-04 Landing: photo lightbox (native dialog, arrows/keys/swipe) instead of opening images
2026-10-04 Rev A: haptics back (spring-contact coin ERM + CJ3134K), LIS2DUX12 replaces BMA400 (-$10.9/board), GND escape vias, hole-to-hole spacing; DRC clean
    [horae.kicad_pcb, horae.kicad_sch, horae.step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]
2026-10-04 Rev A: capacitive touch (no switches), 6 mm spring-contact motor, full-size battery (25.3x16x2.5), pogo/battery pads in motor-zone corners, PPG hookup pads, RF router class; DRC clean
    [back-cf+petg.3mf, back_cf.3mf, back_cf.stl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]
2026-10-04 Rev A: top-port PDM mic (LMD2718T261, GPIO-powered, 0 uA off) in the -X corner; DRC clean
    [back-cf+petg.3mf, back_cf.3mf, back_cf.stl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]
2026-10-04 Case: pebble shape, solid touch windows, 16 mm spring-bar lugs, mic duct + vent, 6 mm motor pocket, full battery; spec Y-convention note
    [back-cf+petg.3mf, back_cf.3mf, back_rf.3mf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]
2026-10-04 Site: Rev A entry reflects current design (touch, LIS2DUX12, motor, mic, pebble case, spring bars); refreshed board renders
2026-10-05 Rev A slim: 33.8 x 16.2 x 0.6 mm board, case under a Charge 3 (35.6 x 18.0 x 7.05)
    - Board: 16.2 mm wide (was 18.0), 2.8 mm antenna zone past the glass, 0.6 mm 4-layer;
    ERC 0, DRC 0 errors / 0 warnings / 0 unconnected, every signal routed on the first pass.
    - Tallest part 1.0 mm (was 1.2): PMZ390UN MOSFETs (SOT-883), PMEG3005EL Schottkys
    (SOD-882), FNR3010 47 uH 3x3x1.0, 0402 4.7 uF/25 V; SSD1681 reference values.
    - RTC IC dropped: 32.768 kHz crystal on GPIO15/16 runs the ESP32 RTC (Watchy v3 /
    Yatchy approach, -$3.44).
    - Power: BQ25101 charger (75 nA drain, 28 V input, 24 mA for the 40-55 mAh cell) and
    TPS62840 buck (60 nA Iq, 267k VSET -> 3.3 V) replace TP4054 + RT9080; hand-placed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
    [horae.kicad_pcb, horae.kicad_sch, horae.step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]
2026-10-05 RF: re-simulated for the 0.6 mm board, slim case, spring bars and strap
    Model now builds the stack from spec.PCB_T, takes each layer's real ground copper from the
    board, and follows the case/strap geometry in spec.py + cad/horae.py. Keep the 6.64 mm trim;
    new match C11 0.3 pF / L3 1.2 nH: in-band S11 -9.2..-14.7 dB in case, -9.1..-13.7 dB on the
    wrist; efficiency ~0.74 in case incl. the match (the old wrist figure was a measurement-box
    artefact). Spring bar +-1 mm sensitivity and a 0.07 mm mesh check included.
2026-10-05 Case: slim 35.6 x 18.0 x 7.05 mm, lugs fused to the side walls, 6.55 mm thin variant
    - Spring-bar ears are now one solid with the frame (the skin clip had cut them off), drilled
    through for 16 mm bars, 43.1 mm lug to lug; strap swings -30..+90 deg clear.
    - New stack from spec (0.6 PCB, 1.0 parts, 3.0 cell + PCM recess, 0.5 floor, 0.4 lip).
    - 6 x 2.5 coin motor on foam tape with soldered leads; battery soldered to the pads.
    - Dock pins placed from spec POGO_PADS and checked against the board's pad nets.
    - Renders go to media/2026-10-04; scale view vs Charge 3 and the previous pass.
    [back-cf+petg.3mf, back.3mf, back.stl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]
2026-10-05 Site: Day 1 entry - slim rev A, smaller than a Charge 3, review corrections, new renders
2026-10-06 Case: two snap-together shells, ears swept out of the side walls, magnetic charging head
    - Top shell (frame + 0.3 mm lip, printed lip-face-down) and bottom shell click together on
    4 snap bumps (~46 N close, ~130 N open via end pry notches); TPU 90A radial seal ring.
    - No glue anywhere: bezel gasket, glass-corner cushions, pogo seals, motor pad, mic seal
    and the CF variant's PETG antenna/touch windows are all captured by the closed case
    (0.3 mm play check per part).
    - Strap ears are the case's side section carried past the end faces and sloping onto the
    bar: root section 5.6 mm^2 (was 3.6), ~2.5x the bending strength; 16 mm bars, 43.1 mm
    lug to lug; CORNER_R 1.6 in spec (corners sit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
    [antenna_window.3mf, antenna_window.stl, back.3mf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]
2026-10-06 RF v3: case modelled from the CAD solids; C11 0.3 -> 0.5 pF for the two-shell case
    case_stl.py exports the CAD's own shells, ears, TPU parts, strap, bars, battery, magnets and
    motor for sim.py, so the RF model can't drift from the CAD. The new case's extra plastic at
    the antenna end lowers the resonance ~1%; C11 0.5 pF / L3 1.2 nH gives -8.8..-15.7 dB in the
    case and -8.8..-14.4 dB on the wrist (worst in-band loss 0.81 dB vs 1.08 with 0.3 pF).
    [bottom_shell.stl, metal.stl, strap.stl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]
2026-10-06 Rev A: C11 0.5 pF (RF v3); README for the 6.80 mm two-shell case and magnetic cable
    ERC 0, DRC 0 errors / 0 warnings / 0 unconnected.
    [horae.kicad_pcb, horae.kicad_sch, horae.step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]
2026-10-06 Site: Day 2 entry - two snap-together shells, flowing strap ears, colourways, magnetic charger
2026-10-06 Site: interactive 3D explorer of rev A (exploded view, colourways, parts, chip labels)
    - explorer/: three.js viewer (CDN import map) of the real case CAD parts and the routed
    KiCad board: orbit/zoom, assembled / exploded / cutaway views with a pull-apart slider,
    the 8 real-filament colourways (CF texture, glitter, translucent TPU), strap/dock/label
    toggles, a parts list with info cards and "show only this", numbered chip hotspots.
    Lazy: loads when scrolled to on desktop, on tap on phones (~2 MB with three.js).
    - cad/web.py exports every part as one named meshopt-compressed GLB mesh (exact normals,
    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
2026-10-06 Day 3: charging dock, fewer printed parts, real battery wires
    - Dock replaces the cut-cable head: PETG tray + snap-in lid, 4 Mill-Max 0955
    pins, 4 keyed 3x3 N52 magnets, Adafruit 6050 sunken USB-C breakout; the
    watch's back sits 5.7 mm above the desk
    - Motor pad replaced by sprung fingers in the bottom shell, pogo seals are one
    piece, CF touch windows 2 instead of 4 (watch 14 -> 10 printed pieces, CF
    19 -> 13)
    - A1 mini print plates per filament in cad/out/plates (2 jobs, 3 for CF)
    - Battery leads modelled as 0.6 mm insulated wires (red +, black -)
    - Explorer: named dock parts with per-part explode, dock in the case colour,
    shadow on the desk, split battery leads; no 2 px overflow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
    [antenna_window.3mf, bezel_gasket.3mf, boot.3mf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]
2026-10-06 Captive watch magnets; printing notes
    - The case's 3x1 magnets click in from the inside past 3 detent bumps, behind a
    0.1 mm skin (the bottom shell's first layer), so the dock can't pull them out
    on lift-off. Hold drops 3.78 -> 3.20 N, 1.92x the 1.67 N pin force; the
    check is relaxed to 1.9x
    - Re-rendered the Day 3 images that show the magnets; shorter label so the
    exploded view's bottom-shell label fits
    - README: printing section (0.1 mm first layer for the PETG plate);
    hardware README and Day 3 entry: 1.9x hold, captive magnets, pole check
    [antenna_window.3mf, bezel_gasket.3mf, bottom_seal.3mf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]
2026-10-07 Pre-order review: board, case and RF reworked; order and assembly guides
    Four parallel reviews (schematic/parts, layout/fab, size, sourcing) found
    7 blockers, all fixed:
    - J1 faced the wrong way (FH34SRJ slot is on the fitting-nail side):
    turned, pins remapped (pad = 19 - display pin), moved +1.7 mm so the
    11.18 mm tail keeps GD's R > 0.5 bend
    - CPL now in the gerber frame with JLC rotation offsets (U4, L4)
    - TI's 0.23 mm NSMD lands for the BQ25101/TPS62840 WCSPs
    - no foreign traces under the touch electrodes (all layers), 510R series
    - RF match pads 0.15 mm apart, no paste on C12/AE1
    - ESP32 EP per Espressif: vias in the mask webs, none in the paste
    - 1-up 70 x 70 mm panel frame (panel.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
    [antenna_window.3mf, antenna_window.stl, bezel_gasket.3mf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]
